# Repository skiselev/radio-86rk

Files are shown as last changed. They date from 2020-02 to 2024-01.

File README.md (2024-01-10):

# Radio 86RK
Re-make of the Soviet Ham Radio computer published in Radio Magazine in 1986

## Hardware Documentation

## Table of Content
* [Introduction](#introduction)
* [Specifications](#specifications)
* [Project Notes](#project-notes)
* [Hardware Documentation](#hardware-documentation)
  * [Schematic and PCB Layout](#schematic-and-pcb-layout)
  * [Connectors](#connectors)
  * [Bill of Materials](#bill-of-materials)
  * [Memory Map](#memory-map)
* [Firmware Documentation](#firmware-documentation)
  * [Monitor](#monitor)
* [Release Notes](#release-notes)
  * [Changes](#changes)
  * [Known Issues](#known-issues)

## Introduction
This project is a remake of [Radio-86RK](https://en.wikipedia.org/wiki/Radio-86RK) - a soviet ham radio computer. The original design was published in Radio Magazine, an amateur radio and DIY electronics oriented publication, starting from [April 1986](Radio-86RK_Publications.md). Hence the "Radio" and "86" in the name ("RK" stands for ham radio computer).

The goal of the original design was to create a computer that can be built relatively easily and cheaply using commonly available components. Therefore it included several short-cuts. For example it didn't use 8228 bus controller. Instead, it uses */WR* and *DBIN* CPU signals instead to distinguish between write and read CPU cycles. Since the system doesn't decode I/O control signals, all the I/O devices are memory mapped. Another optimization is the use of DMA controller for both supplying the data to the CRT controller and for refreshing DRAMs. The system didn't support interrupts. The sound was implemented using *INTE* output of the CPU. The software would use **EI**/**DI** instructions to generate sound. There are no graphics capabilities. The font size was limited to 128 characters (8275 CRT controller limitation), and given that it had to support both Latin and Cyrillic ABCs, it only had capital letters for both ABCs. The CRT controller shares 16 MHz clock oscillator with the CPU (not uncommon in other home computers at that time period).

Despite the limitations, the design was fairly successful, many people have built this computer, and there are some that still building one, this project included. In addtion, several factories manufactured computers based on (but not always compatible with) this design - e.g. [Mikrosha](https://oldcomputer.info/8bit/mikrosha/index.htm), [Apogee BK-01](https://ru.wikipedia.org/wiki/%D0%90%D0%BF%D0%BE%D0%B3%D0%B5%D0%B9_%D0%91%D0%9A-01), and a few more.

### Specifications of the Original Design
  * KR580VM80A (Intel 8080) CPU @ 1.78 MHz (16 MHz divided by 9)
  * 16 KiB to 32 KiB DRAM, 2 KiB ROM (monitor software)
  * KR580VG75 (Intel 8275) CRT controller which works together with KR580VT57 (Intel 8257) DMA controller. 1 KiB ROM is used for font
  * Two KR580VV55A (Intel 8255A) PPIs. One is used for keyboard and cassette I/O, another one for the extension port
  * Normally the computer consisted of 2 or 3 PCBs - the mainboard, the keyboard, and the keypad.

### Modifications to the Original Design
 * 16 DRAM ICs replaced with a single 32 KiB SRAM IC
 * Font ROM size increased to 2 KiB, so that it fits an alternative font. CRT controller GPA0 attribute is used to switch between fonts.
 * Reverse video attribute implemented in CRT controller
 * Added 8251 USART and 8253 timer. The timer is used for dividing the clock for USART and for sound generation.
 * Single board design, including an integrated mechanical keyboard
 * The work is largely based on [Radio-86RК-SRAM](http://radio86rk.pbworks.com/w/page/58467718/Radio-86R%D0%9A-SRAM) project created by Alexey Khudyakov (alexcp).

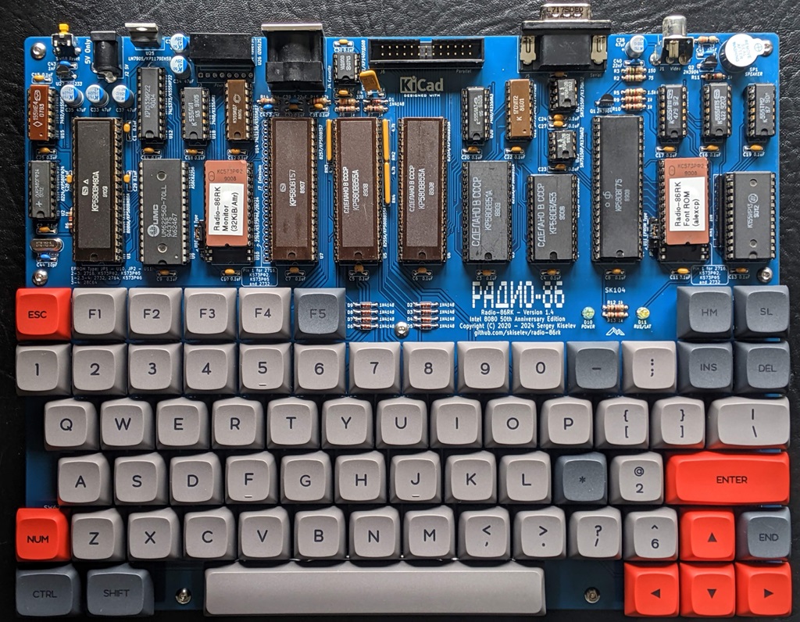
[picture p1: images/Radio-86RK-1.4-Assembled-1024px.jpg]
Radio-86RK


## Specifications
* Processor: Intel 8080A / КР580ВМ80А CPU running at 1.78 MHz
* Memory:
  * RAM: 32 KiB SRAM
  * ROM: 2 KiB UV EPROM with system monitor software
* Video: Intel 8275 / КР580ВГ75 CRT Controller
  * Alphanumeric display
  * 2 KiB UV EPROM with font
  * Composite video output (50 Hz)
* Audio:
  * Intel 8253 / КР580ВИ53 (single channel)
  * CPU INTE output
* Parallel Interface:
  * Intel 8255А / КР580ВВ55А PPI
  * 26-pin expansion header
* Serial Interface:
  * Intel 8251А / КР580ВВ51А USART
  * DE-9 connector
* Built-in 67-keys keyboard
* Cassette recorder interface

## Project Notes

Check [Project Notes](Project_Notes.md) for the information about building this project

## Hardware Documentation

### Documentation for the Previous Versions

* [Version 1.3](https://github.com/skiselev/radio-86rk/tree/v1.3)
* [Version 1.2](https://github.com/skiselev/radio-86rk/tree/v1.2)
* [Version 1.1](https://github.com/skiselev/radio-86rk/tree/v1.1)

### Schematic and PCB Layout

* [Schematic - Version 1.4](KiCad/Radio-86RK-Schematic-1.4.pdf)
* [PCB Layout - Version 1.4](KiCad/Radio-86RK-Board-1.4.pdf)

### Connectors

#### J1 - Composite Video

Pin | Description     
--- | ---------------
Tip (the inner contact) | Output: Composite Video
Ring / Sleeve         |	Power: GND

#### J2 - Power (5V)
Connect regulated +5V power supply to this connector.

Note: The 8080A CPU, clock generator, and serial port transmitters and receivers use +12V/-5V/-12V voltages. An on-board DC-DC converter (U26) is used to obtain these voltages. Instead of using the DC-DC converter it is possible to provide these voltages directly to the system using J3 connector.

Pin | Description     
--- | ---------------
Tip (the inner contact) | Power: 5V (positive terminal)
Barrel / Sleeve         |	Power: GND (negative terminal)

#### J3 - Power (5V, 12V, -12V)
Connect regulated 5V/12V/-12V power supply to this connector.

Pin | Description     
--- | ---------------
1, 2, 3 | Power: GND
4, 5, 6 |	Power: 5V
7   |	Power: 12V
8   |	Power: -12V

#### J4 - Cassette Connector
Pin | Description     
--- | ---------------
1, 2, 3, 8   | Power: GND
4   |	Output: Sound output to cassette recorder (line level)
5   |	Input: Sound input from cassette recorder (line level)
6, 7 |	Not connected

#### J5 - Serial Port Connector
Pin | Description     
--- | ---------------
1   | Not connected: DCD
2   | Input: RX
3   | Output: TX
4   | Output: DTR
5   | Power: GND
6   | Input: DSR
7   | Output: RTS
8   | Input: CTS
9   | Not connected: RI

#### J6 - Parallel Port Connector
Pin | Description | Pin | Description
--- | ----------- | --- | ----------------
1   | Output: PC0 | 2   | Input: PA0
3   | Output: PC1 | 4   | Input: PA1
5   | Output: PC2 | 6   | Input: PA2
7   | Output: PC3 | 8   | Input: PA3
9   | Output: PC4 | 10  | Input: PA4
11  | Output: PC5 | 12  | Input: PA5
13  | Output: PC6 | 14  | Input: PA6
15  | Output: PC7 | 16  | Input: PA7
17  | Output: PB7 | 18  | Output: PB0
19  | Output: PB6 | 20  | Output: PB1
21  | Output: PB5 | 22  | Output: PB2
23  | Output: PB4 | 24  | Output: PB3
25  | Power: +5V  | 26  | Power: GND

### Bill of Materials

* [Radio-86RK project on Mouser.com](https://www.mouser.com/ProjectManager/ProjectDetail.aspx?AccessID=d3d8f92a02) - View and order all components except of the PCB, and most Intel 8xxx ICs.

* [Unicorn Electronics](https://www.unicornelectronics.com/prod.htm) is a good source for Intel 8xxx or compatible ICs, 7400-series TTL ICs, and 74LS00-series TTL-LS ICs

Component type     | Reference | Description                                 | Quantity | Possible sources and notes
------------------ | --------- | ------------------------------------------- | -------- | --------------------------
PCB                |           | Radio-86RK PCB                              | 1        | Buy from my Tindie store: [Radio-86RK - PCB](https://www.tindie.com/products/weird/radio-86rk-pcb/) or order from a PCB manufacturer of your choice using provided Gerber or KiCad files
Capacitor          | C1 - C32  | 0.1 uF, MLCC, 5 mm Pitch                    | 32       | Mouser [594-K104K15X7RF53H5](https://www.mouser.com/ProductDetail/594-K104K15X7RF53H5)
Capacitor          | C33 - C38 | 47 uF, 25V, Electrolytic or Organic Polymer | 6 	      | Mouser [80-A750EK476M1EAAE40](https://www.mouser.com/ProductDetail/80-A750EK476M1EAAE40)
Capacitor          | C39       | 0.22 uF, MLCC, 5 mm Pitch                   | 1        | Mouser [810-FG24X7R1H224KNT0](https://www.mouser.com/ProductDetail/810-FG24X7R1H224KNT0)
Capacitor          | C40       | 22 nF, MLCC, 5 mm Pitch                     | 1        | Mouser [810-FG28X7R1H223KNT0](https://www.mouser.com/ProductDetail/810-FG28X7R1H223KNT0)
Capacitor          | C41       | 10 nF, MLCC, 5 mm Pitch                     | 1        | Mouser [810-FG28X7R1H103KNT0](https://www.mouser.com/ProductDetail/810-FG28X7R1H103KNT0)
Capacitor          | C42       | 2.2 nF, MLCC, 5 mm Pitch                    | 1        | Mouser [810-FG28X7R1H222KNT0](https://www.mouser.com/ProductDetail/810-FG28X7R1H222KNT0)
Capacitor          | C43       | 1 nF, MLCC, 5 mm Pitch                      | 1        | Mouser [810-FG28C0G1H102JNT6](https://www.mouser.com/ProductDetail/810-FG28C0G1H102JNT6)
Capacitor          | C44       | 10 pF, MLCC, 5 mm Pitch                     | 1        | Mouser [810-FG28C0G1H100DNT00](https://www.mouser.com/ProductDetail/810-FG28C0G1H100DNT0)
Diode              | D1 - D9  | 1N4148                                       | 9        | Mouser [512-1N4148](https://www.mouser.com/ProductDetail/512-1N4148)
LED                | D10       | LED Indicator, 3 mm, Green                  | 1        | Mouser [630-HLMP-1503-C0002](https://www.mouser.com/ProductDetail/630-HLMP-1503-C0002)
LED                | D11       | LED Indicator, 3 mm, Yellow                 | 1        | Mouser [630-HLMP-1401](https://www.mouser.com/ProductDetail/630-HLMP-1401)
Polyfuse           | F1        | 1.1A, 5 mm Pitch                            | 1        | Mouser [576-16R110BU](https://www.mouser.com/ProductDetail/576-16R110BU)
Connector          | JP1, JP2  | 4 pin header, 2.54 mm Pitch                 | 2        | Mouser [649-68000-204HLF](https://www.mouser.com/ProductDetail/649-68000-204HLF)
Connector          | JP1, JP2  | Jumper, 2.54 mm Pitch                       | 4        | Mouser [806-SX1100-B)](https://www.mouser.com/ProductDetail/806-SX1100-B)
Connector          | J1        | RCA Phono connector, Yellow                 | 1        | Mouser [490-RCJ-014](https://www.mouser.com/ProductDetail/490-RCJ-014)
Connector          | J2        | DC Power Jack, 2mm                          | 1        | Mouser [806-KLDX-0202-A](https://www.mouser.com/ProductDetail/806-KLDX-0202-A)
Connector          | J3        | 8 pin friction lock connector               | 1        | Mouser [571-6404568](https://www.mouser.com/ProductDetail/571-6404568)
Connector          | J4        | DIN 8-pos, Right Angle, PCB mount           | 1        | Mouser [490-SDF-80J](https://www.mouser.com/ProductDetail/490-SDF-80J)
Connector          | J5        | Sub-D DE9M, Right Angle, PCB mount          | 1        | Mouser [523-L717SDE09P1ACH3R](https://www.mouser.com/ProductDetail/523-L717SDE09P1ACH3R)
Connector          | J6        | 13x2 pin header, shrouded                   | 1        | Mouser [517-30326-6002](https://www.mouser.com/ProductDetail/517-30326-6002)
Connector          | J7        | 20x1 pin socket                             | 1        | Mouser [517-929850-01-20-RB](https://www.mouser.com/ProductDetail/517-929850-01-20-RB). Note: Optional, for extension board connection
Transistor         | Q1, Q2    | 2N3904                                      | 2        | Mouser [512-2N3904TA](https://www.mouser.com/ProductDetail/512-2N3904TA)
Resistor           | R1        | 33 ohm                                      | 1        | Mouser [660-CF1/4CT52R330J](https://www.mouser.com/ProductDetail/660-CF1-4CT52R330J)
Resistor           | R2        | 75 ohm                                      | 1        | Mouser [660-CF1/4CT52R750J](https://www.mouser.com/ProductDetail/660-CF1-4CT52R750J)
Resistor           | R3        | 150 ohm                                     | 1        | Mouser [660-CF1/4CT52R151J](https://www.mouser.com/ProductDetail/660-CF1-4CT52R151J)
Resistor           | R4        | 330 ohm                                     | 1        | Mouser [660-CF1/4CT52R331J](https://www.mouser.com/ProductDetail/660-CF1-4CT52R331J)
Resistor           | R5        | 1.5 k                                       | 1        | Mouser [660-CF1/4CT52R152J](https://www.mouser.com/ProductDetail/660-CF1-4CT52R152J)
Resistor           | R6 - R13  | 1 k                                         | 8        | Mouser [660-CF1/4CT52R102J](https://www.mouser.com/ProductDetail/660-CF1-4CT52R102J)
Resistor           | R14       | 2.4 k                                       | 1        | Mouser [660-CF1/4CT52R242J](https://www.mouser.com/ProductDetail/660-CF1-4CT52R242J)
Resistor           | R15       | 12 k                                        | 1        | Mouser [660-CF1/4CT52R123J](https://www.mouser.com/ProductDetail/660-CF1-4CT52R123J)
Resistor Array     | RN1       | 10 k, SIP10                                 | 1        | Mouser [652-4610X-1LF-10K](https://www.mouser.com/ProductDetail/652-4610X-1LF-10K)
Resistor Array     | RN2 - RN4 | 4.7 k, SIP6                                 | 3        | Mouser [652-4606X-1LF-4.7K](https://www.mouser.com/ProductDetail/652-4606X-1LF-4.7K)
Speaker            | SP1       | 12 mm speaker                               | 1        | Mouser [665-AT-1224TWTR](https://www.mouser.com/ProductDetail/665-AT-1224TWTR)
Keyboard Switch    | SW1 - SW67 | Cherry MX Blue (Clicky)                    | 67       | Mouser [540-MX1A-E1NW](https://www.mouser.com/ProductDetail/540-MX1A-E1NW)
Switch Leveling Kit | SW11, SW64 | Leveling kit for MX 1x2, 1x2.25, 1x2.75   | 2        | Mouser [540-G99-0742](https://www.mouser.com/ProductDetail/540-G99-0742)
Switch Leveling Kit | SW64     | Leveling kit for MX 1x8                     | 1        | Mouser [540-G99-0226](https://www.mouser.com/ProductDetail/540-G99-0226) Note: Use the wire from this part and one of 540-G99-0742 to build a through hole leveling kit for the spacebar
Tactile Switch     | SW68      | 6 mm Tactile Switch Right Angle             | 1        | Mouser [653-B3F-3152](https://www.mouser.com/ProductDetail/653-B3F-3152)
Switch Keycap      | SW68      | 4 x 4 mmm Tactile Switch Key Cap, Orange    | 1        | Mouser [653-B32-1020](https://www.mouser.com/ProductDetail/653-B32-1020)
Integrated Circuit | U1        | Intel 8080A / КР580ВМ80А, CPU               | 1        | Unicorn Electronics [8080A](https://www.unicornelectronics.com/IC/8000.html), Jameco [52046](https://www.jameco.com/z/8080A-Major-Brands-IC-8080A-8-Bit-MOS-MPU_52046.html)
Integrated Circuit | U2        | Intel 8224 / КР580ГФ24, Clock Generator     | 1        | Unicorn Electronics [8224](https://www.unicornelectronics.com/IC/8000.html)
Integrated Circuit | U3        | Intel 8251А / КР580ВВ51А, USART             | 1        | Unicorn Electronics [8251A](https://www.unicornelectronics.com/IC/8000.html)
Integrated Circuit | U4        | Intel 8253 / КР580ВИ53, PIT                 | 1        | Unicorn Electronics [8253](https://www.unicornelectronics.com/IC/8000.html), Mouser [968-CP82C54Z](https://www.mouser.com/ProductDetail/968-CP82C54Z)
Integrated Circuit | U5, U6    | Intel 8255А / КР580ВВ55А, PPI               | 2        | Unicorn Electronics [8055A](https://www.unicornelectronics.com/IC/8000.html), Mouser [968-CP82C55A-5Z](https://www.mouser.com/ProductDetail/968-CP82C55A-5Z), Jameco [52732](https://www.jameco.com/z/8255A-5-Major-Brands-IC-8255A-5-Programmable-Peripheral-Interface-40-pin-DIP_52732.html)
Integrated Circuit | U7        | Intel 8257 / КР580ВТ57, DMA Controller      | 1        | Unicorn Electronics [8257](https://www.unicornelectronics.com/IC/8000.html)
Integrated Circuit | U8        | Intel 8275 / КР580ВГ75, CRT Controller      | 1        | Unicorn Electronics [8275](https://www.unicornelectronics.com/IC/8000.html), Jameco [52821](https://www.jameco.com/z/8275-Major-Brands-Programmable-CRT-Controller-DIP-40_52821.html)
Integrated Circuit | U9        | AS6C62256, SRAM 32Kx8                       | 1        | Mouser [913-AS6C62256-55PCN](https://www.mouser.com/ProductDetail/913-AS6C62256-55PCN), Unicorn Electronics [62256LP](https://www.unicornelectronics.com/IC/STATIC.html)
Integrated Circuit | U10, U11  | 2716 / КР573РФ5, 2Kx8 EPROM                 | 2        | Mouser [556-AT28C64B15PU](https://www.mouser.com/ProductDetail/556-AT28C64B15PU), Unicorn Electronics [2716](https://www.unicornelectronics.com/IC/EPROM.html). Note: 2716, 2732, 2764, 27C64 EPROMs, or 28C64 EEPROMs can be used
Integrated Circuit | U12       | 74LS373/К555ИР22, 8-bit Latch, 3-state outputs | 1     | Mouser [595-SN74LS373N](https://www.mouser.com/ProductDetail/595-SN74LS373N)
Integrated Circuit | U13       | 74198/К155ИР13, 8-bit Shift Register        | 1        | Unicorn Electronics [74198](https://www.unicornelectronics.com/IC/7400.html)
Integrated Circuit | U14       | 74LS138/К555ИД7, Decoder 3 to 8 active low outputs | 1 | Mouser [595-SN74LS138N](https://www.mouser.com/ProductDetail/595-SN74LS138N), Unicorn Electronics [74LS138](https://www.unicornelectronics.com/IC/74LS.html)
Integrated Circuit | U15       | 7492/К155ИЕ4, Divide by 12 counter          | 1        | Mouser [595-SN74LS92N](https://www.mouser.com/ProductDetail/595-SN74LS92N), Unicorn Electronics [74LS92](https://www.unicornelectronics.com/IC/74LS.html)
Integrated Circuit | U16       | 7486/К155ЛП5, Quad 2-input XOR              | 1        | Mouser [595-SN74LS86AN](https://www.mouser.com/ProductDetail/595-SN74LS86AN), Unicorn Electronics [74LS86](https://www.unicornelectronics.com/IC/74LS.html)
Integrated Circuit | U17       | 7474/К155ТМ2, Dual D Flip-flop, Set & Reset | 1        | Mouser [595-SN74LS74AN](https://www.mouser.com/ProductDetail/595-SN74LS74AN), Unicorn Electronics [74LS74](https://www.unicornelectronics.com/IC/74LS.html)
Integrated Circuit | U18       | 7408/К155ЛИ1, Quad 2-input AND              | 1        | Mouser [595-SN74LS08N](https://www.mouser.com/ProductDetail/595-SN74LS08N), Unicorn Electronics [74LS08](https://www.unicornelectronics.com/IC/74LS.html)
Integrated Circuit | U19       | 7404/К155ЛН1, Hex Inverter                  | 1        | Mouser [595-SN74LS04N](https://www.mouser.com/ProductDetail/595-SN74LS04N), Unicorn Electronics [74LS04](https://www.unicornelectronics.com/IC/74LS.html)
Integrated Circuit | U20       | 7400/К155ЛА3, Quad 2-input NAND             | 1        | Mouser [595-SN74LS00N](https://www.mouser.com/ProductDetail/595-SN74LS00N), Unicorn Electronics [74LS00](https://www.unicornelectronics.com/IC/74LS.html)
Integrated Circuit | U21       | TL071/К140УД6, Operational Amplifier        | 1        | Mouser [595-TL071IP](https://www.mouser.com/ProductDetail/595-TL071IP)
Integrated Circuit | U22       | SN75154N/К170УП2В, Quad RS-232 Receiver     | 1        | Mouser [595-SN75154N](https://www.mouser.com/ProductDetail/595-SN75154N), Unicorn Electronics [75154](https://www.unicornelectronics.com/IC/INTERFACE.html)
Integrated Circuit | U23, U24  | SN75150P/К170АП2, Dual RS-232 Driver        | 2        | Mouser [595-SN75150P](https://www.mouser.com/ProductDetail/595-SN75150P), Unicorn Electronics [75150](https://www.unicornelectronics.com/IC/INTERFACE.html)
Integrated Circuit | U25       | LM7905/КР1179ЕНВ, Negative 5V 1A Linear Regulator | 1  | Mouser [926-LM7905CT-NOPB](https://www.mouser.com/ProductDetail/926-LM7905CT-NOPB), Unicorn Electronics [7905T](https://www.unicornelectronics.com/IC/VOLT.html)
DC-DC Converter    | U26       | IZ0512, +/-12V +/-125mA, 4.5V-9V input      | 1        | Mouser [209-IZ0512S](https://www.mouser.com/ProductDetail/209-IZ0512S)
Integrated Circuit | U27       | DS1233-5, CPU Supervisory Circuit           | 1        | Mouser [700-DS1233-5T&R](https://www.mouser.com/ProductDetail/700-DS1233-5TR)
Crystal            | Y1        | 16 MHz, Series, HC-49U                      | 1        | Mouser [774-ATS160-E](https://www.mouser.com/ProductDetail/774-ATS160-E)
IC Socket          | U1, U5, U6, U7, U8 | 40 pin DIP                         | 5        | Mouser [649-DILB40P223TLF](https://www.mouser.com/ProductDetail/649-DILB40P223TLF), [517-4840-6000-CP](https://www.mouser.com/ProductDetail/517-4840-6000-CP)
IC Socket          | U3, U9, U10, U11    | 28 pin DIP                                  | 4        | Mouser [649-DILB28P223TLF](https://www.mouser.com/ProductDetail/649-DILB28P223TLF), [517-4828-6000-CP](https://www.mouser.com/ProductDetail/517-4828-6000-CP)
IC Socket          | U4, U13   | 24 pin DIP                          | 2        | Mouser [649-DILB24P-223TLF](https://www.mouser.com/ProductDetail/649-DILB24P-223TLF), [517-4824-6000-CP](https://www.mouser.com/ProductDetail/517-4824-6000-CP)
IC Socket          | U12       | 20 pin DIP                                  | 1        | Mouser [649-DILB20P-223TLF](https://www.mouser.com/ProductDetail/649-DILB20P-223TLF), [517-4820-3000-CP](https://www.mouser.com/ProductDetail/517-4820-3000-CP)
IC Socket          | U2, U14, U22 | 16 pin DIP                               | 3        | Mouser [649-DILB16P-223TLF](https://www.mouser.com/ProductDetail/649-DILB16P-223TLF), [517-4816-3000-CP](https://www.mouser.com/ProductDetail/517-4816-3000-CP)
IC Socket          | U15 - U20 | 14 pin DIP                                  | 6        | Mouser [649-DILB14P-223TLF](https://www.mouser.com/ProductDetail/649-DILB14P-223TLF), [517-4814-3000-CP](https://www.mouser.com/ProductDetail/517-4814-3000-CP)
IC Socket          | U21, U23, U24 | 8 pin DIP                               | 3        | Mouser [649-DILB8P223TLF](https://www.mouser.com/ProductDetail/649-DILB8P223TLF), [517-4808-3000-CP](https://www.mouser.com/ProductDetail/517-4808-3000-CP)

### Memory Map
* 0000h - 7FFFh - SRAM
  * 7600h - 7FFFh - Display buffer and monitor variables
* 8000h - 8FFFh - 8255A PPI (Keyboard, Cassette recorder, Sound control)
  * 8000h - Channel A data
  * 8001h - Channel B data
  * 8002h - Channel C data
  * 8003h - Control word
* 9000h - 9FFFh - 8253 Timer (USART Clock, Sound)
  * 9000h - Channel 0 count
  * 9001h - Channel 1 count
  * 9002h - Channel 2 count
  * 9003h - Control word
* 0A000h - 0AFFFh - 8255A PPI (Parallel Interface)
  * 0A000h - Channel A data
  * 0A001h - Channel B data
  * 0A002h - Channel C data
  * 0A003h - Control word
* 0B000h - 0BFFFh - 8251A USART
  * 0B000h - Data register
  * 0B001h - Command register
* 0C000h - 0CFFFh - 8275 CRT Controller
* 0D000h - 0DFFFh - Unused
* 0E000h - 0EFFFh - 8257 DMA Controller (write only)
* 0E000h - 0FFFFh - Monitor EPROM (read only)

## Firmware Documentation

### Monitor

#### Monitor Commands
* Memory Operations
  * **D\<Start_Address\>,\<End_Address\>** - Display memory content in hexadecimal
  * **L\<Start_Address\>,\<End_Address\>** - Display memory content in ASCII
  * **F\<Start_Address\>,\<End_Address\>,\<Value\>** - Fill memory with the specified value
  * **M\<Address\>** - Modify memory content
  * **T\<Start_Address\>,\<End_Address\>,\<Destination_Start_Address\>** - Copy memory block to destination
  * **C\<Start_Address\>,\<End_Address\>,\<Destination_Start_Address\>** - Compare memory block with destination
  * **S\<Start_Address\>,\<End_Address\>,\<Value\>** - Search memory for a value
  * **R\<ROM_Start_Address\>,\<ROM_End_Address\>,\<Destination_Start_Address\>** - Read from the ROM connected to the Parallel interface to memory
* Run Control
  * **G\<Start_Address\>\[,End_Address\]** - Run code, optionally stop at the specified address
  * **X** - Display and modify registers
* Cassette Input/Output
  * **O\<Start_Address\>,\<End_Address\>\[,Speed\]** - Write memory to cassette. Default speed is 1Dh / 1200 bps
  * **I\[Offset\]\[,Speed\]** - Read data from to cassette memory at specified offset

#### Monitor Subroutines:
* 0F803h - Keyboard input
  * Input: None
  * Output: A - character code read from keyboard
* 0F806h - Cassette input
  * Input: A=0FFh - with sync; A=08h - no sync
  * Output: A - data read from cassette
* 0F809h - Print character to screen
  * Input: C - character to print
* 0F80Ch - Cassette output
  * Input: C - data to write
* 0F812h - Query keyboard
  * Output: A=00h - key not pressed; A=0FFh - key pressed
* 0F815h - Print to screen in hex
  * Input: A - data to print
* 0F818h - Print string
  * Input: HL - string address
* 0F81Bh - Get key
  * Output: A=0FFh - key not pressed; A=0FEh - Rus/Lat; otherwise A - key code
* 0F81Eh - Get cursor position
  * Output: H - row, L - column
* 0F821h - Read character from screen at current cursor position
  * Output: A - char read from screen
* 0F824h - Read from cassette
  * Input: HL - offset of memory buffer to store data to
  * Output: HL - start; DE - end; BC - checksum

## Release Notes

### Changes
* Version 1.4
  * Change keyboard layout to QWERTY
  * Add the J7 extension connector
  * Add support for 2732, 2764 and 27C64 EPROMs and 28C64 EEPROM.

* Version 1.3
  * Fix issues from version 1.1 and version 1.2:
    * Use key labels "Ь X" and "СС SHIFT" on top silkscreen
    * Video signal generation circuit: use R2 = 75 Ohm and R5 = 1.5 kOhm
    
* Version 1.2
  * Add F5 key
  * Add copyright year on the top silkscreen

* Version 1.1
  * Fix all known issues of version 1.0
  * Use DS1233-5 mircoprocessor supervisor to generate reset signal
  * Implement reverse video attribute

* Version 1.0
  * Initial version

### Known Issues
* Version 1.3
  * No known issues

* Version 1.2
  * Top silkscreen: "Ь" and "X" key labels are swapped
  * Top silkscreen: More correct translation for "СС" is "SHIFT"
  * Video signal generation: Produced video Vpp and the backporch levels are a bit too high. Use R2 = 75 to 100 Ohm, and R5 = 1.5 kOhm for proper video signal levels (Reported by Martin Lukasek)
* Version 1.1
  * Top silkscreen: "Ь" and "X" key labels are swapped
  * Top silkscreen: More correct translation for "СС" is "SHIFT"
  * Top silkscreen: No copyright year
  * Video signal generation: Produced video Vpp and the backporch levels are a bit too high. Use R2 = 75 to 100 Ohm, and R5 = 1.5 kOhm for proper video signal levels (Reported by Martin Lukasek)

* Version 1.0
  * 8224 (U2) should use DIP-16 footprint
  * Down and Right buttons swapped
  * Reset RC does not provide enough time for the system to properly reset at power-on

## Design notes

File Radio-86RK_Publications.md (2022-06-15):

# Radio Magazine - Radio 86RK Publications

## Table of Content

* [Radio 1985, Issue 1](#radio-1985-issue-1)
  * [BASIC For Micro-80, Part 1](#basic-for-micro-80-part-1)
* [Radio 1985, Issue 2](#radio-1985-issue-2)
  * [BASIC For Micro-80, Part 2](#basic-for-micro-80-part-2)
* [Radio 1985, Issue 3](#radio-1985-issue-3)
  * [BASIC For Micro-80, Part 3](#basic-for-micro-80-part-3)
* [Radio 1986, Issue 3](#radio-1986-issue-3)
  * [BASIC Programming](#basic-programming)
* [Radio 1986, Issue 4](#radio-1986-issue-4)
  * [Computer Architecture](#computer-architecture)
* [Radio 1986, Issue 5](#radio-1986-issue-5)
  * [CPU](#cpu)
  * [Memory and I/O Address Decode, RAM, Mainboard Schematic](#memory-and-io-address-decode-ram-mainboard-schematic)
  * [DMA Controller, CRT Controller, Sound Generation](#dma-controller-crt-controller-sound-generation)
* [Radio 1986, Issue 6](#radio-1986-issue-6)
  * [Keyboard PCB Layout](#keyboard-pcb-layout)
  * [Mainboard PCB Layout](#mainboard-pcb-layout)
  * [Keyboard](#keyboard)
  * [Font ROM Hex Dump, Keyboard Schematic](#font-rom-hex-dump-keyboard-schematic)
  * [Keyboard Layout, Cassette Tape Recorder Interface, Power Supply](#keyboard-layout-cassette-tape-recorder-interface-power-supply)
* [Radio 1986, Issue 8](#radio-1986-issue-8)
  * [Software, ROM Monitor Boot, ROM Monitor CLI, ROM Monitor Memory Commands](#software-rom-monitor-boot-rom-monitor-cli-rom-monitor-memory-commands)
  * [ROM Monitor Hex Dump](#rom-monitor-hex-dump)
  * [ROM Monitor Run and Debug Commands, ROM Monitor I/O Commands](#rom-monitor-run-and-debug-commands-rom-monitor-io-commands)
  * [ROM Monitor Subroutines](#rom-monitor-subroutines)
* [Radio 1986, Issue 9](#radio-1986-issue-9)
  * [Software - ROM Monitor Changes for 32 KiB RAM, Keyboard Notes, Display Control Codes ](#software---rom-monitor-changes-for-32-kib-ram-keyboard-notes-display-control-codes)
* [Radio 1986, Issue 11](#radio-1986-issue-11)
  * [Power Supply - Schematic and Design Description](#power-supply---schematic-and-design-description)
* [Radio 1986, Issue 12](#radio-1986-issue-12)
  * [Power Supply - PCB and Assembly Instructions](#power-supply---pcb-and-assembly-instructions)
  * [Assembly Notes and Errata](#assembly-notes-and-errata)
* [Radio 1987, Issue 1](#radio-1987-issue-1)
  * [BASIC Interpreter](#basic-interpreter)
* [Radio 1987, Issue 2](#radio-1987-issue-2)
  * [BASIC Games - Intersceptor, Joystick-like Control](#basic-games---intersceptor-joystick-like-control)
  * [BASIC Games - Python/Snake](#basic-games---pythonsnake)
* [Radio 1987, Issue 3](#radio-1987-issue-3)
  * [BASIC Games - Fox Hunt](#basic-games---fox-hunt)
  * [ROM cartridge for BASIC Interpreter](#rom-cartridge-for-basic-interpreter)
* [Radio 1987, Issue 4](#radio-1987-issue-4)
  * [Programming Radio-86RK, Python/Snake Game](#programming-radio-86rk-pythonsnake-game)
  * [Cassette Tape Recorder Input / Output](#cassette-tape-recorder-input--output)
* [Radio 1987, Issue 5](#radio-1987-issue-5)
  * [Reference Tables - Intel 8080A (KR580VM80A) Instruction Set, Character Set](#reference-tables---intel-8080a-kr580vm80a-instruction-set-character-set)
  * [Replacing Intel 8275 (KR580VG75) with Discrete Logic](#replacing-intel-8275-kr580vg75-with-discrete-logic)
* [Radio 1987, Issue 11](#radio-1987-issue-11)
  * [Using Intel 8253 (KR580VI53) as a Sound Generator](#using-intel-8253-kr580vi53-as-a-sound-generator)
* [Radio 1989, Issue 6](#radio-1989-issue-6)
  * [Serial Interface Controller Based on Intel 8251A (KR580VV51A) - Design Description, Schematic and PCB Layout](#serial-interface-controller-based-on-intel-8251a-kr580vv51a---design-description-schematic-and-pcb-layout)
* [Radio 1989, Issue 7](#radio-1989-issue-7)
  * [Serial Interface Controller Based on Intel 8251A (KR580VV51A) - Software Subroutines](#serial-interface-controller-based-on-intel-8251a-kr580vv51a---software-subroutines)

## Radio 1985, Issue 1

### BASIC For Micro-80, Part 1

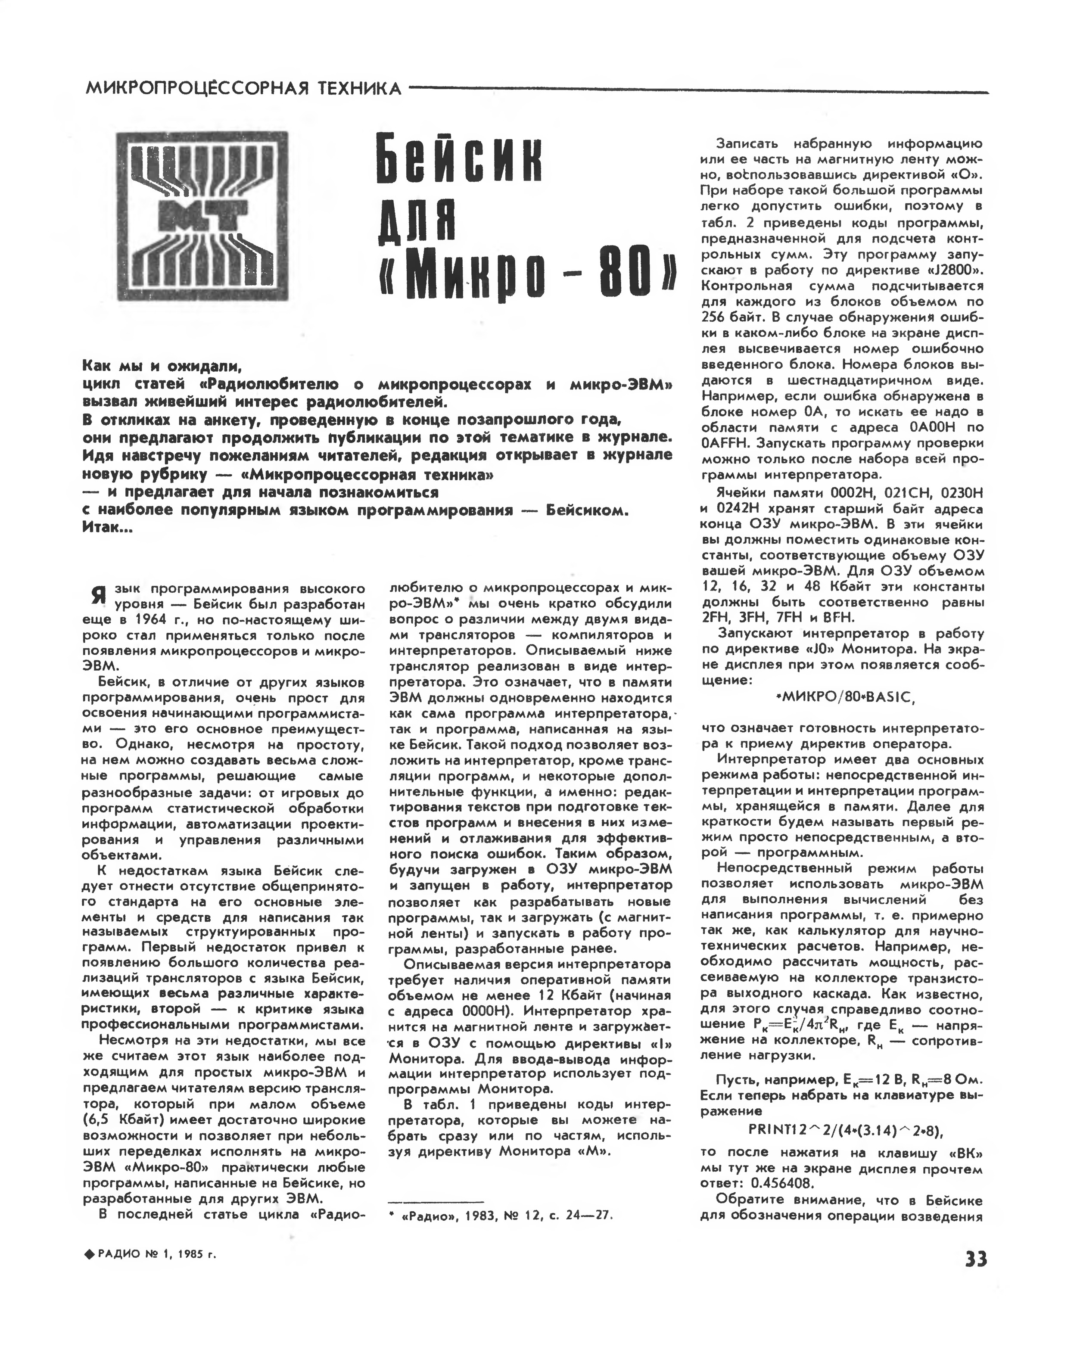
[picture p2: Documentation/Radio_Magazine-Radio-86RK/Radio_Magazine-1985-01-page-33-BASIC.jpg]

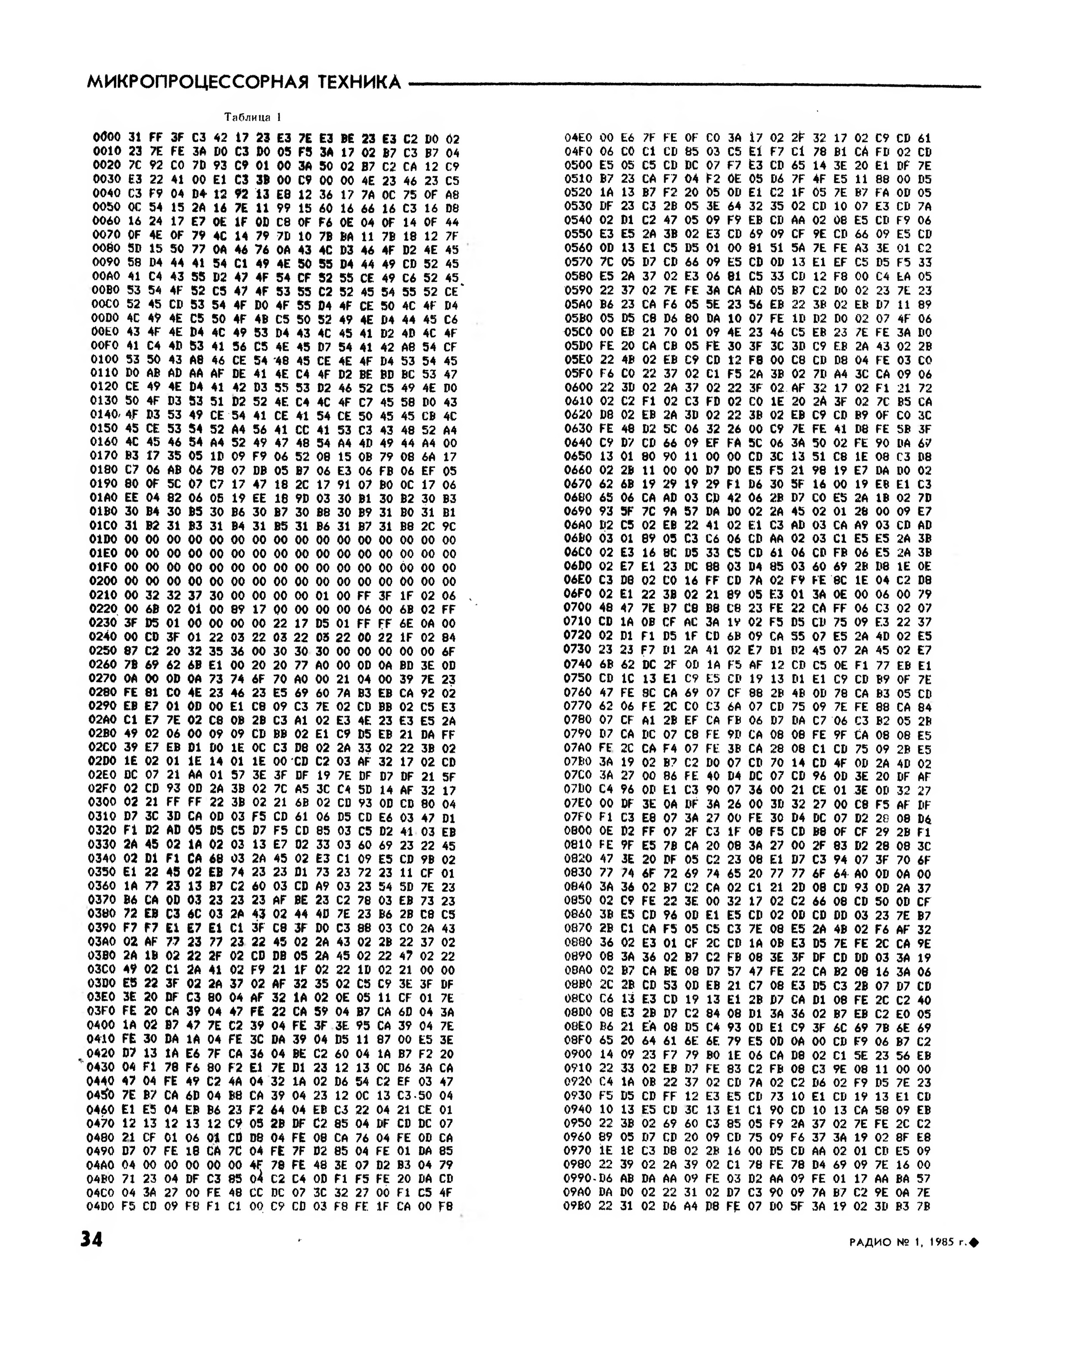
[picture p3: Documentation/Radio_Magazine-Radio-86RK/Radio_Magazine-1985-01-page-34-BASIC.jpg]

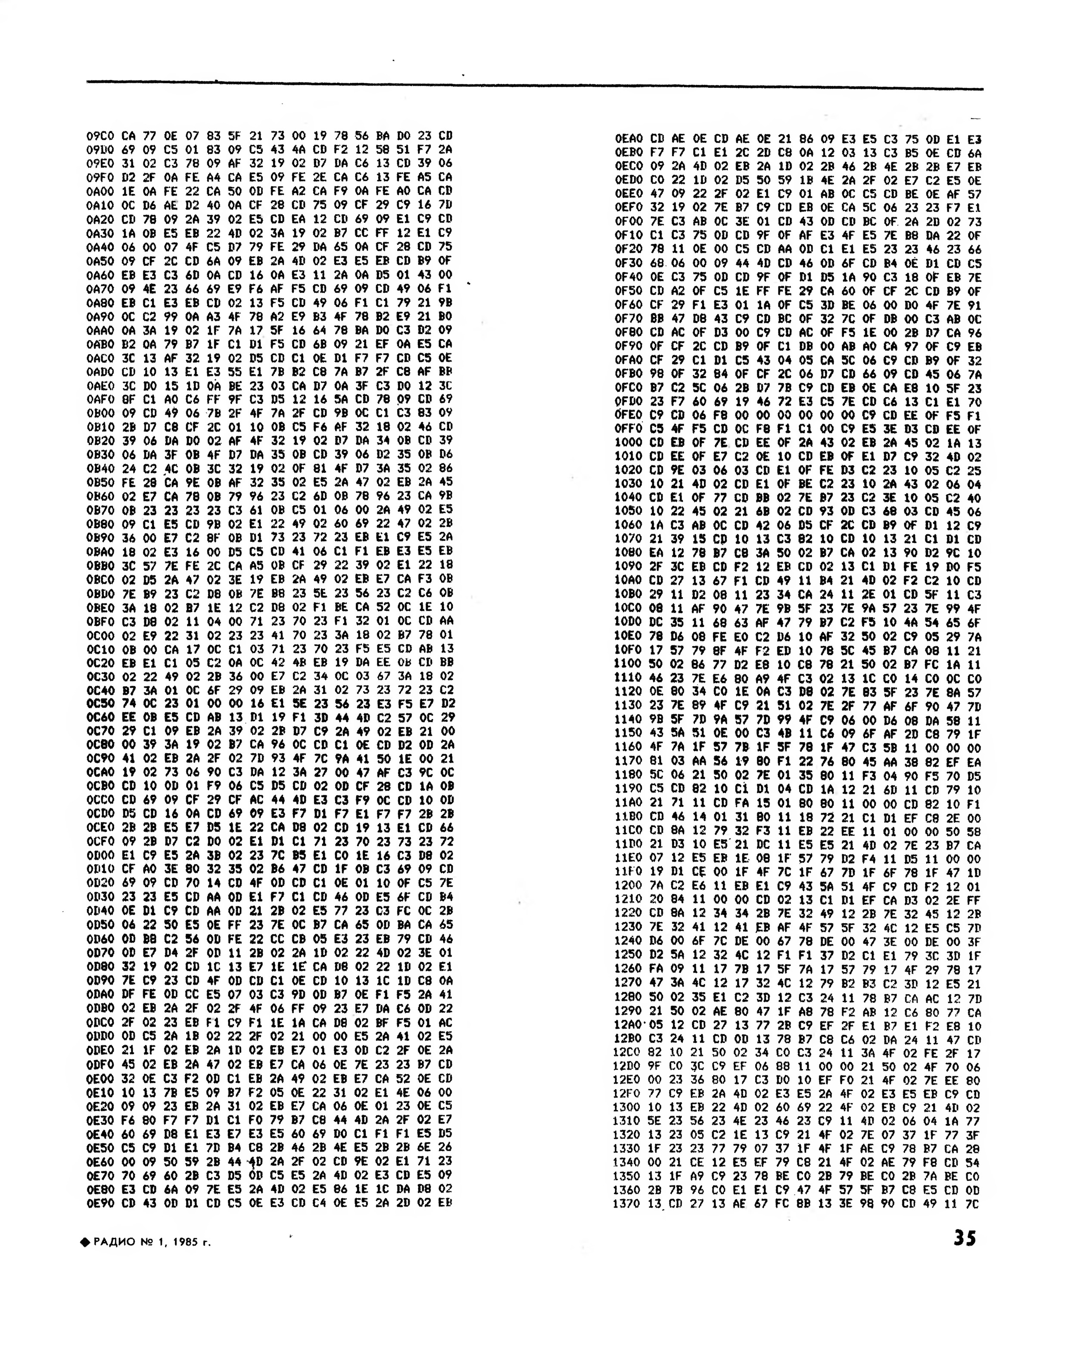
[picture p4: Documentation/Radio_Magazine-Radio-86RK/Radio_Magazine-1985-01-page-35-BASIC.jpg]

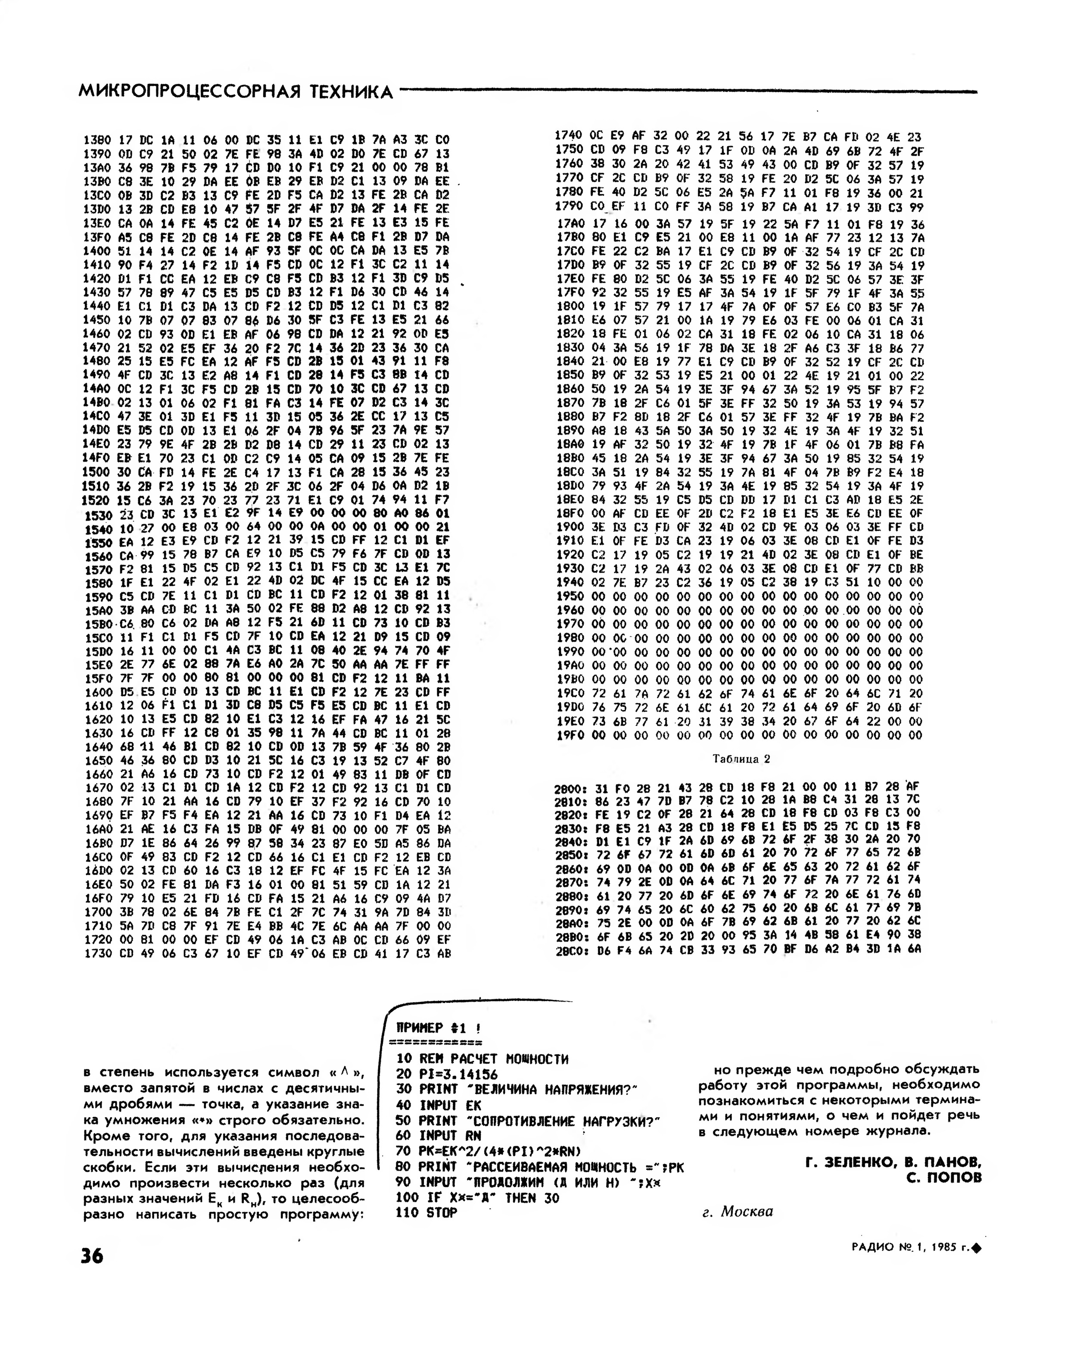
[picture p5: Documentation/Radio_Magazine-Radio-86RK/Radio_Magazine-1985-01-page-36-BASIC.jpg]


## Radio 1985, Issue 2

### BASIC For Micro-80, Part 2

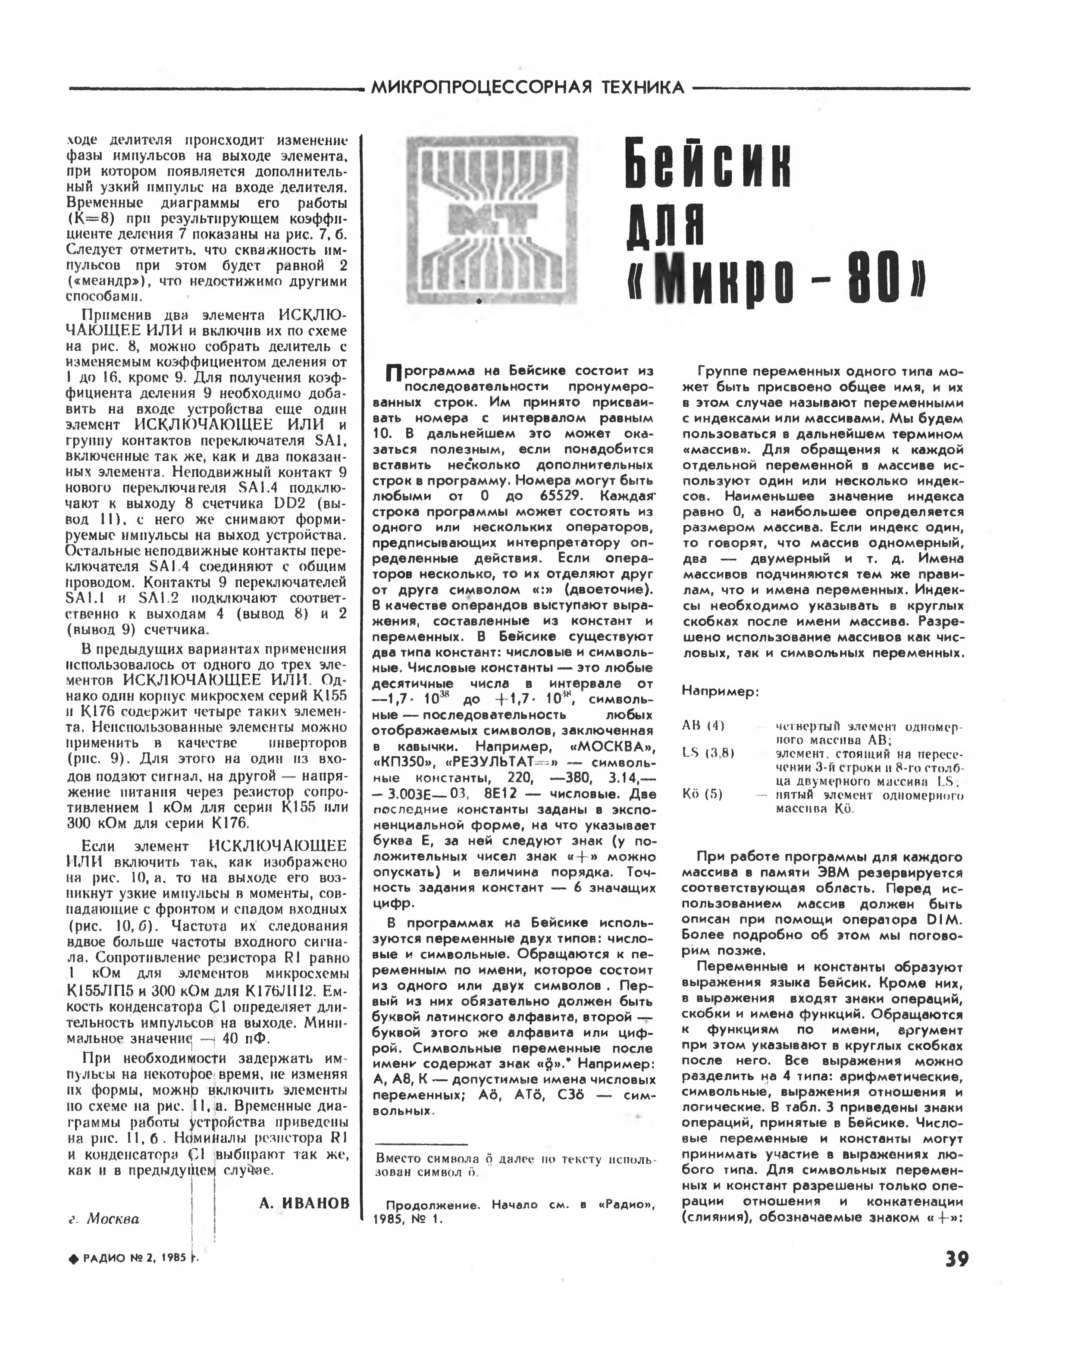
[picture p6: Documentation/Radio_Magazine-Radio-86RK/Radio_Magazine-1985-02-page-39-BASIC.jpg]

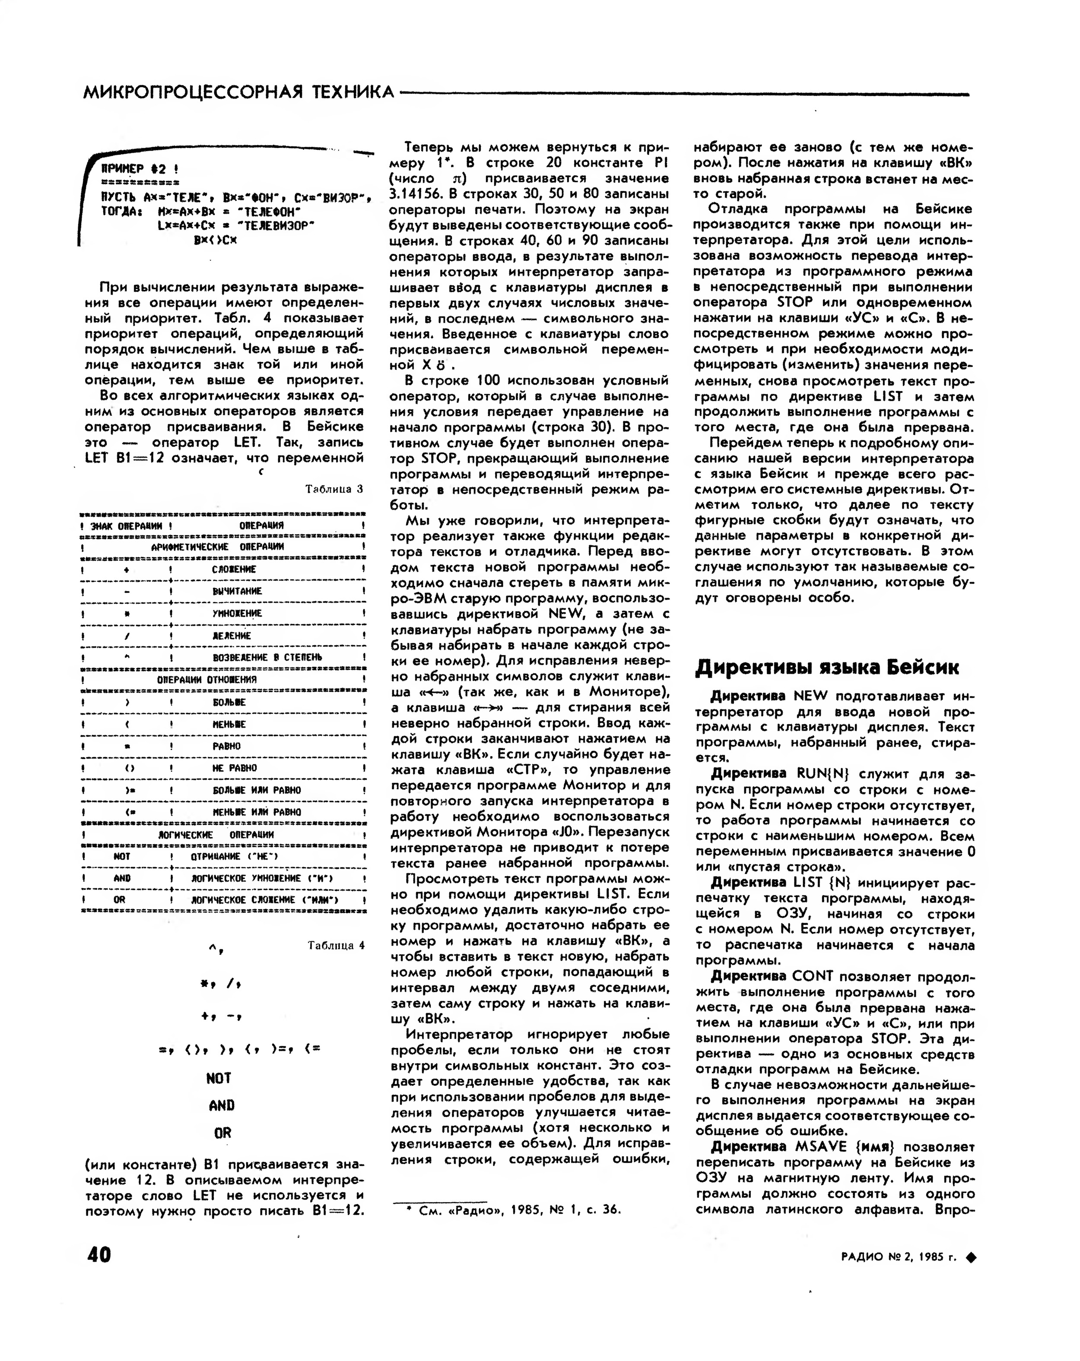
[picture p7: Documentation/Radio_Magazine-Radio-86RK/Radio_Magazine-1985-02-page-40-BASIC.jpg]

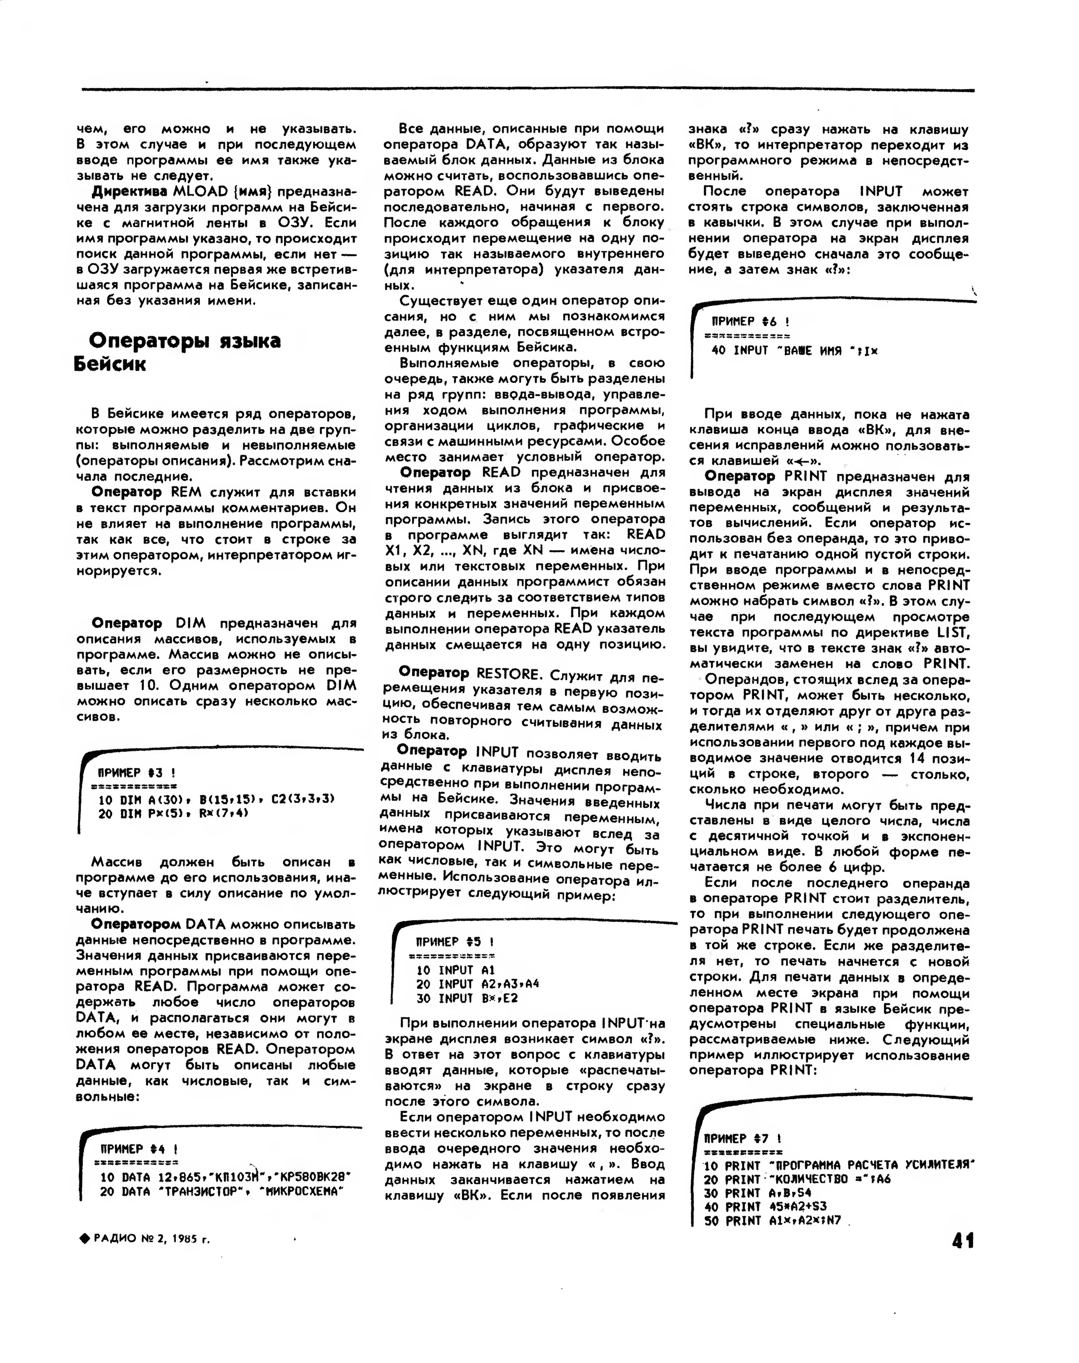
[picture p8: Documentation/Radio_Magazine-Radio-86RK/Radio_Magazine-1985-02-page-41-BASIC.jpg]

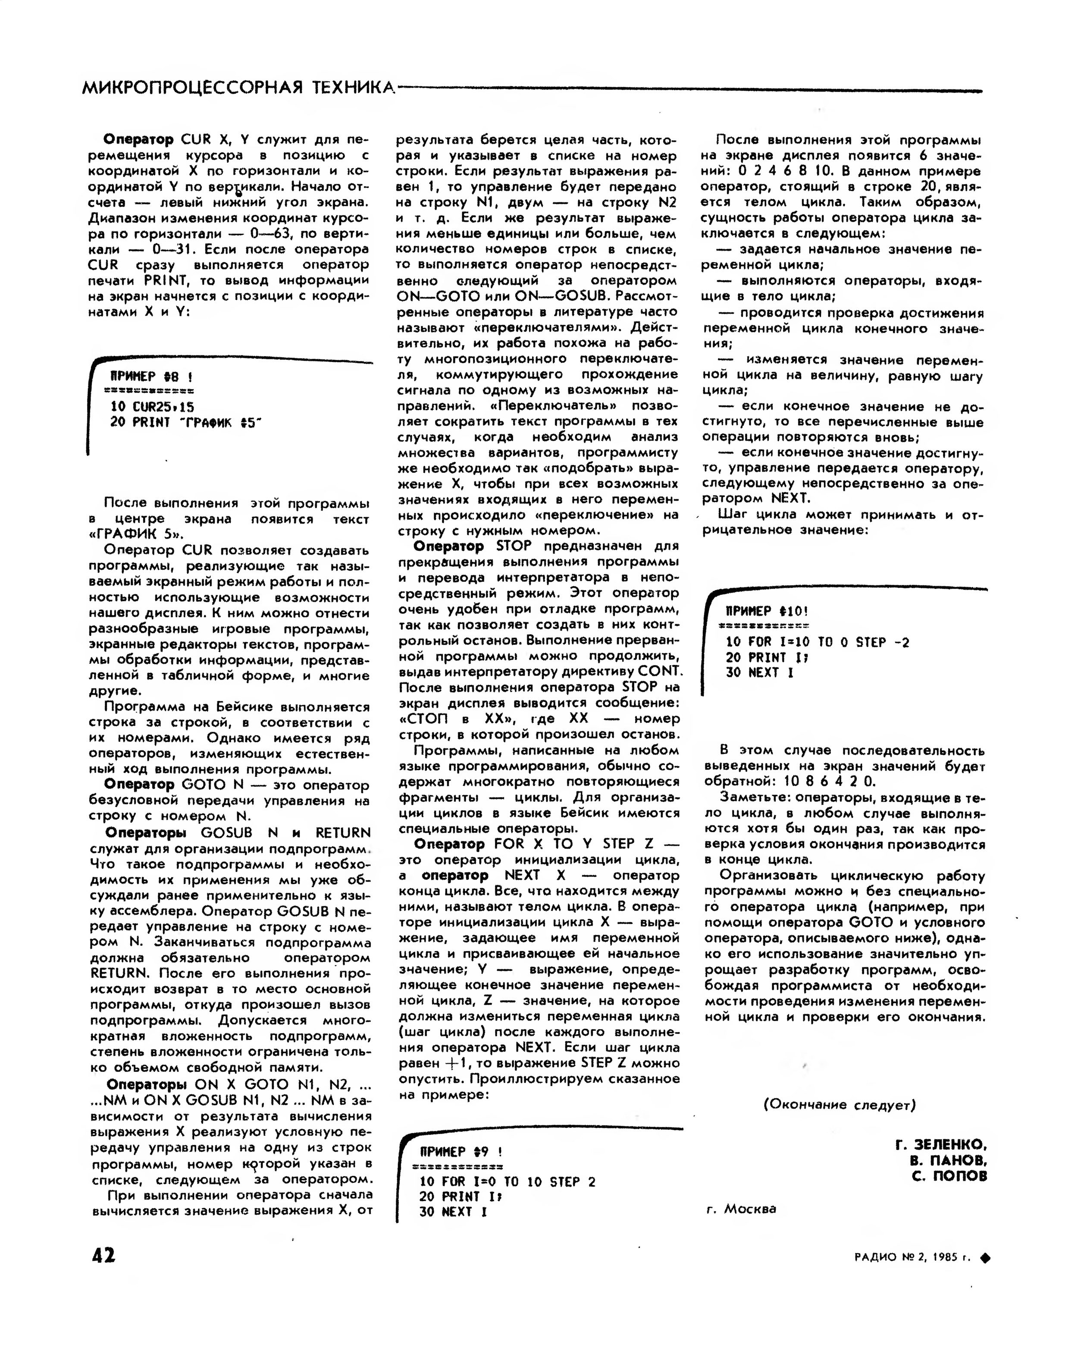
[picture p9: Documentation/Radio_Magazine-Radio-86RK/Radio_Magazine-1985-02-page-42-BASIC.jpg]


## Radio 1985, Issue 3

### BASIC For Micro-80, Part 3

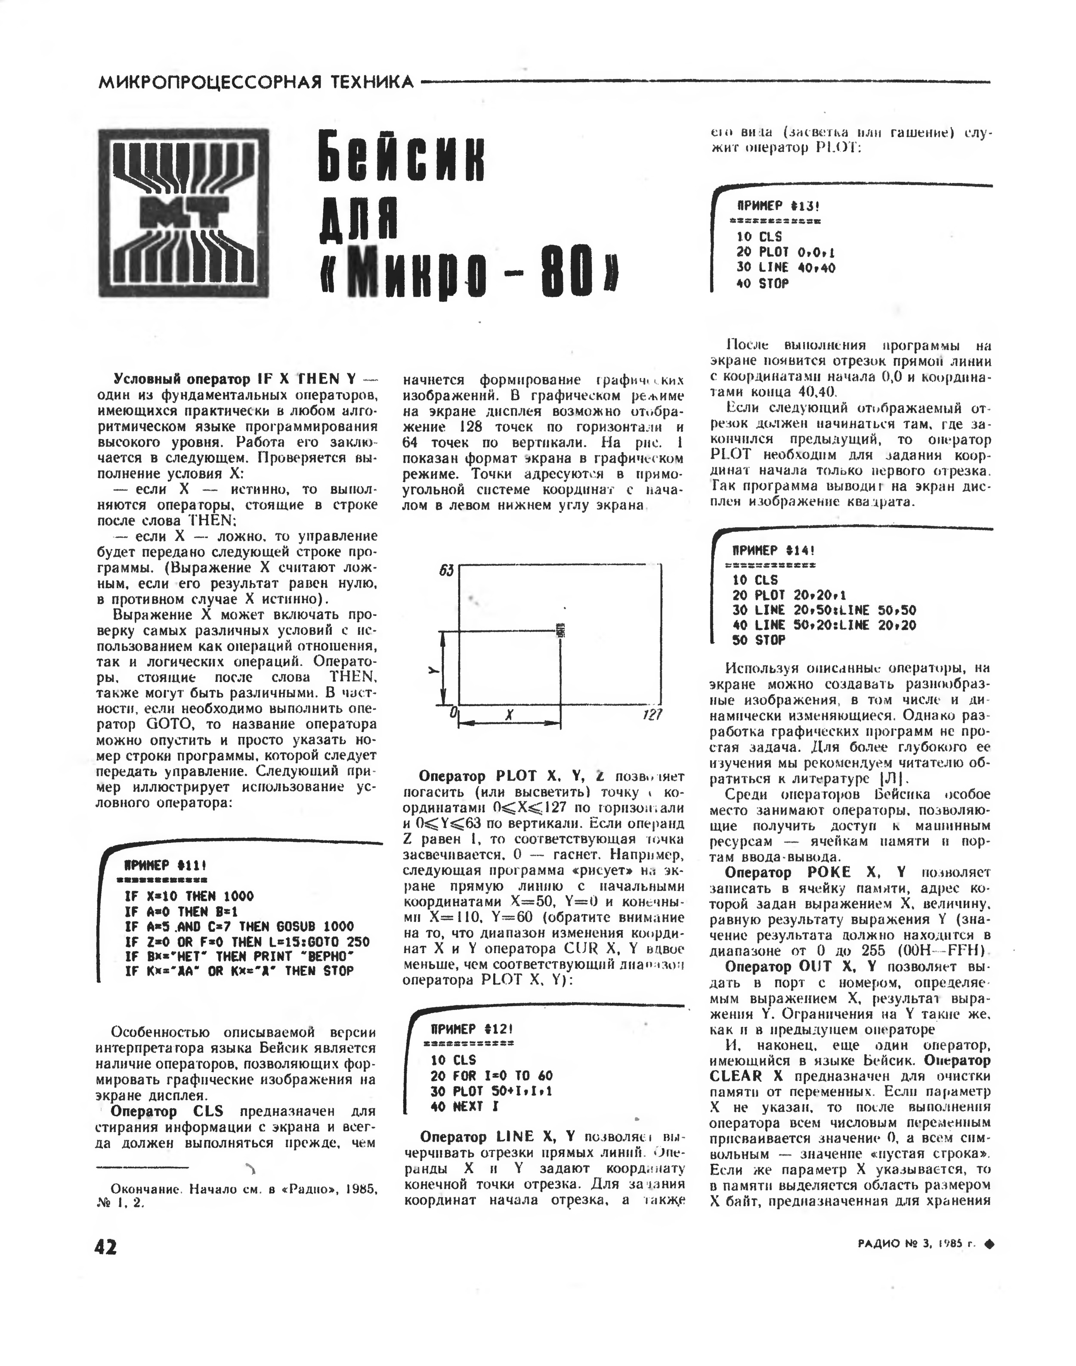
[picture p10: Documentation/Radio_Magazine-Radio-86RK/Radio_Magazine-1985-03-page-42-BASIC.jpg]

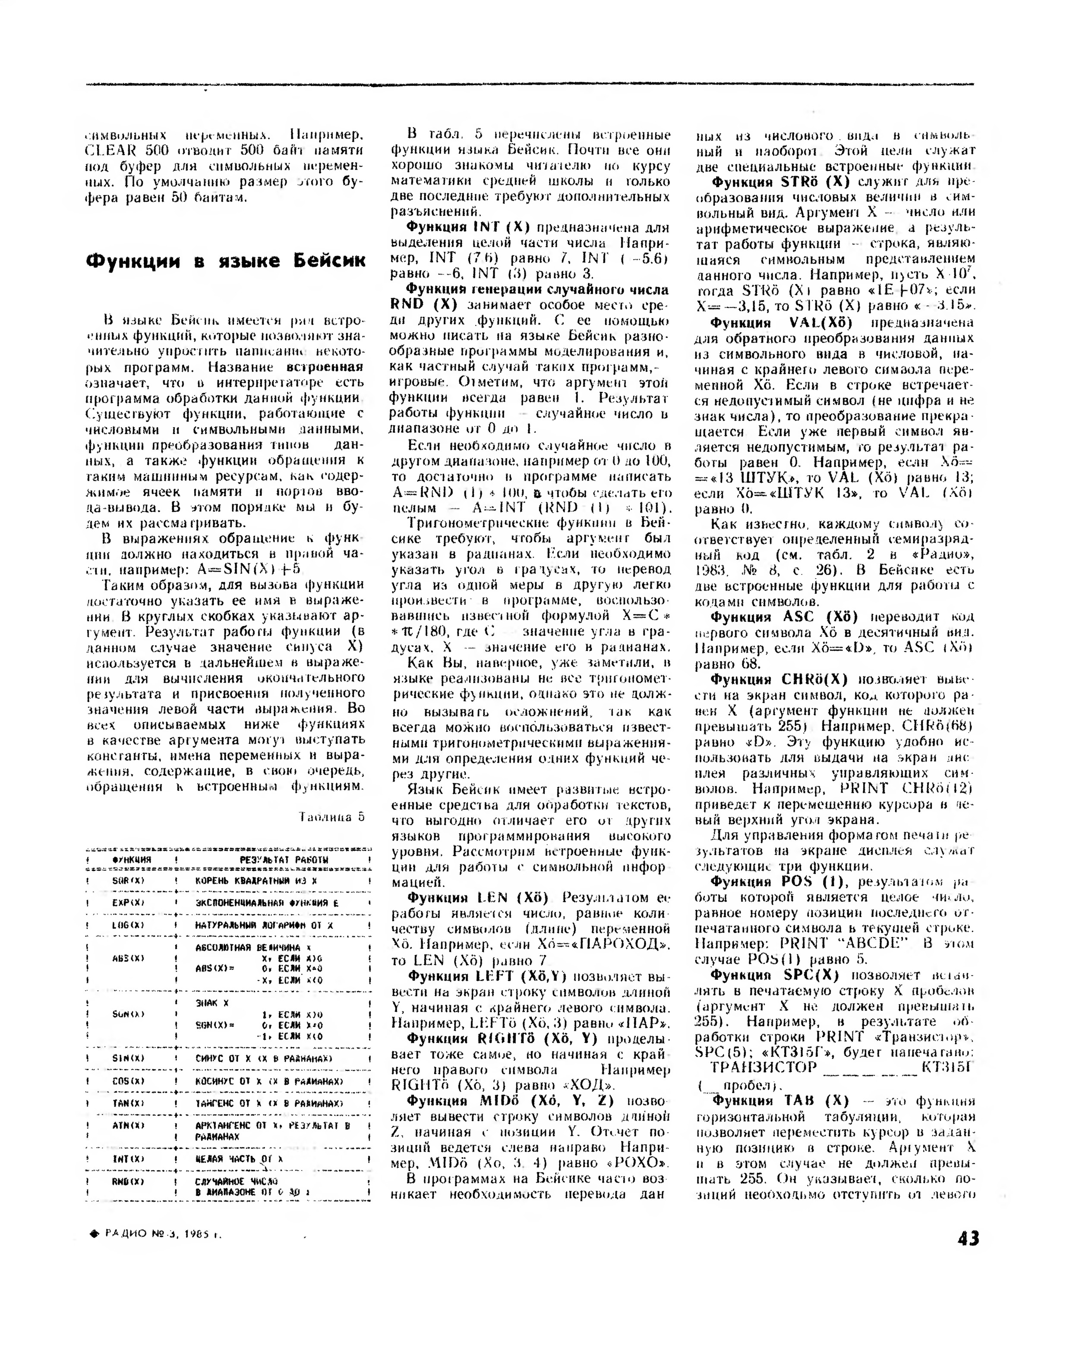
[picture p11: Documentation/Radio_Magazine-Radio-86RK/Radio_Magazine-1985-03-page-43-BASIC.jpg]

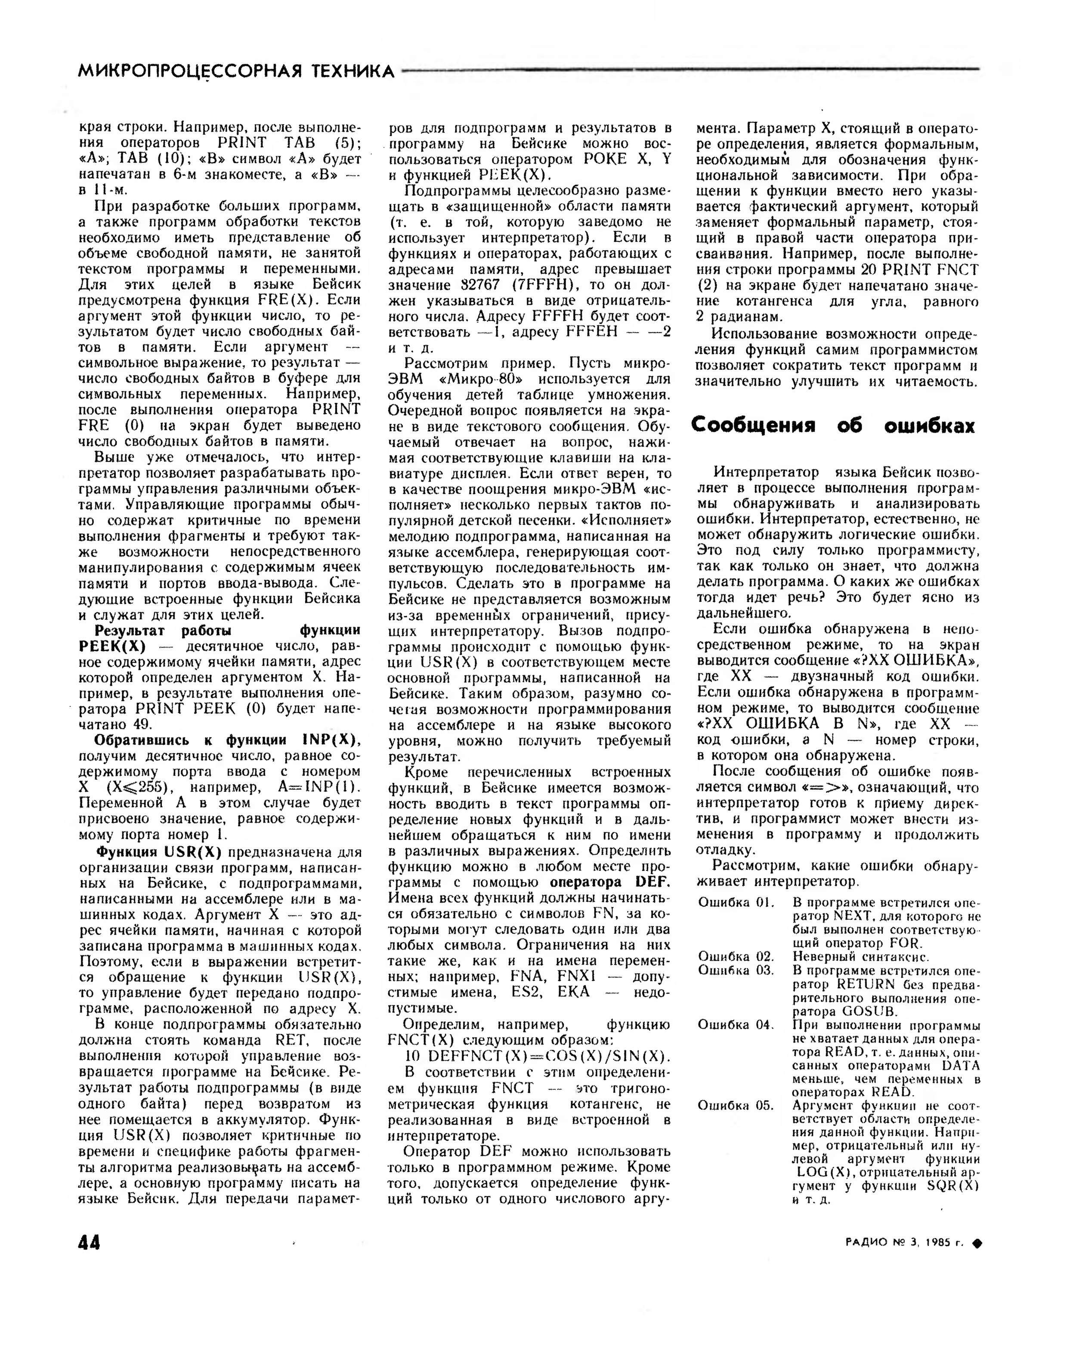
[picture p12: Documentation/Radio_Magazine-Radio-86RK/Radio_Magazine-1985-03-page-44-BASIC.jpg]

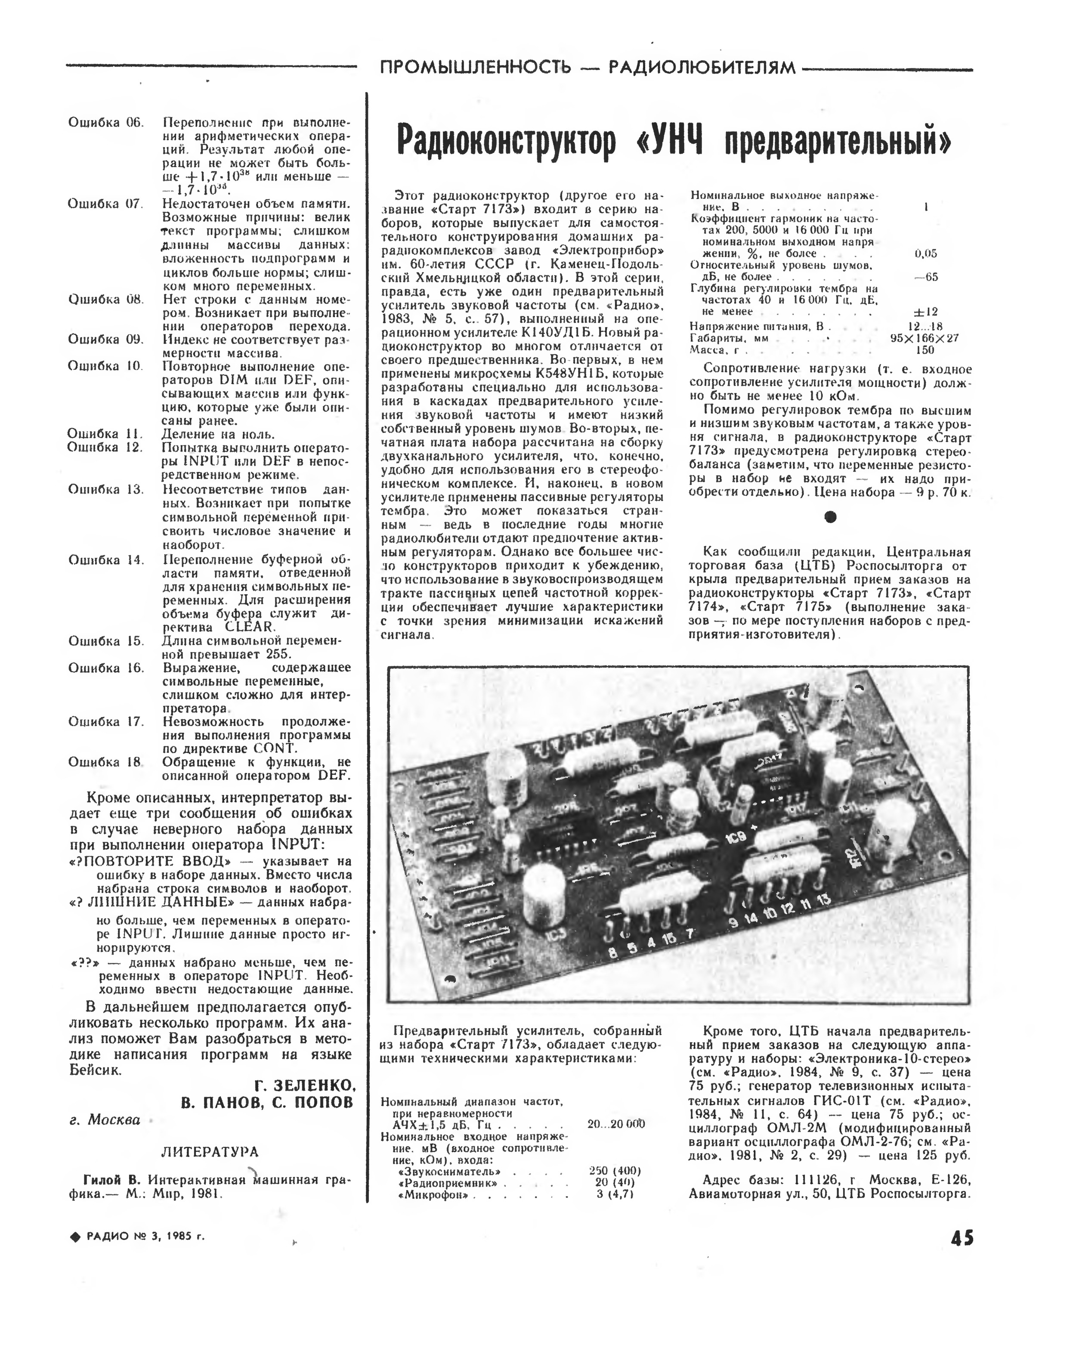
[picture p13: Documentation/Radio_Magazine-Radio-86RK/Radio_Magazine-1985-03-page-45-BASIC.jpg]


## Radio 1986, Issue 3

### BASIC Programming

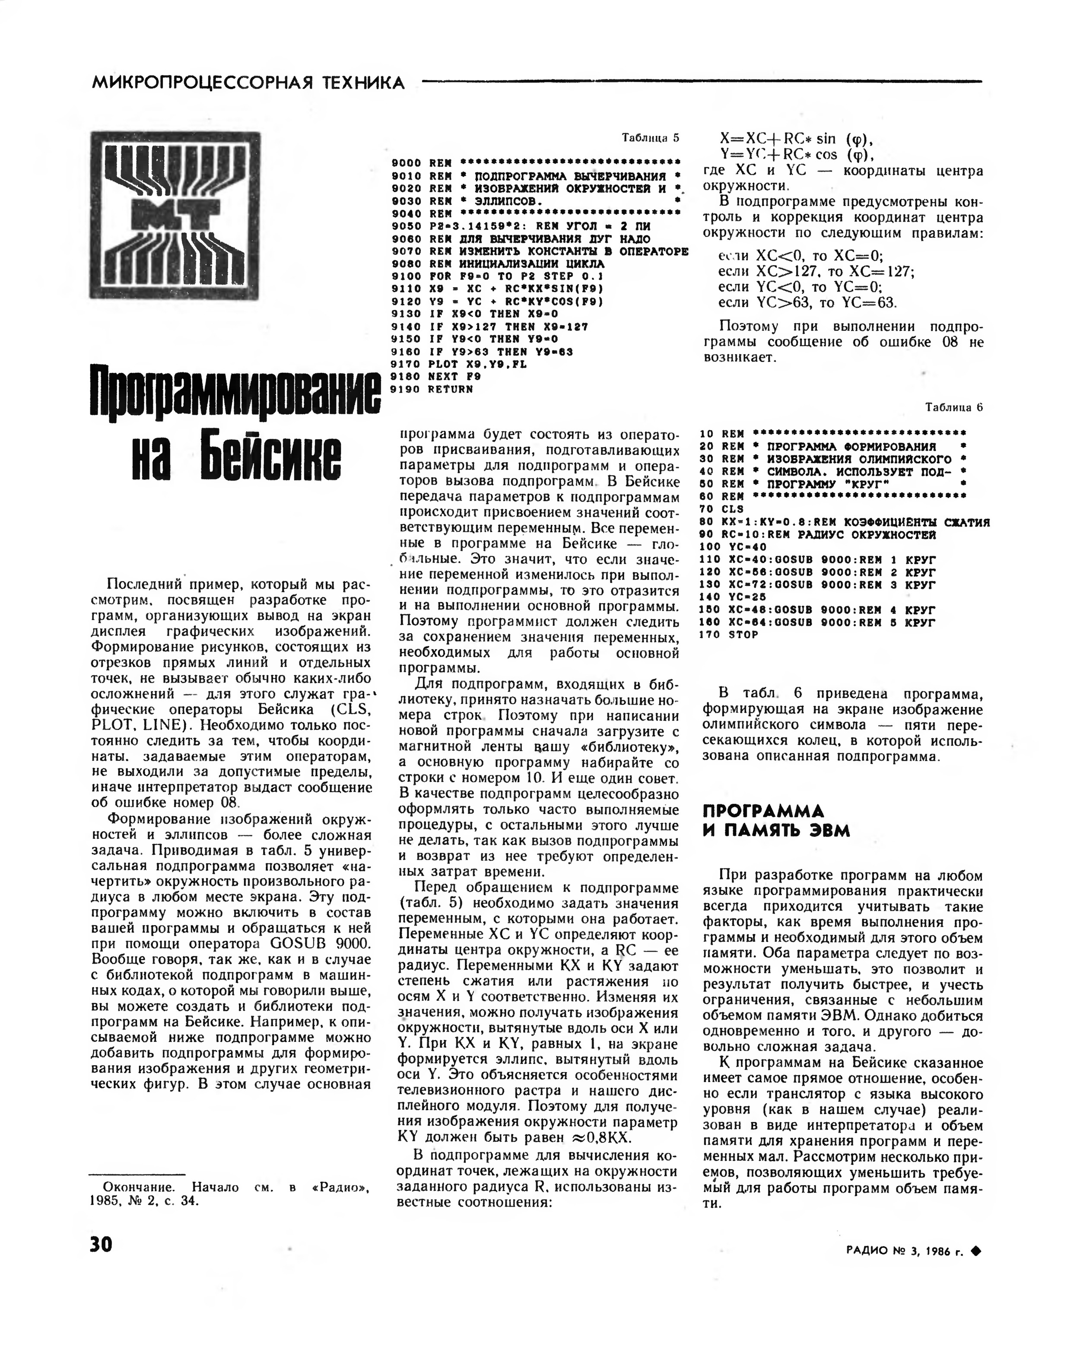
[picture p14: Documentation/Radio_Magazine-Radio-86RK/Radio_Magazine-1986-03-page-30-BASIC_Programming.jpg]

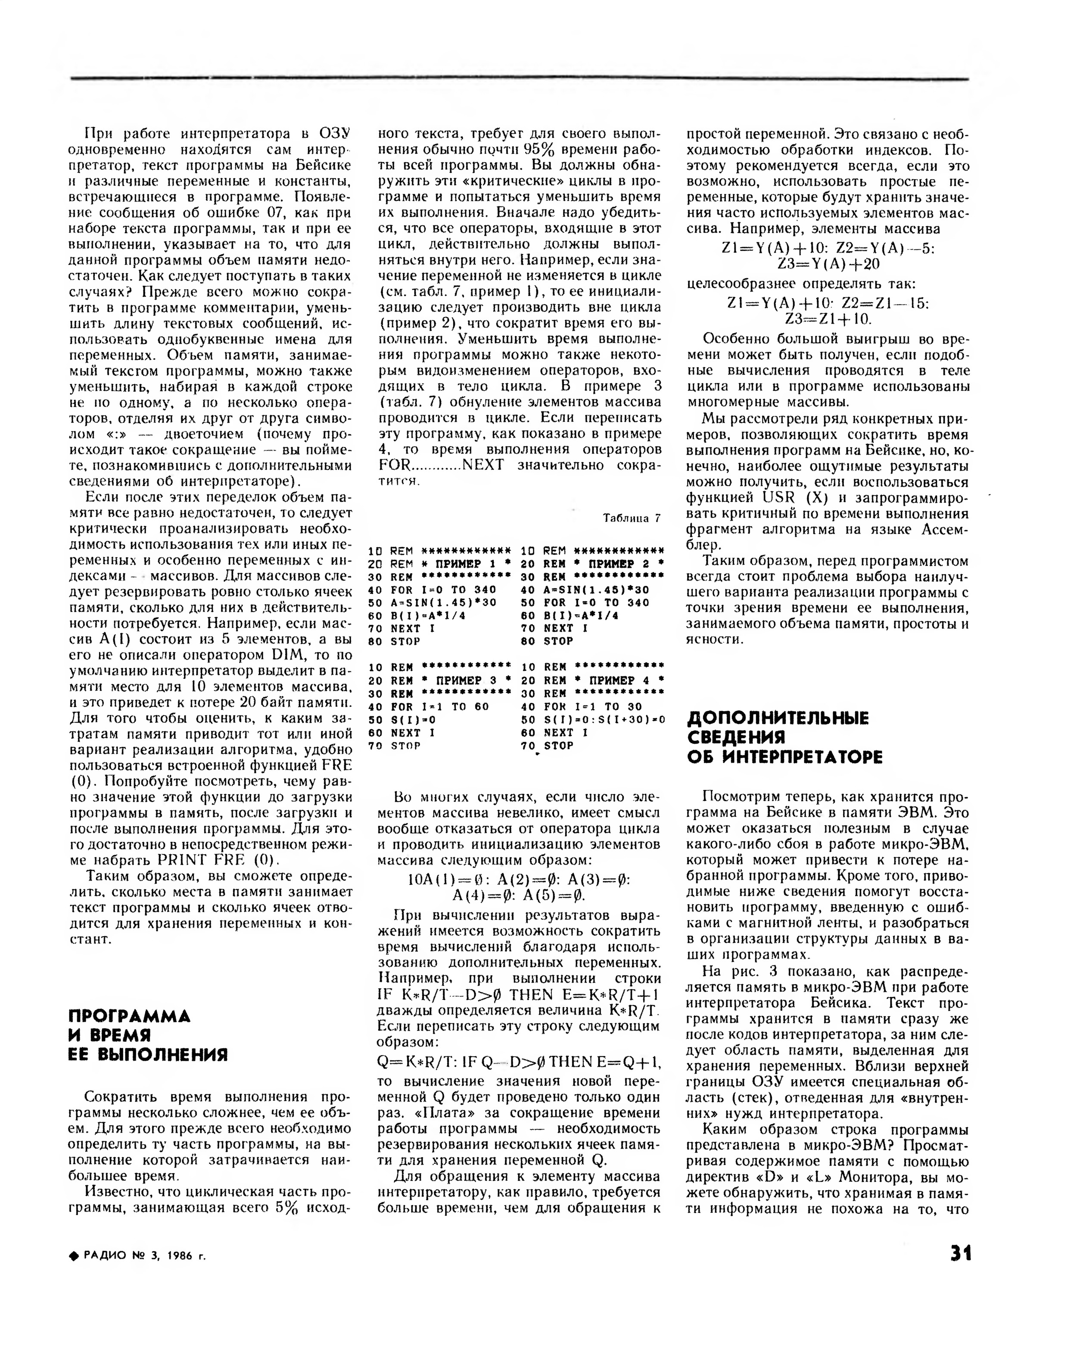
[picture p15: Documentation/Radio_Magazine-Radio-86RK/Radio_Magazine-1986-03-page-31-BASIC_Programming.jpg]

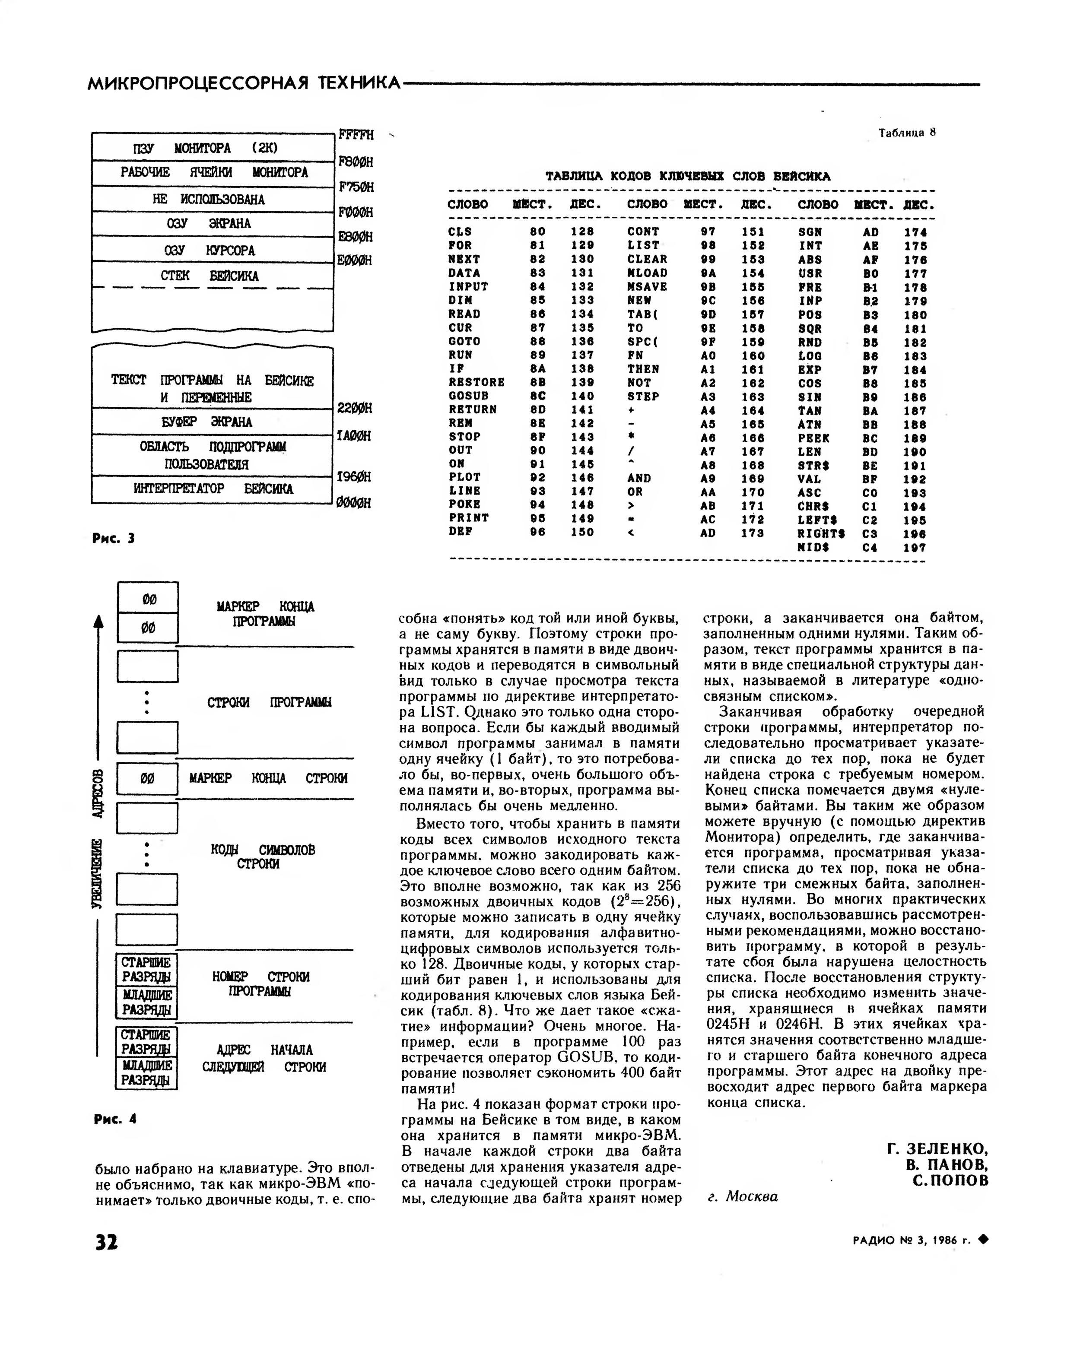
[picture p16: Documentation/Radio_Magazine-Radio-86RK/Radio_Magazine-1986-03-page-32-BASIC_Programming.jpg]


## Radio 1986, Issue 4

### Computer Architecture

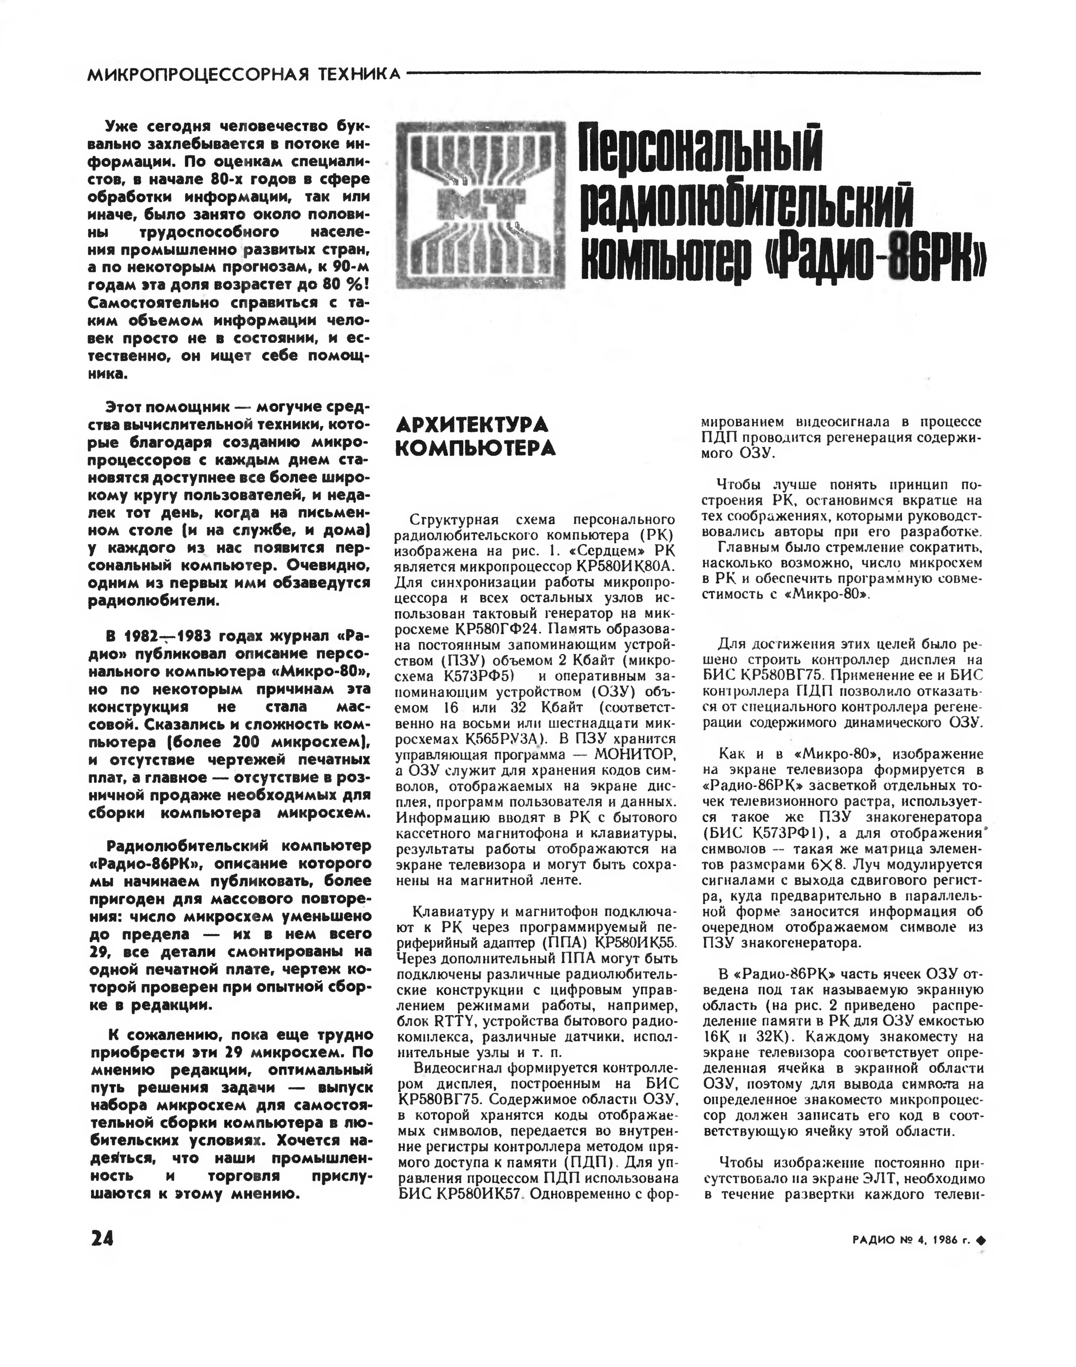
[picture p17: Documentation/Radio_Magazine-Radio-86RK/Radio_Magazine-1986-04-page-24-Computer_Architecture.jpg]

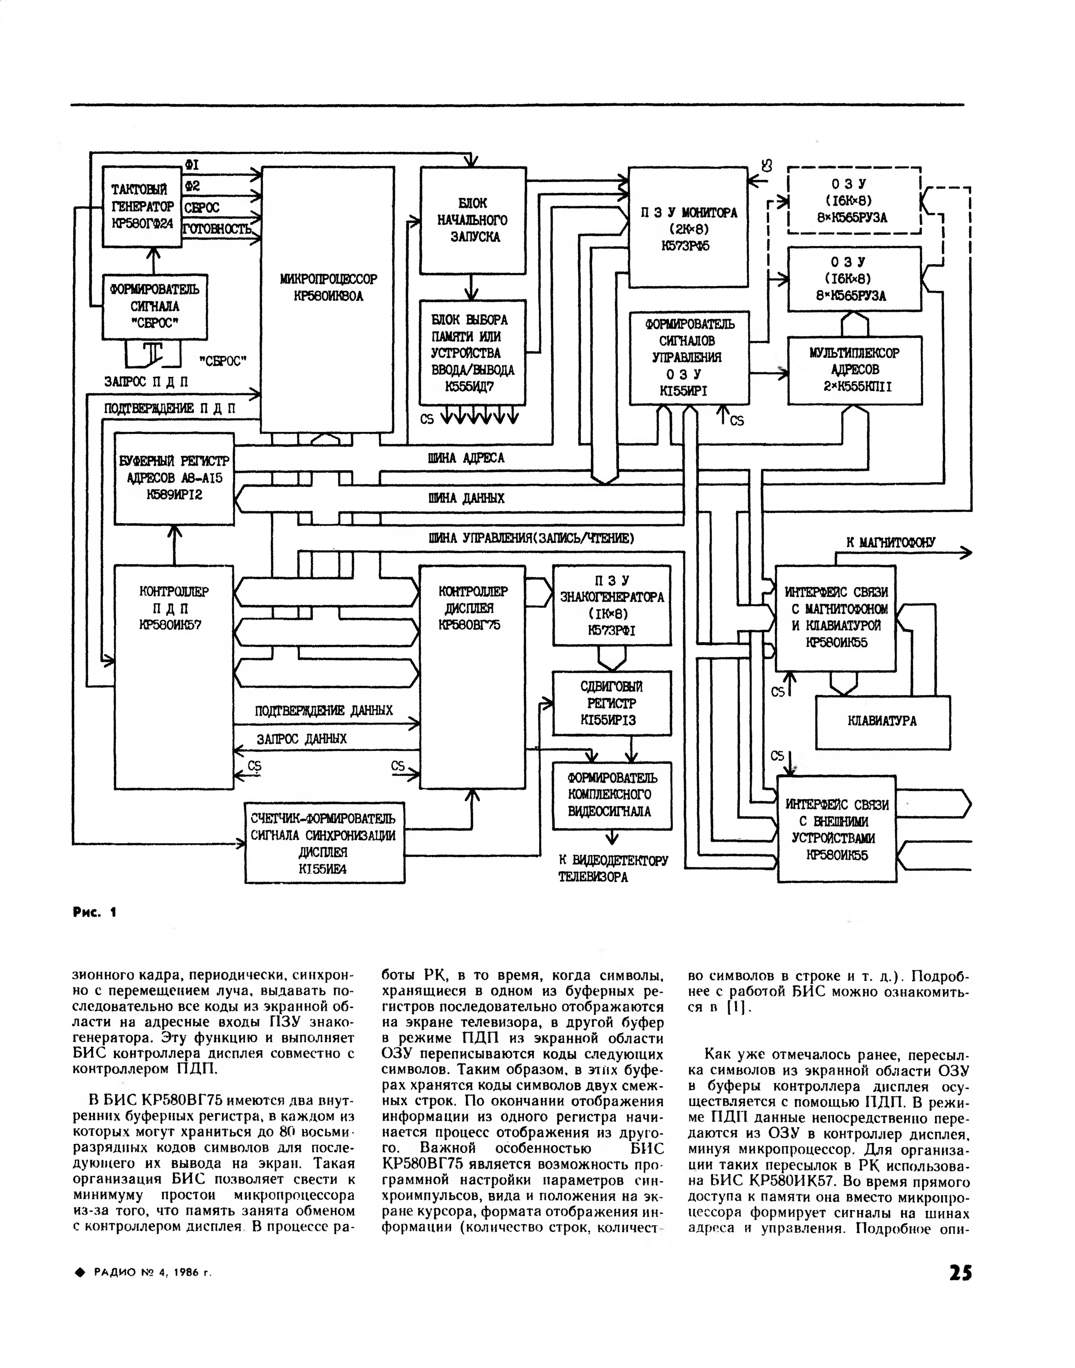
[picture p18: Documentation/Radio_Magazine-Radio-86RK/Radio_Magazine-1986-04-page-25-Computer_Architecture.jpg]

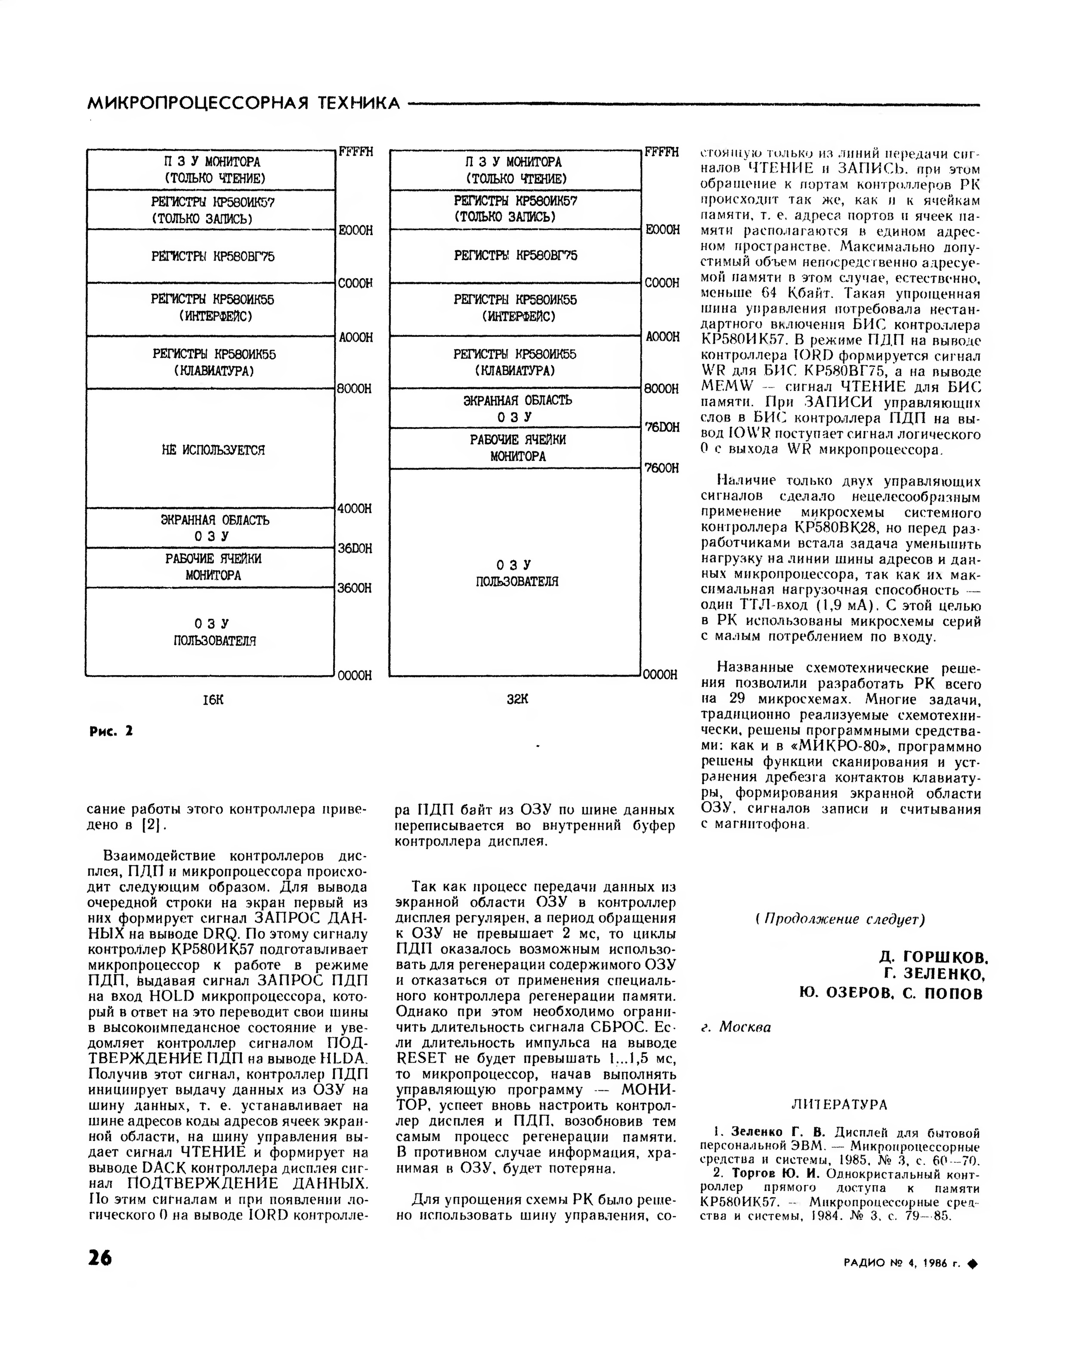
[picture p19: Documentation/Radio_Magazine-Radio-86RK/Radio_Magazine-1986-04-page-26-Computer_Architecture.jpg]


## Radio 1986, Issue 5

### CPU

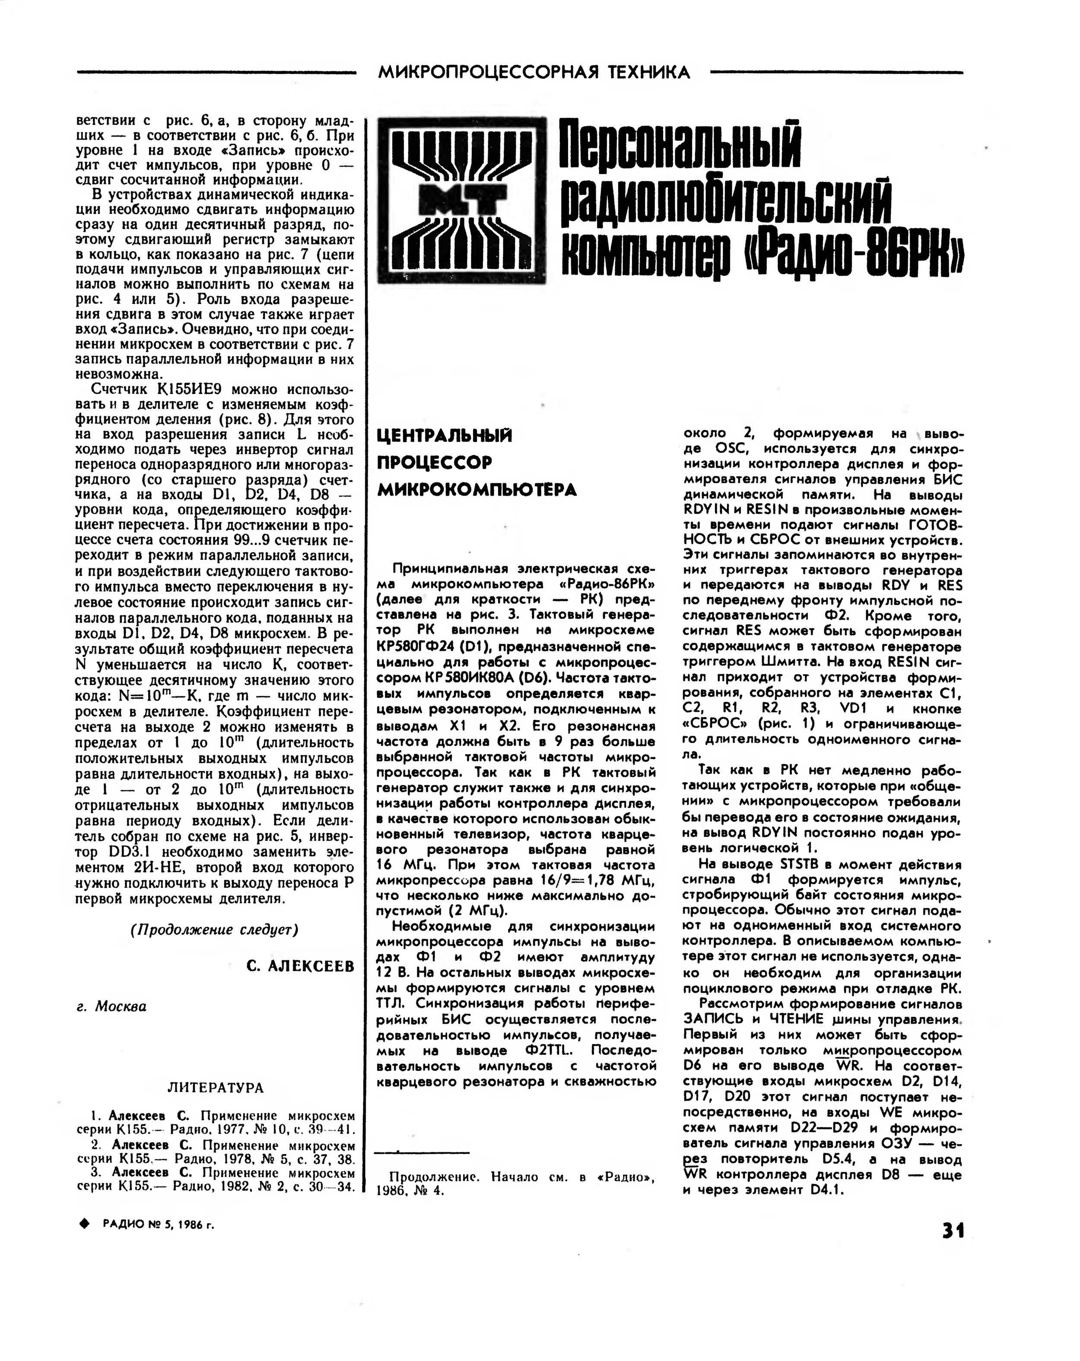
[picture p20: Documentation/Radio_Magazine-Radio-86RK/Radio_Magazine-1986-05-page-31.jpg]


### Memory and I/O Address Decode, RAM, Mainboard Schematic

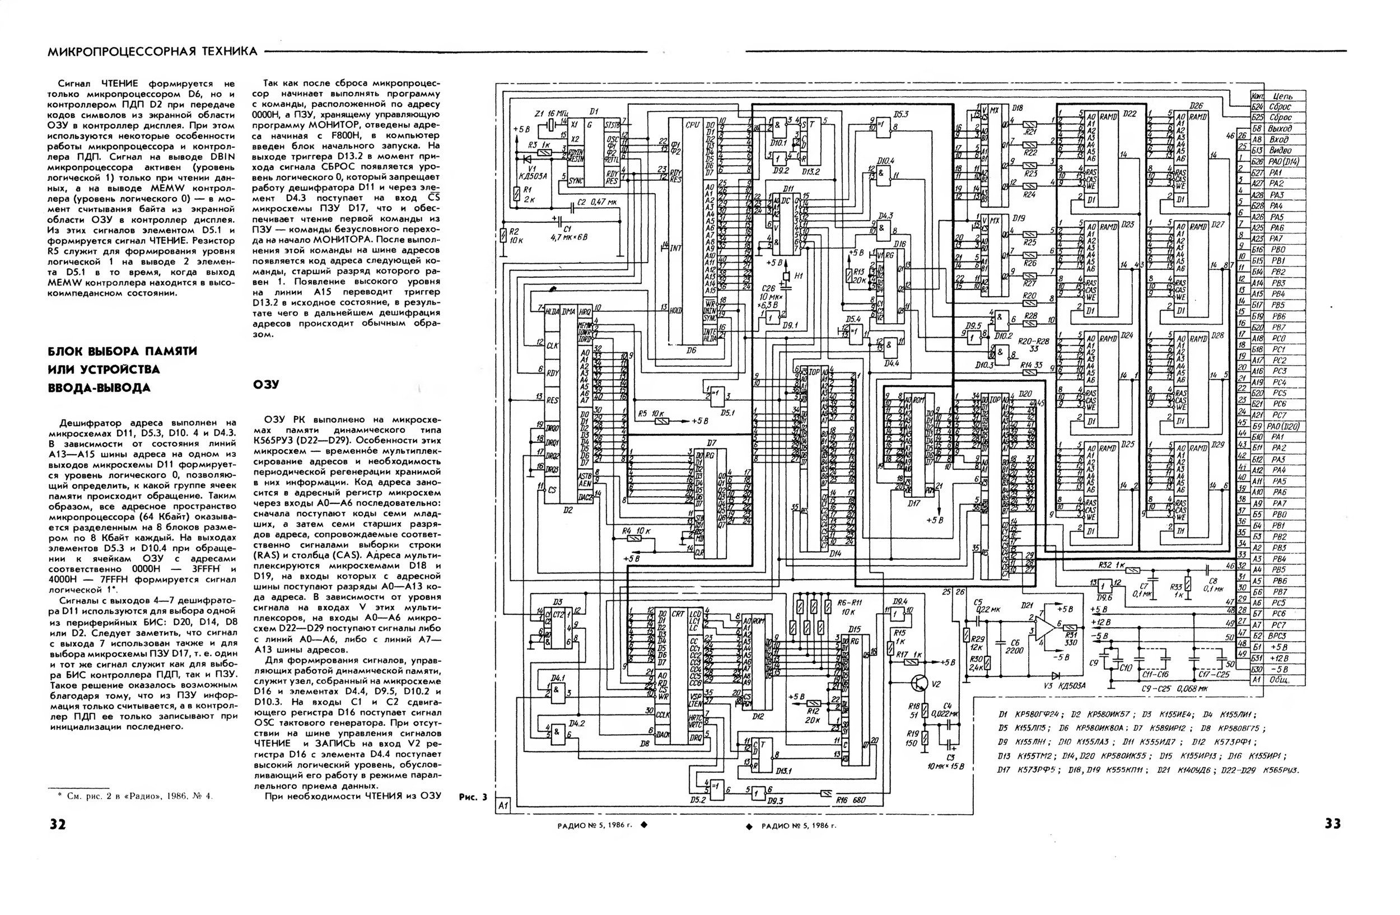
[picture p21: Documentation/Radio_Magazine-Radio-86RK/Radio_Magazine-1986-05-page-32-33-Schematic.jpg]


### DMA Controller, CRT Controller, Sound Generation

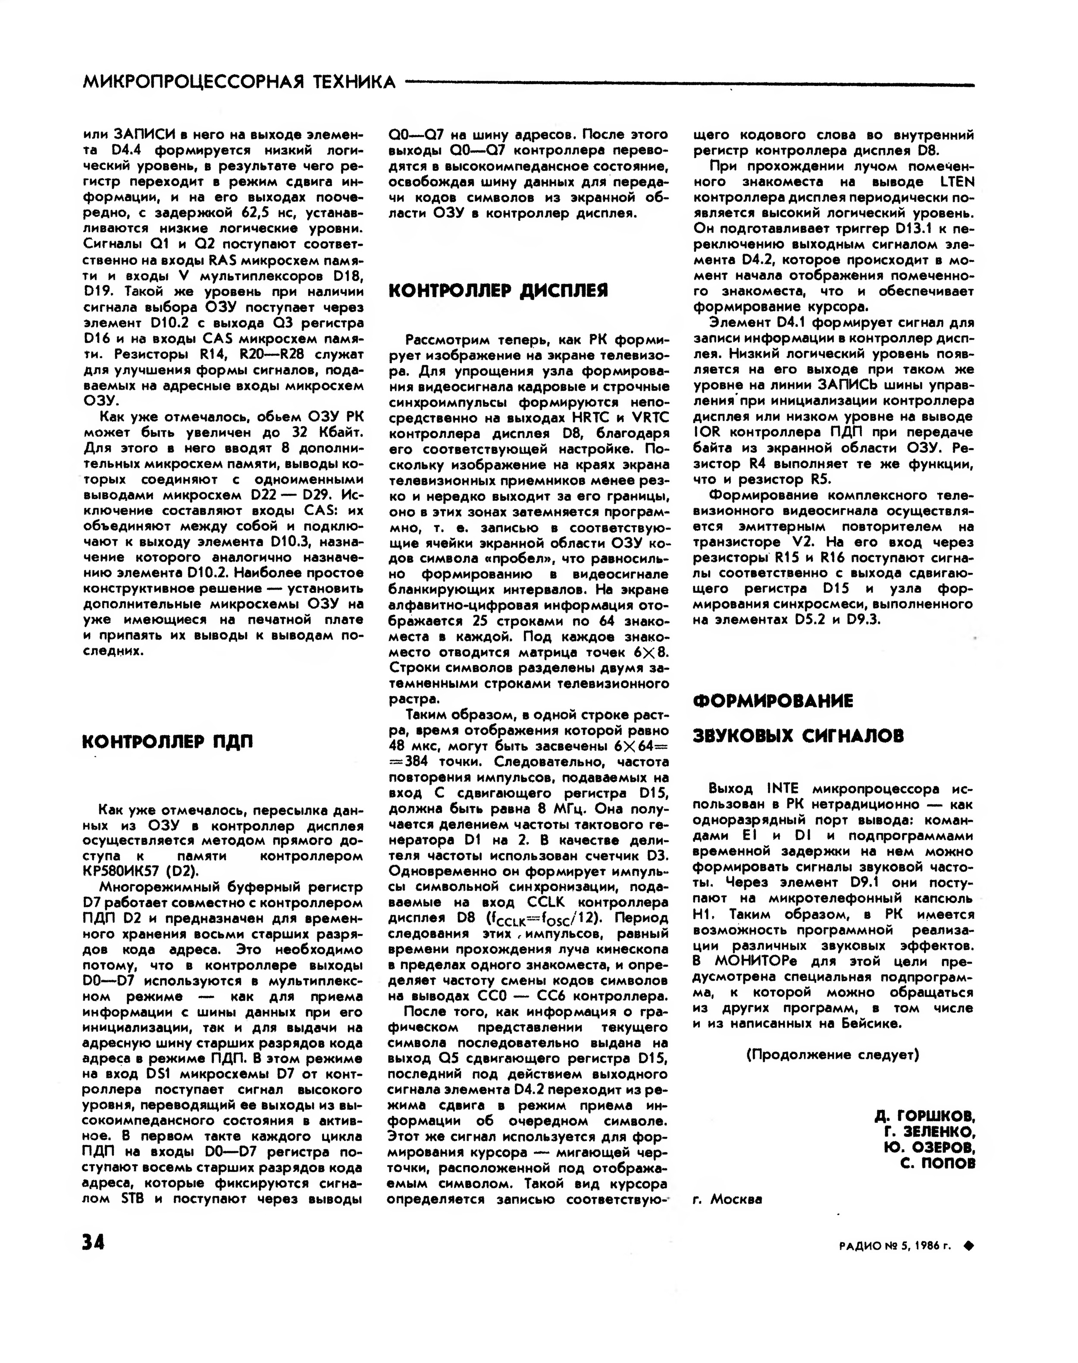
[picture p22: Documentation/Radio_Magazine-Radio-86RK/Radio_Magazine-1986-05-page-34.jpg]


## Radio 1986, Issue 6

### Keyboard PCB Layout

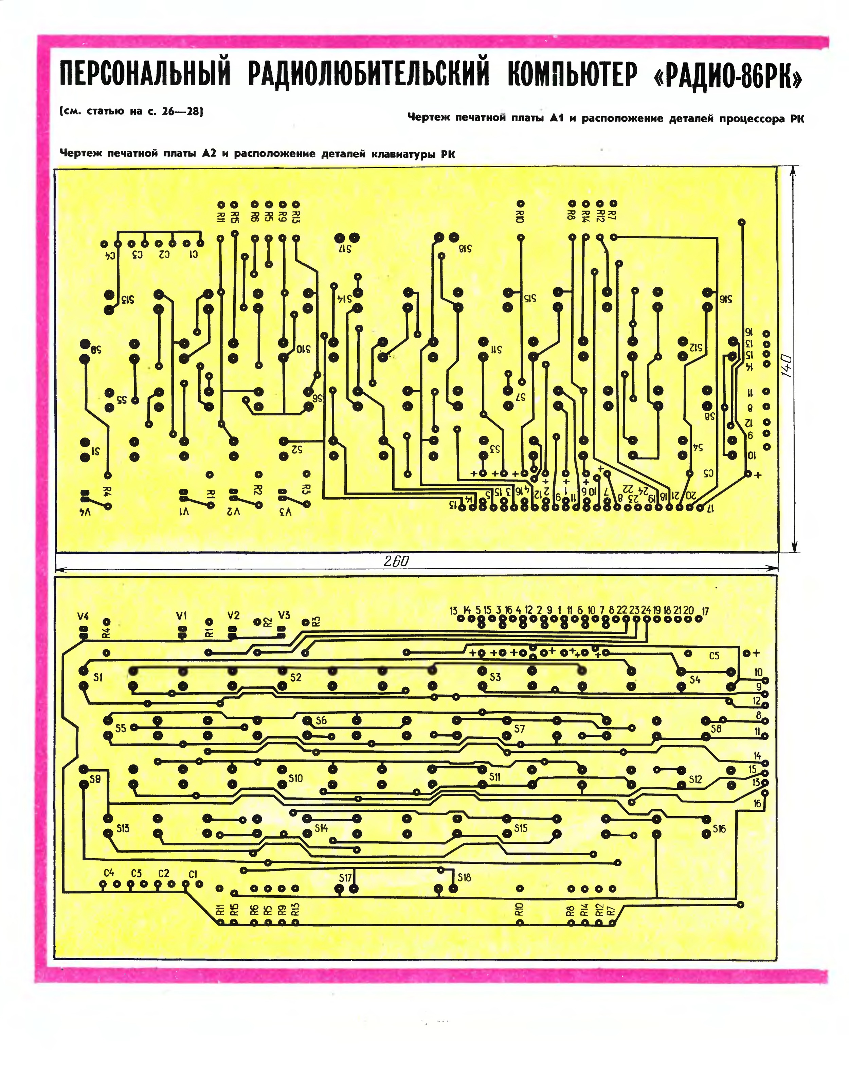
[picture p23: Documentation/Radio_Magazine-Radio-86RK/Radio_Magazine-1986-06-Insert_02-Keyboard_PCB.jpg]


### Mainboard PCB Layout

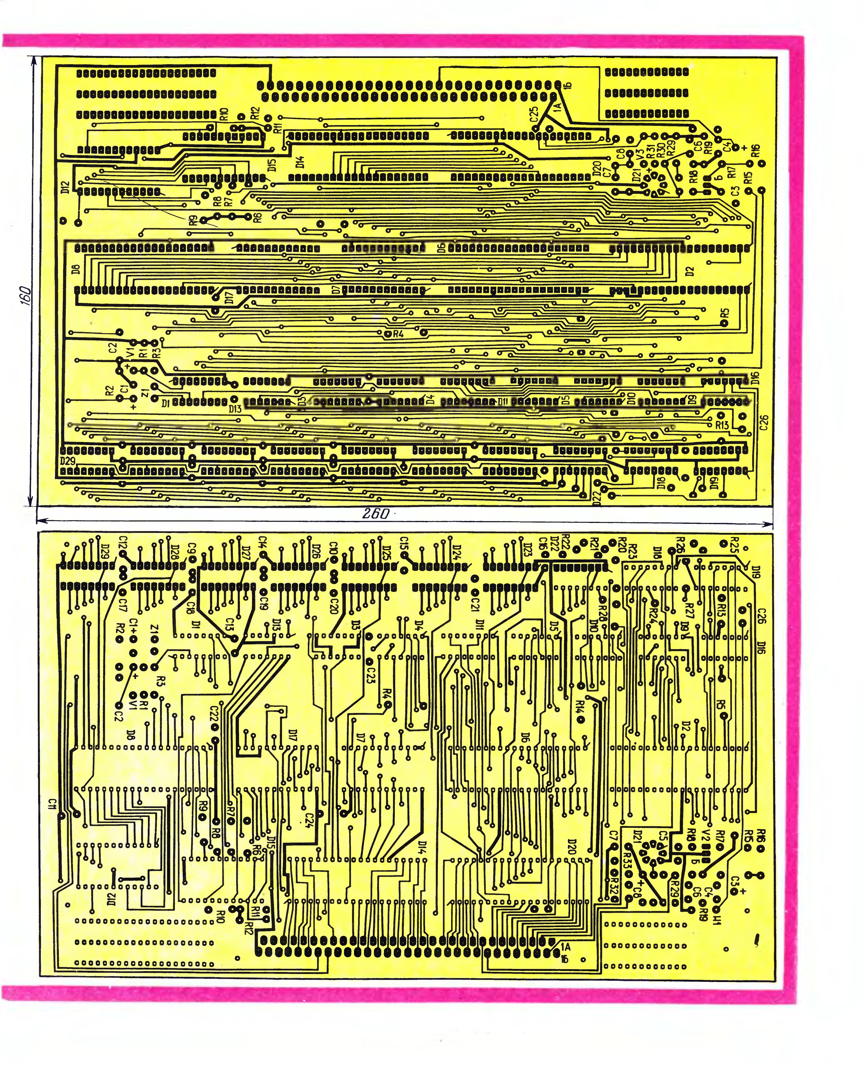
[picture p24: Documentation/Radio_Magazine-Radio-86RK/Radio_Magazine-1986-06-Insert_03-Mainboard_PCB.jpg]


### Keyboard

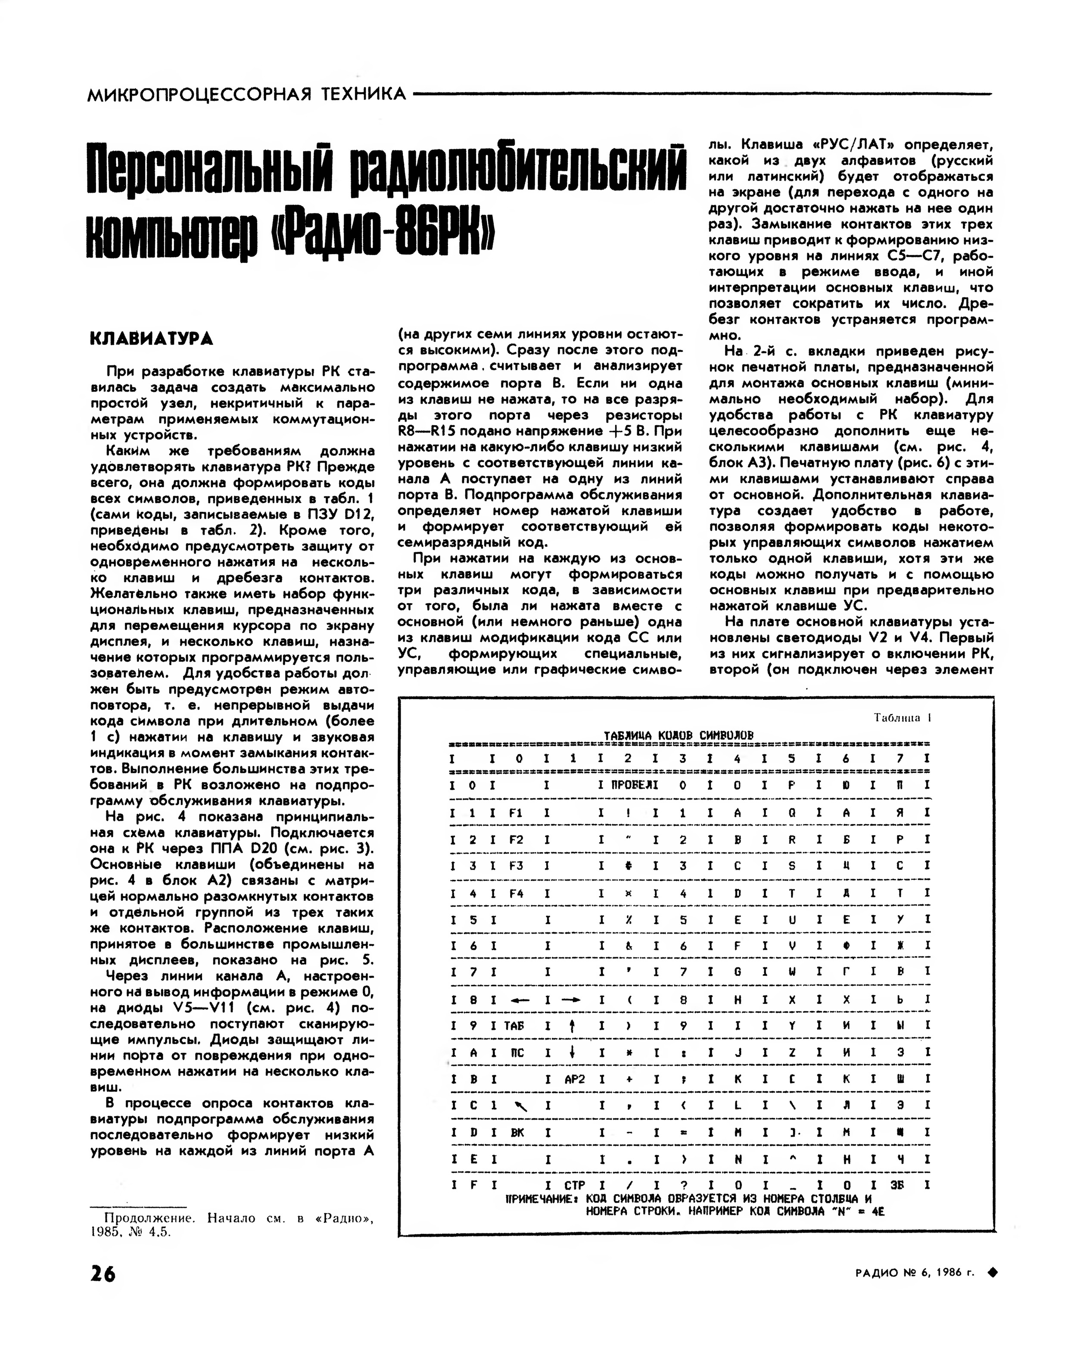
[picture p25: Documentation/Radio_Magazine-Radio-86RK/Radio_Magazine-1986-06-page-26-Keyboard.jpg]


### Font ROM Hex Dump, Keyboard Schematic



### Keyboard Layout, Cassette Tape Recorder Interface, Power Supply



## Radio 1986, Issue 8

### Software, ROM Monitor Boot, ROM Monitor CLI, ROM Monitor Memory Commands



### ROM Monitor Hex Dump 



### ROM Monitor Run and Debug Commands, ROM Monitor I/O Commands



### ROM Monitor Subroutines



## Radio 1986, Issue 9

### Software - ROM Monitor Changes for 32 KiB RAM, Keyboard Notes, Display Control Codes 




## Radio 1986, Issue 11

### Power Supply - Schematic and Design Description






## Radio 1986, Issue 12

### Power Supply - PCB and Assembly Instructions




### Assembly Notes and Errata



## Radio 1987, Issue 1

### BASIC Interpreter




## Radio 1987, Issue 2

### BASIC Games - Intersceptor, Joystick-like Control



### BASIC Games - Python/Snake






## Radio 1987, Issue 3

### BASIC Games - Fox Hunt




### ROM cartridge for BASIC Interpreter



## Radio 1987, Issue 4

### Programming Radio-86RK, Python/Snake Game







### Cassette Tape Recorder Input / Output





## Radio 1987, Issue 5

### Reference Tables - Intel 8080A (KR580VM80A) Instruction Set, Character Set




### Replacing Intel 8275 (KR580VG75) with Discrete Logic





## Radio 1987, Issue 11

### Using Intel 8253 (KR580VI53) as a Sound Generator







## Radio 1989, Issue 6

### Serial Interface Controller Based on Intel 8251A (KR580VV51A) - Design Description, Schematic and PCB Layout







## Radio 1989, Issue 7

### Serial Interface Controller Based on Intel 8251A (KR580VV51A) - Software Subroutines







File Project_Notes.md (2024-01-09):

# Radio-86RK Project Notes

## Radio Magazine Publications

The original design was published in Radio Magazine, an amateur radio and DIY electronics oriented publication, starting from [April 1986](http://archive.radio.ru/web/1986/04/027/).
Hence the "Radio" and "86" in the name ("RK" stands for ham radio computer).

Most (if not all) of the documentation is in Russian. Please submit a bug report if you'd like certain pieces to be translated or explained here.

_TODO: add links to or upload relevant parts of the original documentation_

## Radio-86RK Popularity

Being one of the first do-it-yourself computer designs published in Soviet Union, given its relatively simple construction and accessiblity of parts, Radio-86RK was quite popular.
Many amateurs build the system. In addition, the industry offered kits and also produced several Radio-86RK based computers.
Some of these are listed in the Wikipedia [Radio-86RK](https://en.wikipedia.org/wiki/Radio-86RK) article

Even until recently, Radio-86RK remained quite popular with the folks from former Soviet Union, likely for nostalgic reasons.
Several new implementations were designed, including [Radio-86RК-SRAM](http://radio86rk.pbworks.com/w/page/58467718/Radio-86R%D0%9A-SRAM) project created by Alexey Khudyakov (alexcp), and this design

## Components Substitution

* Most Intel 8000-series parts are no longer available from Mouser/Digi-Key/Jameco, and apparently even good old 74LS are being impacted by the components' shortage.
[Unicorn Electronics](https://www.unicornelectronics.com/prod.htm) seem to have most of the TTL and 8000-series parts required for the project. Otherwise parts can be bought on eBay.
* It should be possible to substitute 74LS-series logic ICs with 74ALS/74F/74HCT/74AHCT series
* Intel 8000-series can be substituted by CMOS 8xCxx ICs, where available, for example 82C51A instead of 8251A, 82C54 instead of 8253, 82C55A instead of 8255A...
* I haven't tried using 82C37 instead of 8257... it might or might not work... The pinout seems to be similar enough.

## Keyboard Layout and Construction

* The keyboard uses Cherry MX keys. Some people that have built my [Omega Home Computer](https://github.com/skiselev/omega) project had success replacing them with Chinese clones (Kailh brand?!)
* Keyboard Layout - Version 1.4
  * Version 1.4 uses QWERTY layout. Note that location of math, punctuation and other special symbols is a bit different from typical modern QWERTY keyboard
  * Common Cherry MX compatible keycaps can be used. XDA or DSA keycaps are recommended, as they have uniform shape regardless of the row. XDA have a bit more vintage, rounded feel to them too
* Keyboard Layout - Versions 1.0 - 1.3
  * The keyboard layout is [JCUKEN](https://en.wikipedia.org/wiki/JCUKEN). The keys are labeled on the PCB's silkscreen for your convenience. The JCUKEN layout is a standard Cyrillic/Russian keyboard layout with Latin letters placed with similar Cyrillic letters. It might be a bit of pain to get used to :smile:
  * Since JCUKEN keycaps are not readily available, in my build I've used blank [Cherry MX compatible keycaps](https://www.amazon.com/dp/B07GP29DQF/), and printed the letters on transparent labels using a label printer

## Video Output

The video output is monochrome composite video with 50 Hz (PAL/SECAM compatible) refresh rate.
Most NTSC TVs will work with that just fine, although the picture size might be incorrect or the picture might be shifted.
It is also possible to use a composite to HDMI adapter, such as [this one](https://www.amazon.com/gp/product/B01L8GG6PW/), and connect the output to a computer monitor or a modern LCD TV.

## Monitor and Font ROMs

The [Monitor ROM](https://github.com/skiselev/radio-86rk/blob/master/Software/radio-86rk-monitor-video-attr.bin) and the [Font ROM](https://github.com/skiselev/radio-86rk/blob/master/Software/radio-86rk-font.bin) are provided in this repository

Version 1.4 add support to 2732, 2764 and 27C64 EPROMs, and 28C64 EEPROM:
* Please set the JP1 and JP2 jumpers according to the EPROM/EEPROM type used
* For the monitor ROM, if using a 4 KiB or an 8 KiB ROM, program the ROM image to the top of the address space (top 2 KiB)
* For the font ROM, if using a 4 KiB or an 8 KiB ROM, program the ROM image to the bottom of the address space (bottom 2 KiB)

## ROM Cartridges

Radio-86RK's monitor supports ROM cartridges, that are connected to the 8255 PPI based parallel interface.
I've designed a PCB for [ROM cartridges](https://github.com/skiselev/radio-86rk-rom) that supports 27C128 and 27C256 EPROMs, 28C256 EEPROMs, and 29C256/29F256 Flash ROMs.
Use [**R** monitor command](https://github.com/skiselev/radio-86rk#monitor) to copy the content of the ROM cartridge to computer's RAM.

A [ROM cartridge image](https://github.com/skiselev/radio-86rk/blob/master/Software/rom_disk.bin) including BASIC interpreter, EDITOR/ASSEMBLER, EDITOR/DISASSEMBLER, DP/DDT debugger, XONIX, OTHELLO, and TETRIS games is provided in this repository.

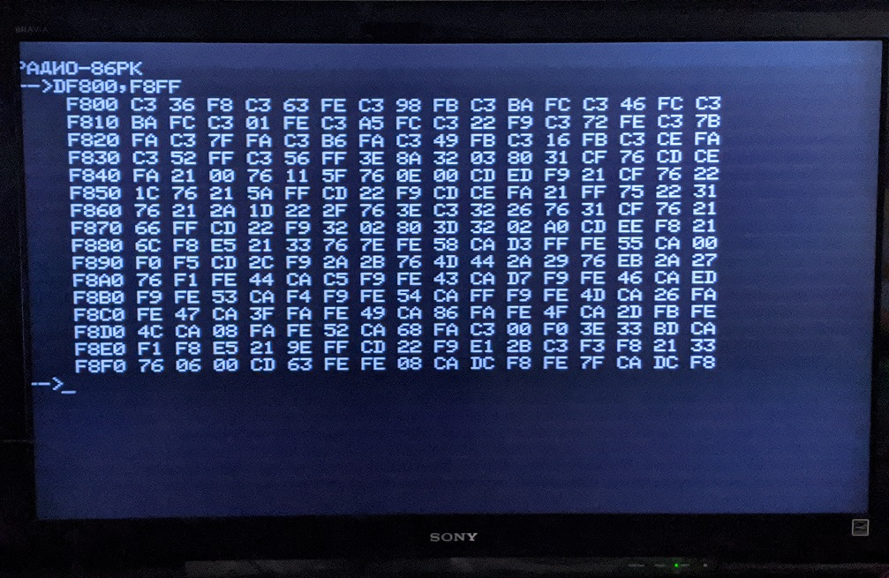
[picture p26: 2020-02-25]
images/Radio-86RK-TV_Output.jpg

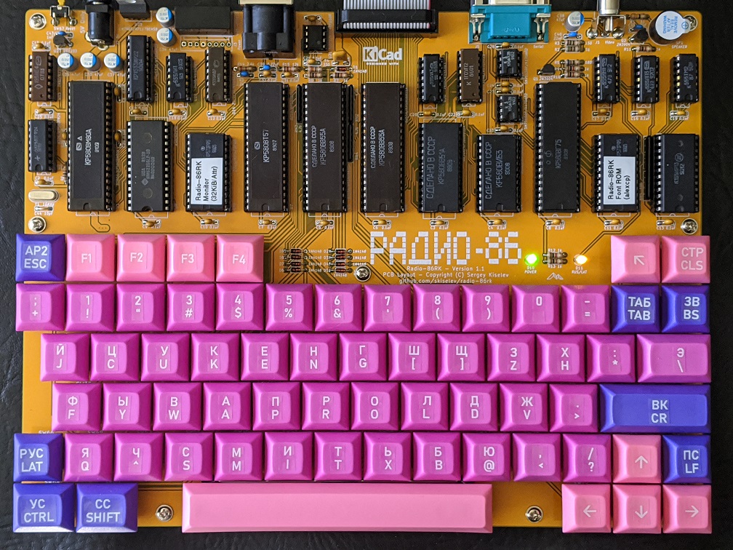
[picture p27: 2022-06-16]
images/Radio-86PK-1.1-With_Keyboard.jpg

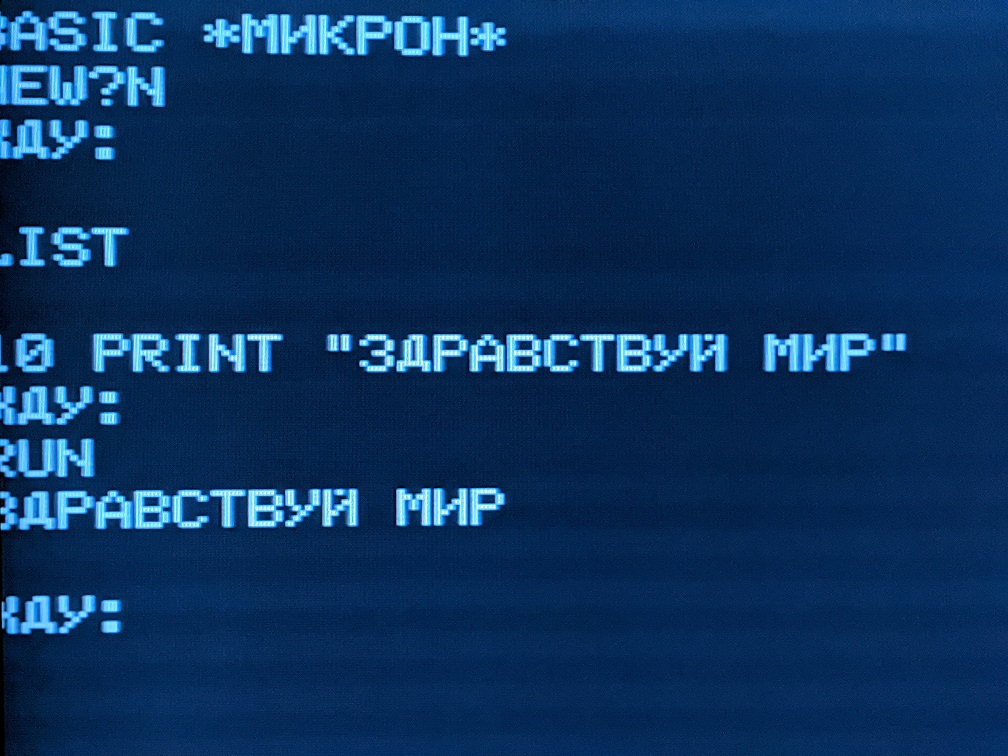
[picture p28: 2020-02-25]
images/Radio-86RK-Hello_world.jpg

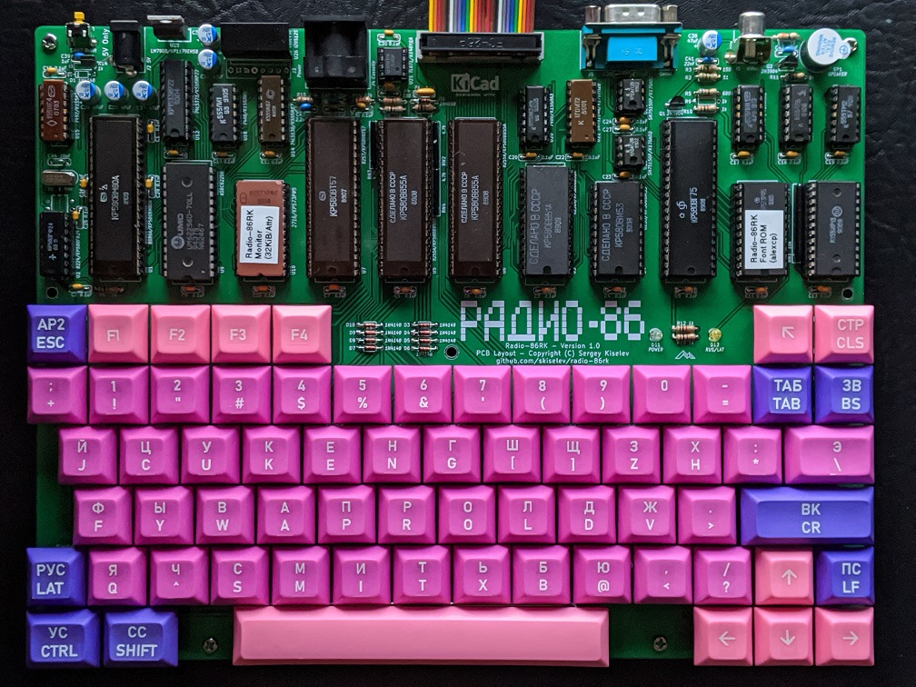
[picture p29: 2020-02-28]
images/Radio-86PK-1.0-With_Keyboard.jpg

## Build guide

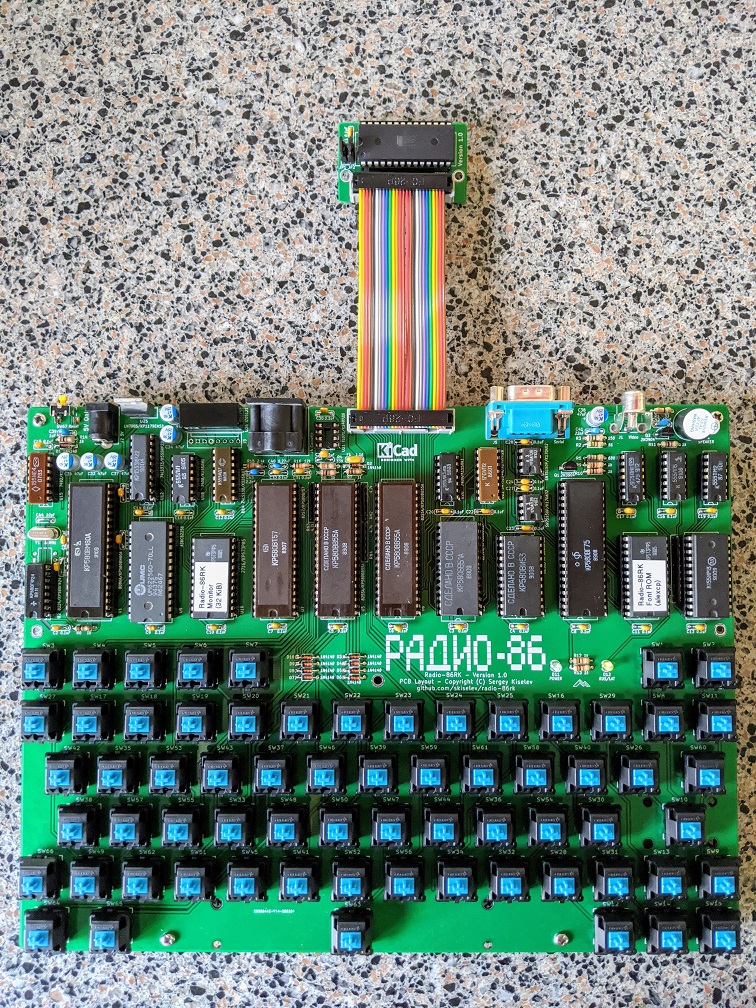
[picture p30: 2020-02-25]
images/Radio-86RK-Assembled.jpg

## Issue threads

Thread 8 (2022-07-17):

Mouser project BOM tweaks

wrljet, 2022-07-17:
The Mouser project BOM for the version 1.3 PCB:

- lists a 1uF capacitor, that I can't find on the schematic

- lists 66 Cherry key switches, while the project requires 67

Bill

skiselev, 2022-07-26:
Thanks for your report! I've fixed the Mouser's BOM for this project

Closed 2022-07-26.

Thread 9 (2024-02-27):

Add support for the "highlight" attribute

skiselev, 2024-02-27:
An enhancement suggested by Дмитрий Иванов:

[Апогей БК-01](https://ru.wikipedia.org/wiki/%D0%90%D0%BF%D0%BE%D0%B3%D0%B5%D0%B9_%D0%91%D0%9A-01) computer (an industrially manufactured Radio 86RK derivative) supported in highlight attribute.
It is a fairly easy modification: A 3 kohm resistor should be added between the HLGT signal of U8 К580ВГ75/8275 CRTC pin 32 and the base of Q1 transistor - pin 2.
The attribute can be activated by writing 0x81 or similar field attribute codes to the video memory.

Field attribute format:
Bit 7 | Bit 6 | Bit 5 | Bit 4 | Bit 3 | Bit 2 | Bit 1 | Bit 0
----- | ----- | ----- | ----- | ----- | ----- | ----- | -----
1 | 0 | Underline | Reverse video | GPA1 | GPA0 | Blink | Highlight

It is fairly easy to add support for highlight attribute in the existing versions of this project by soldering the abovementioned resistor on the bottom side of the PCB as shown:
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

Demo of using field attributes:
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

explit7, 2024-12-05:
Hi @skiselev I have a question. 3Kohm Resistor are hard to get here, can 3K3 Resistor be used instead, or is it critical?

Thanks

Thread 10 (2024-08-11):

Lode Runner: unstable video output

0ddjob, 2024-08-11:
I'm quite enjoying using this machine - thanks.

I currently have the v1.3 PCB and have all Western parts apart from CPU and character ROM (both Soviet).

I've found excellent compatibility so far except for "Lode Runner".  It won't run properly - the video output is not stable.

For video output I have connected the RK to a Sony DVD recorder.  This is usually fine but Lode Runner isn't happy.

Is there any troubleshooting I can do to determine where the issue might be?  I sourced the file from [here](https://github.com/alemorf/retro_computers/tree/master/Radio-86RK/software) and used MAME castool to convert from RKR to WAV file, then loaded with [I] command.

Thanks.

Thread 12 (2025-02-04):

580BM80 instead KP580BM80A ?

explit7, 2025-02-04:
Hello @skiselev
I build the radio-86rk and installed the military version of the KP580BM80A - 580BM80.
While it generally works, i see that the civil version KP580BM80A works a little bit more stable.
According to https://ru.wikipedia.org/wiki/%D0%9A%D0%A0580%D0%92%D0%9C80%D0%90 there are some differences between the both CPUs. Do you have some Information according to that, or should it play no role if its 8080 or 8080A?

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

https://forum.classic-computing.de/gallery/index.php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

skiselev, 2025-02-04:
I don't have any experience using the 580BM80, but here is my opinion:

- The 580BM80 that you have is likely to be the same as consumer/commercial grade КР580ВМ80А or КР580ИК80А - its earlier designation. It is likely that the manufacturer did more thorough burn-in testing for the military grade components. And it is possible that it will be higher quality and more stable because of this additional testing. By the way, my Radio-86RK runs nicely with a consumer grade КР580ВМ80А. I didn't notice any instability or other issues.
- Intel 8080 was produced for a very short period of time. It had very limited fan-out, and therefore Intel recommended using it with TTL-LS loads only. The issue was fixed in Intel 8080A a few months after 8080 came out. I don't think the 'А' suffix in Soviet made 8080 clones have anything to do with this fix. It was cloned later, and there is no good reason to clone an inferior part...

explit7, 2025-02-05:
Thanks for the clarification, @skiselev!

Closed 2025-03-01.

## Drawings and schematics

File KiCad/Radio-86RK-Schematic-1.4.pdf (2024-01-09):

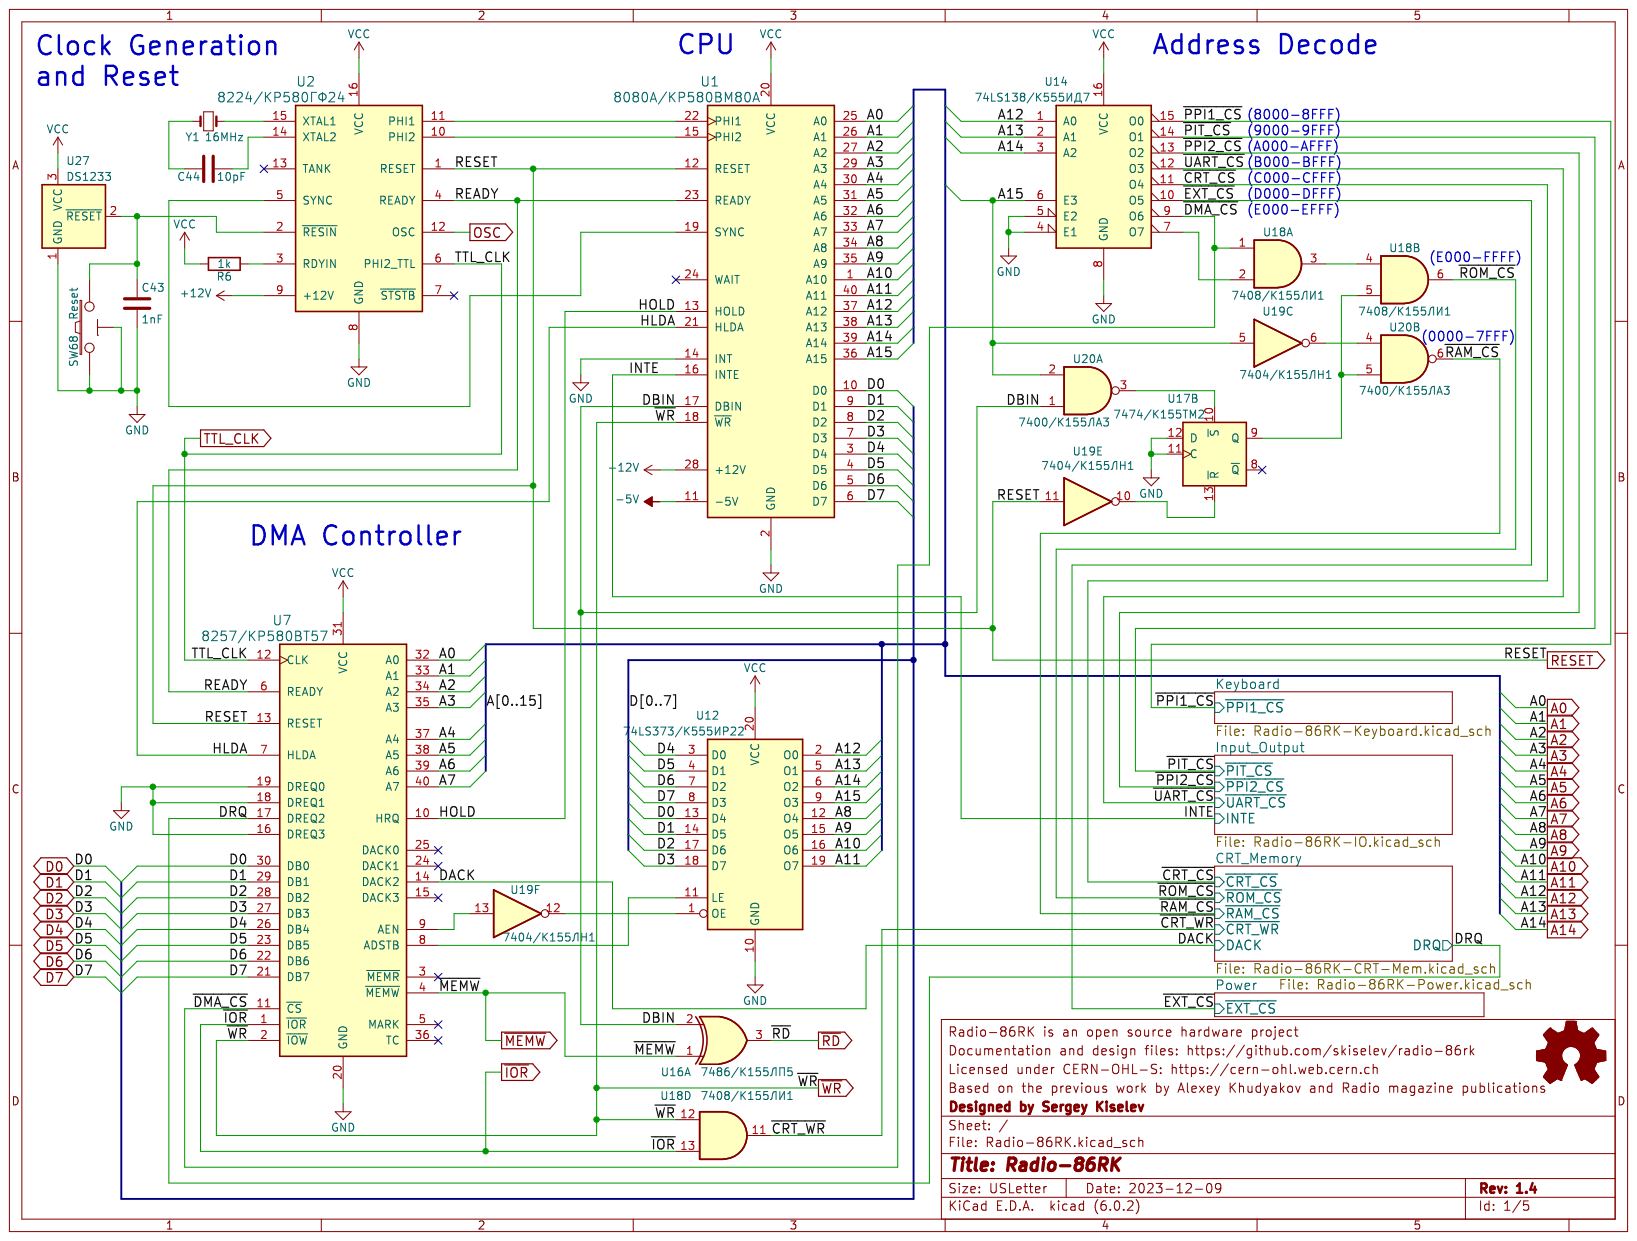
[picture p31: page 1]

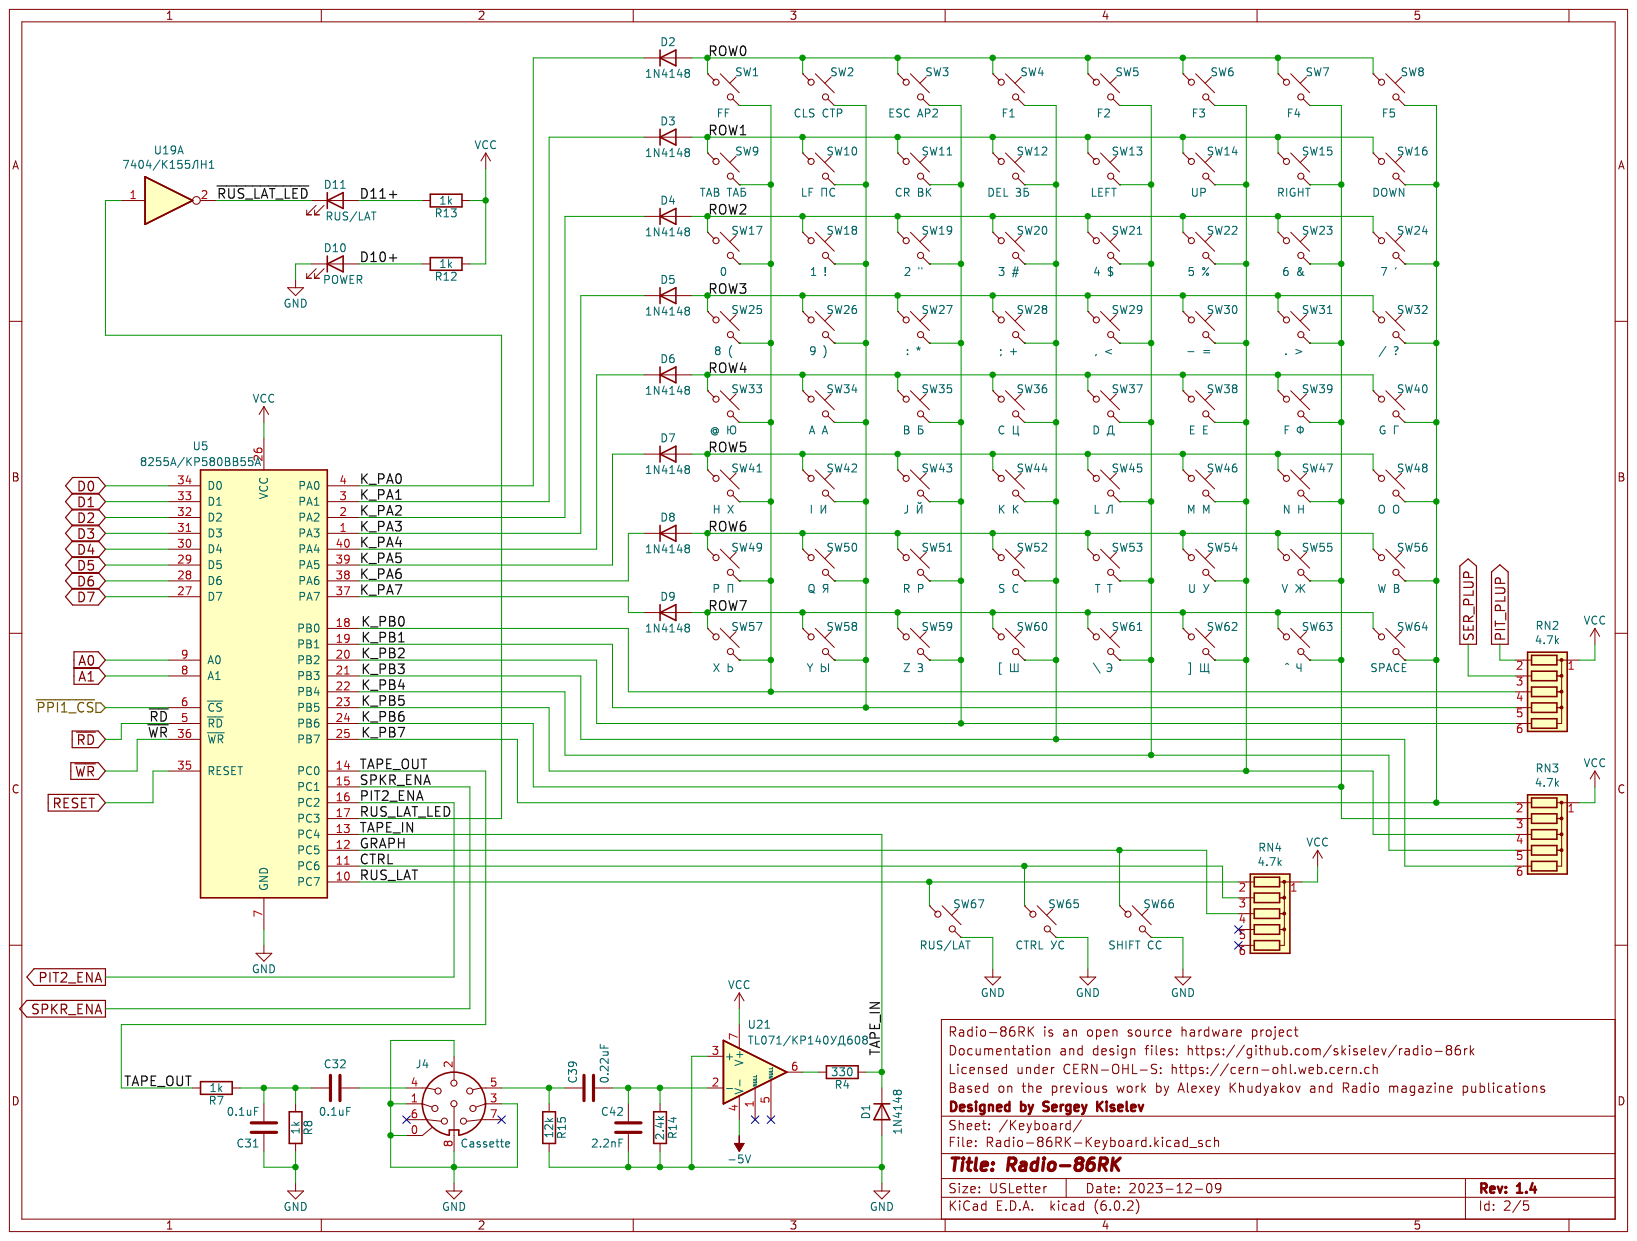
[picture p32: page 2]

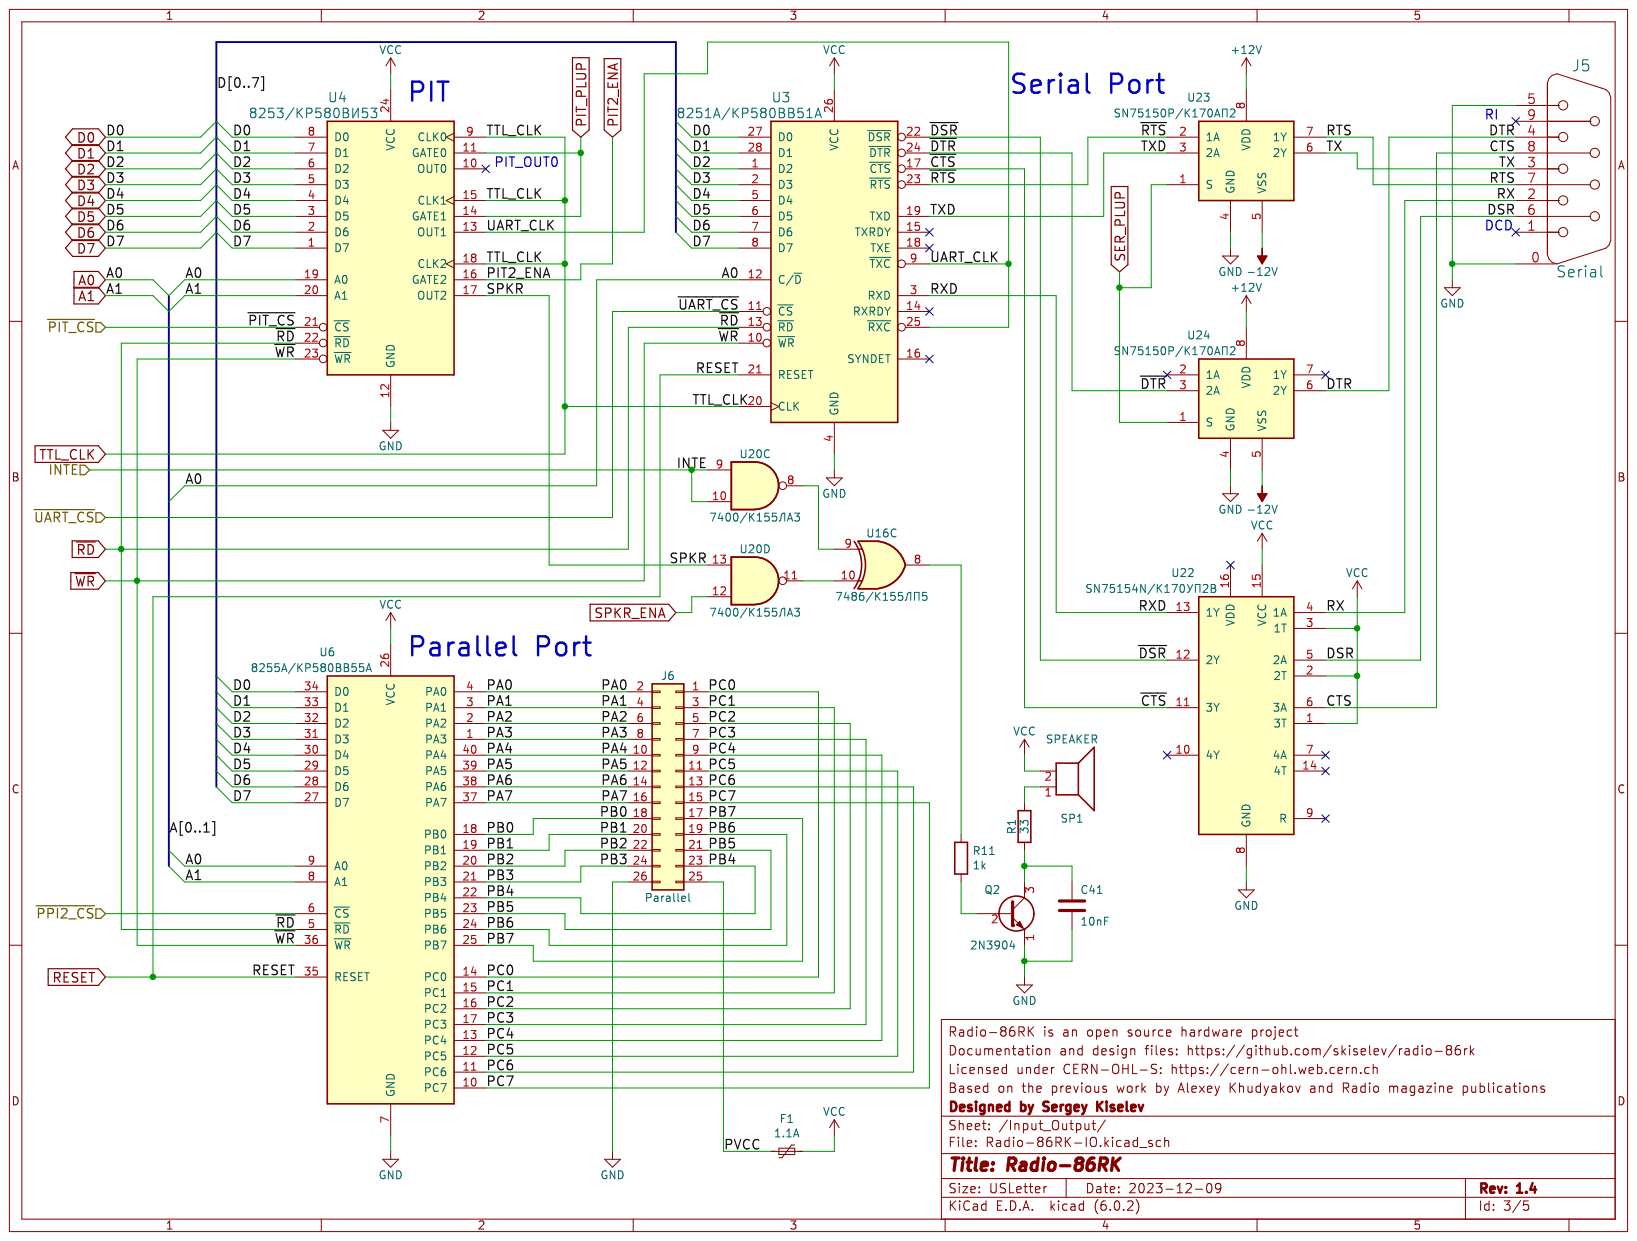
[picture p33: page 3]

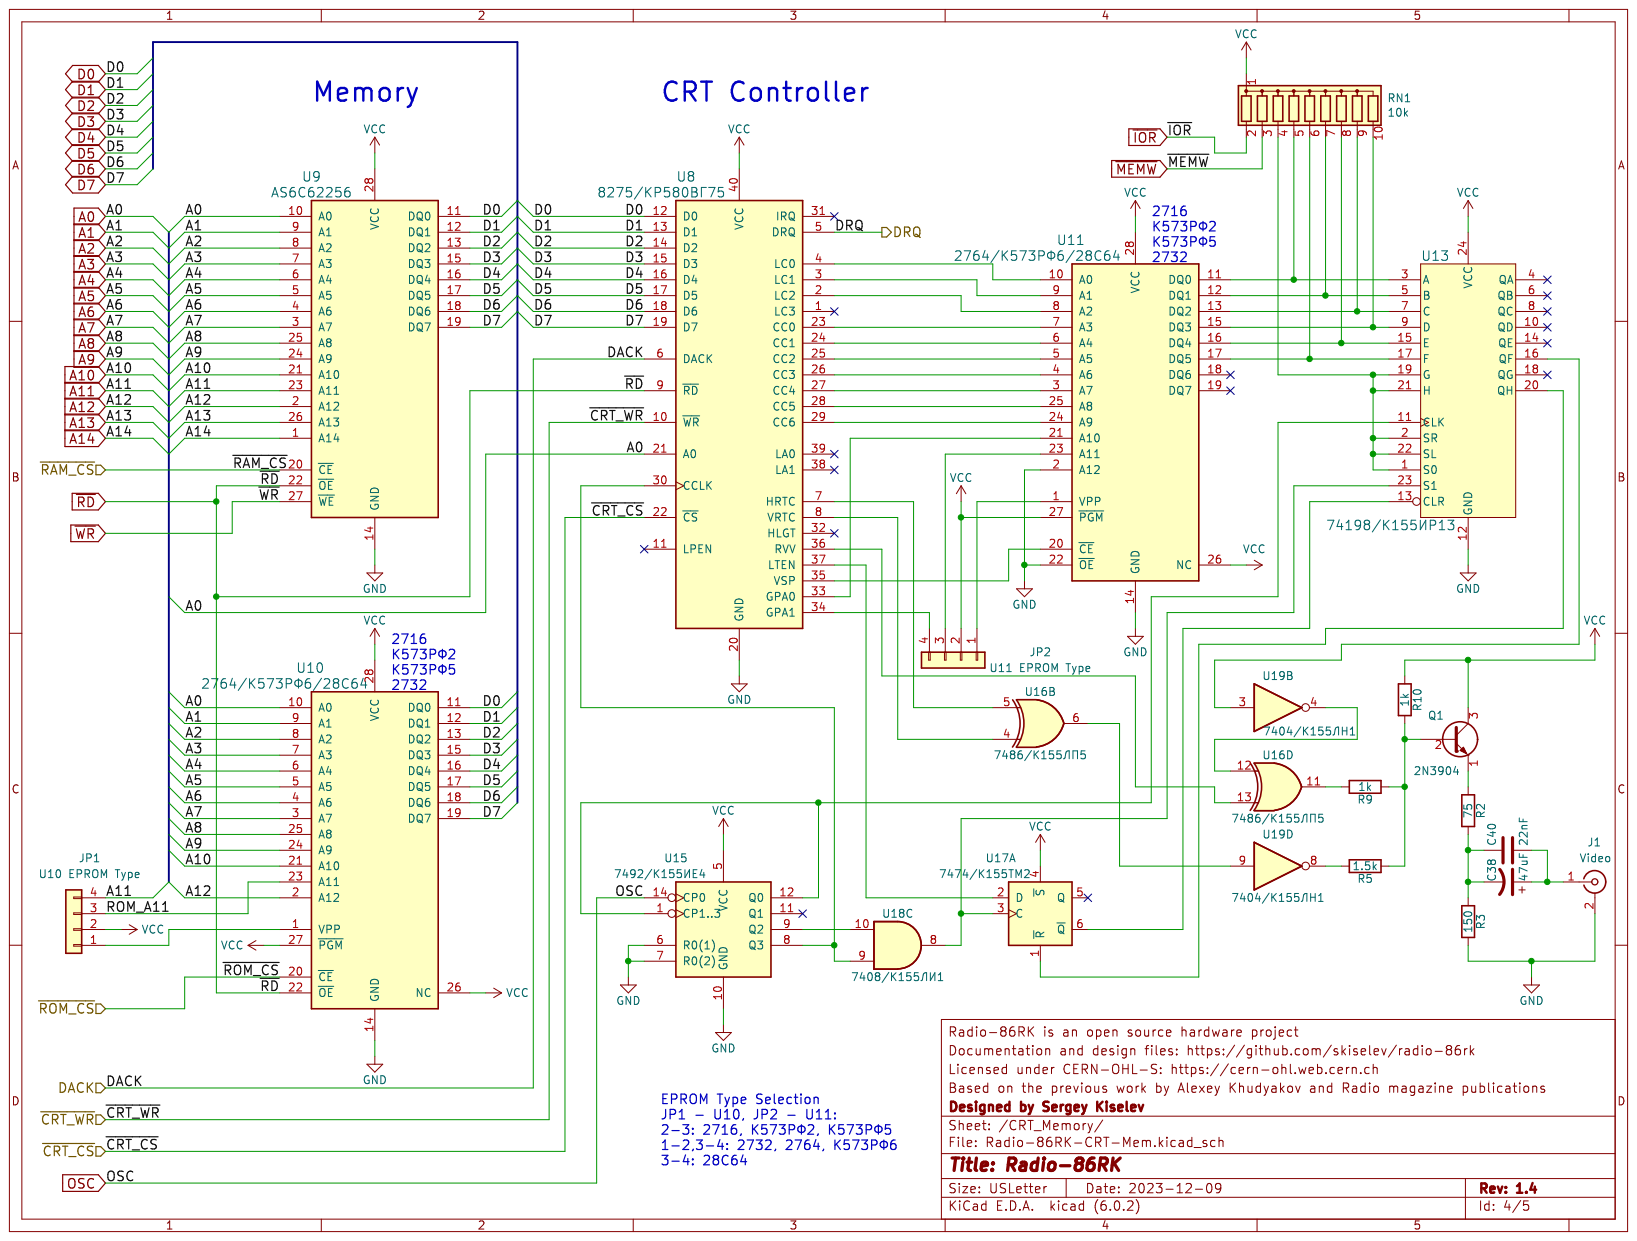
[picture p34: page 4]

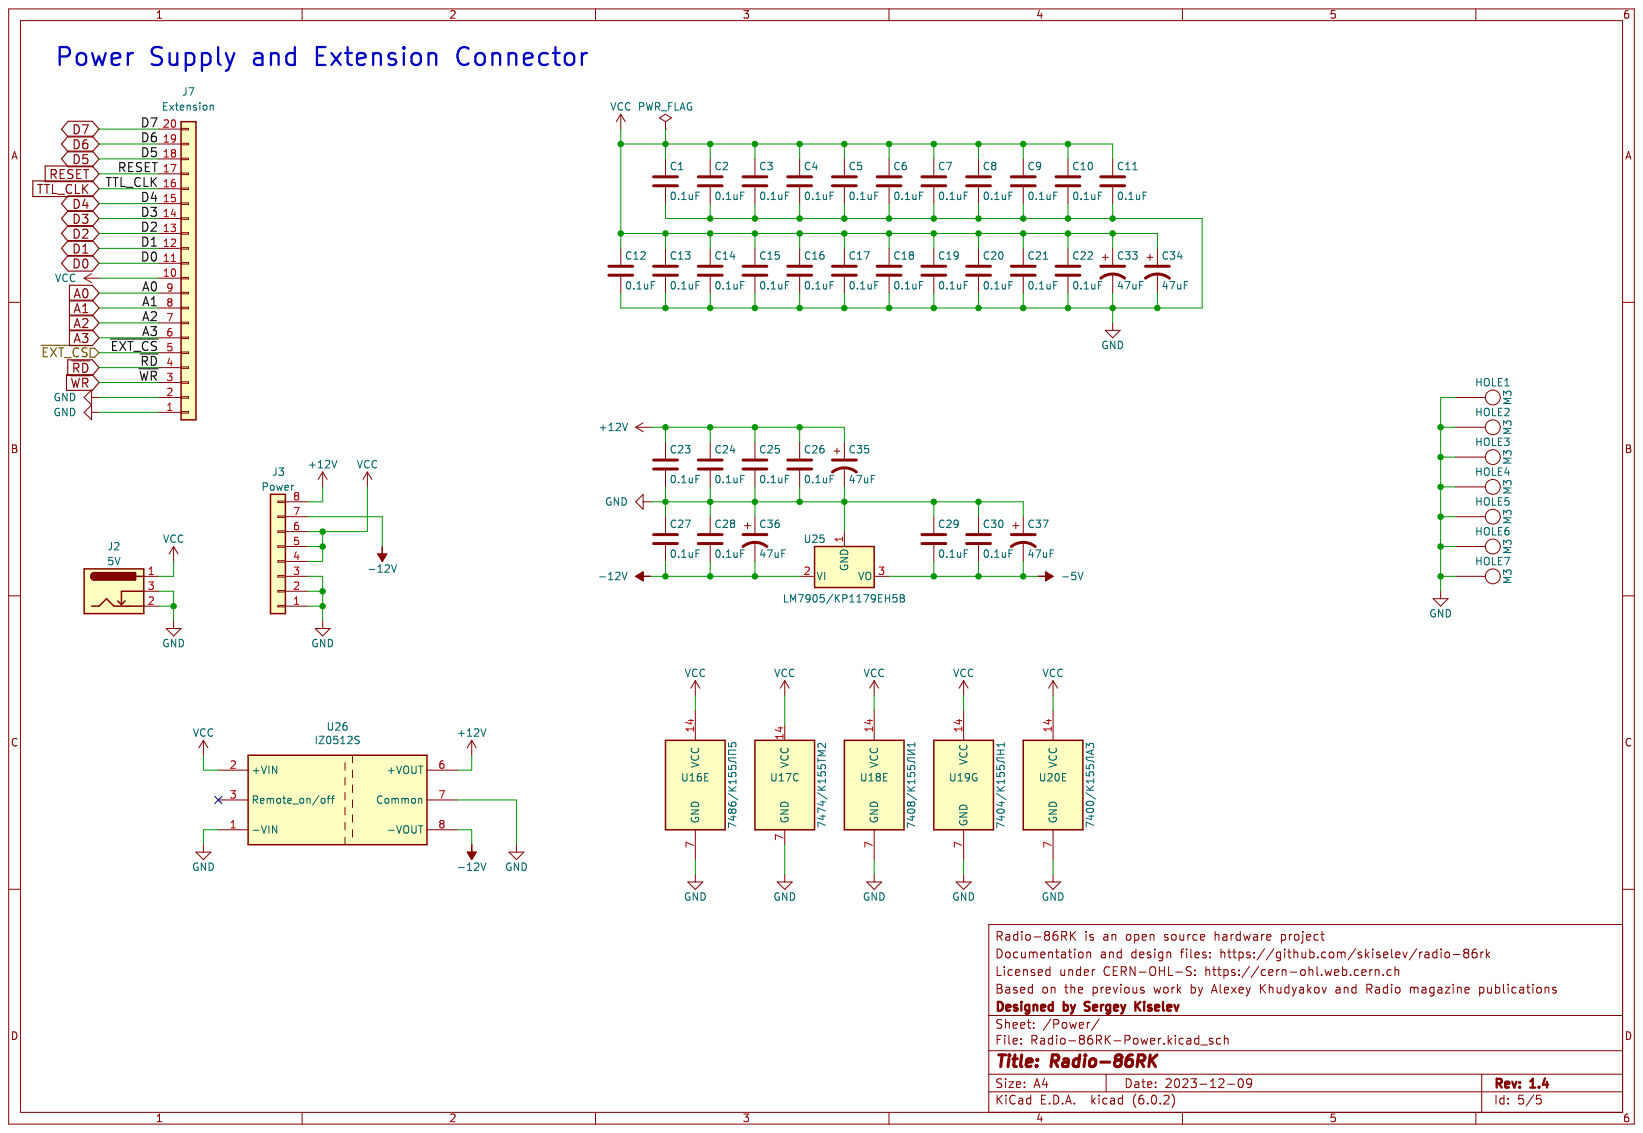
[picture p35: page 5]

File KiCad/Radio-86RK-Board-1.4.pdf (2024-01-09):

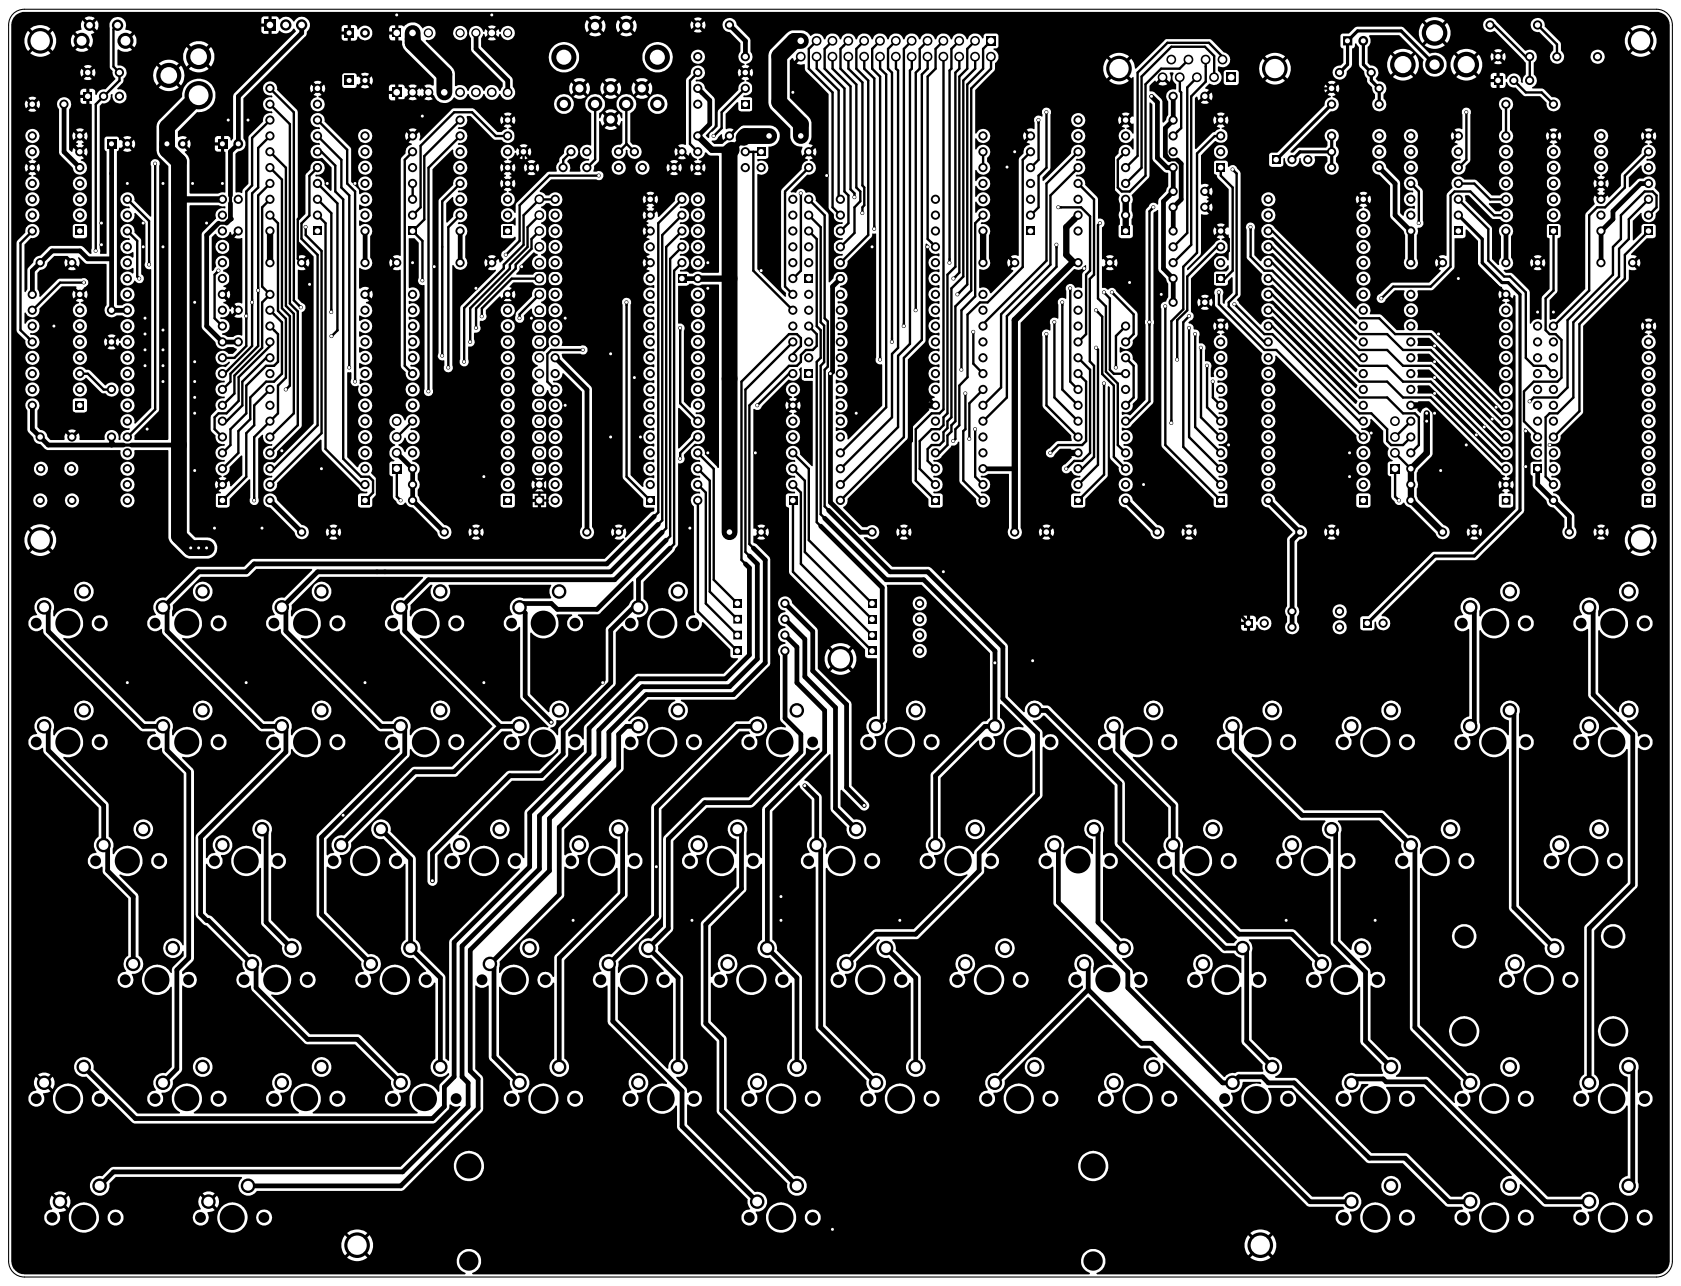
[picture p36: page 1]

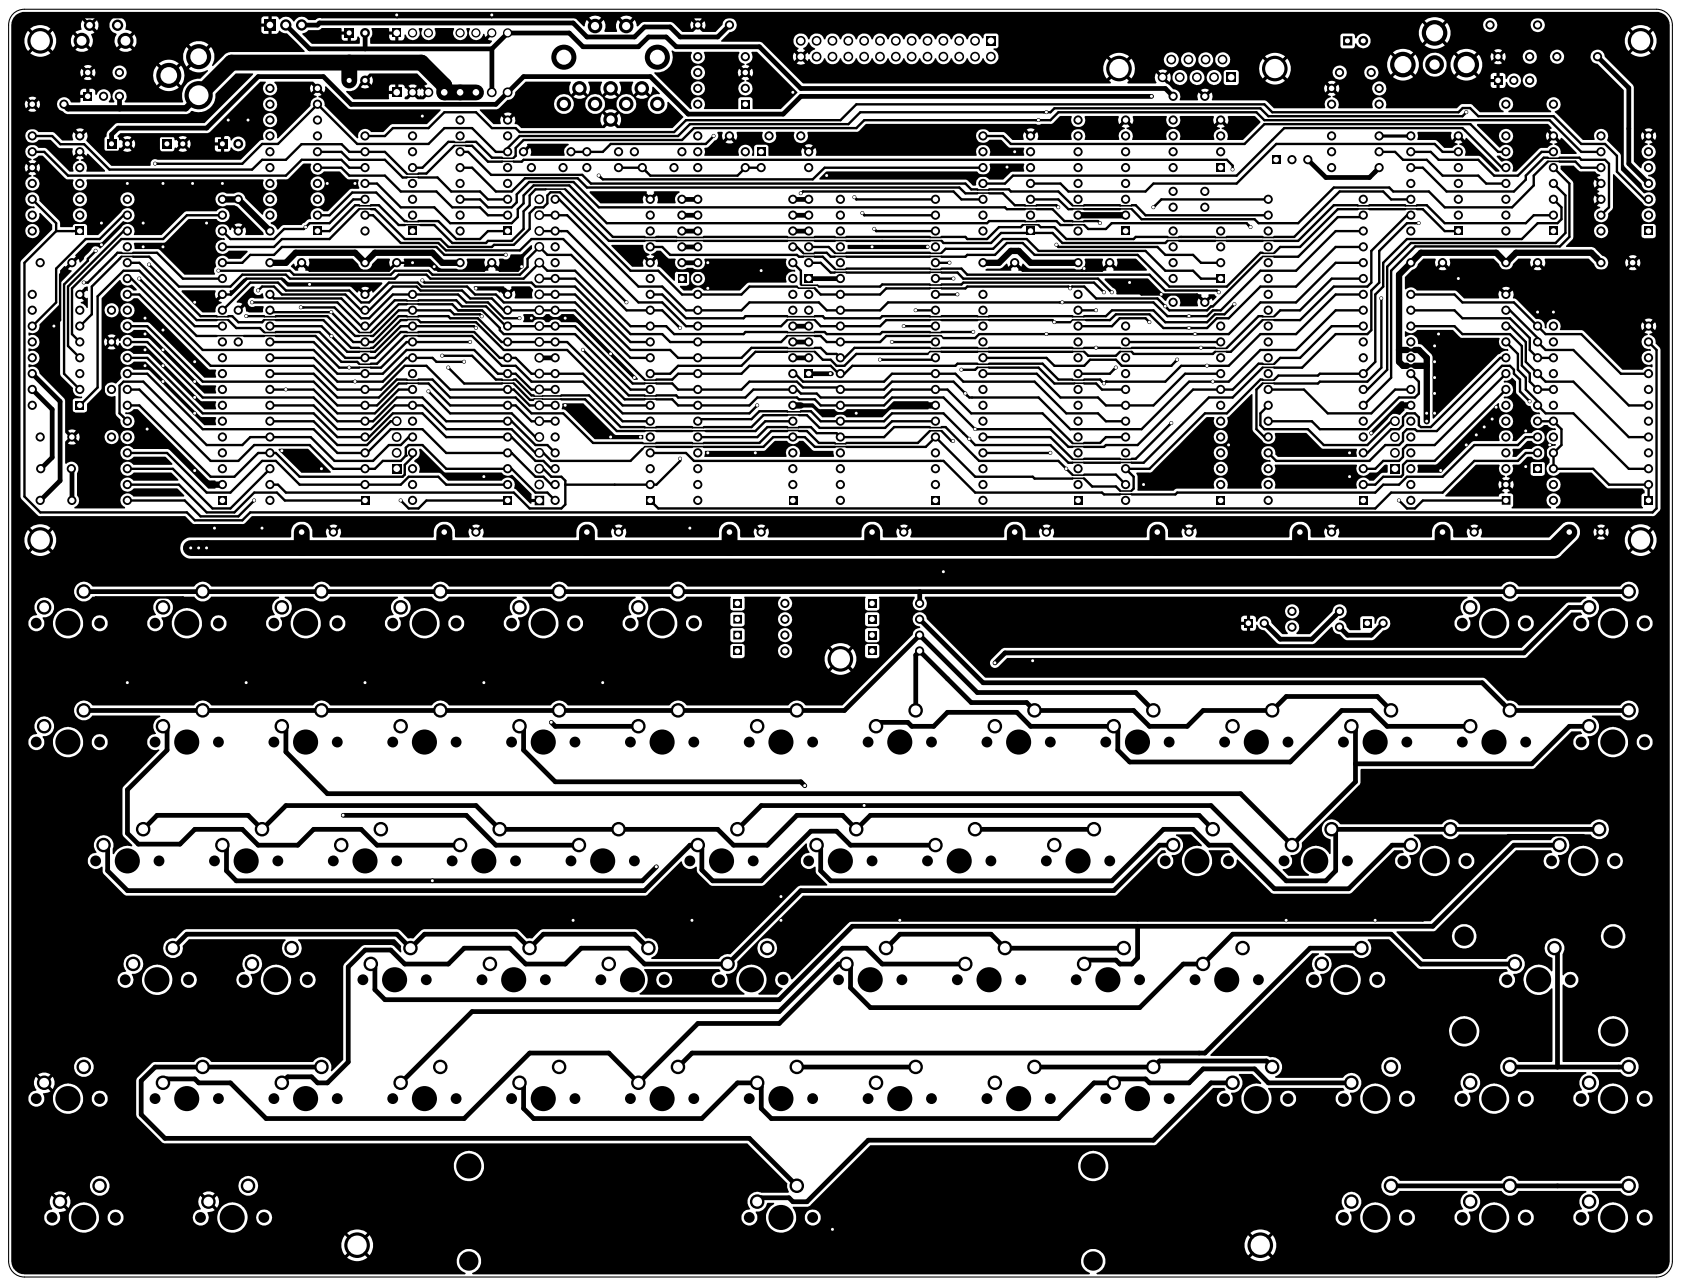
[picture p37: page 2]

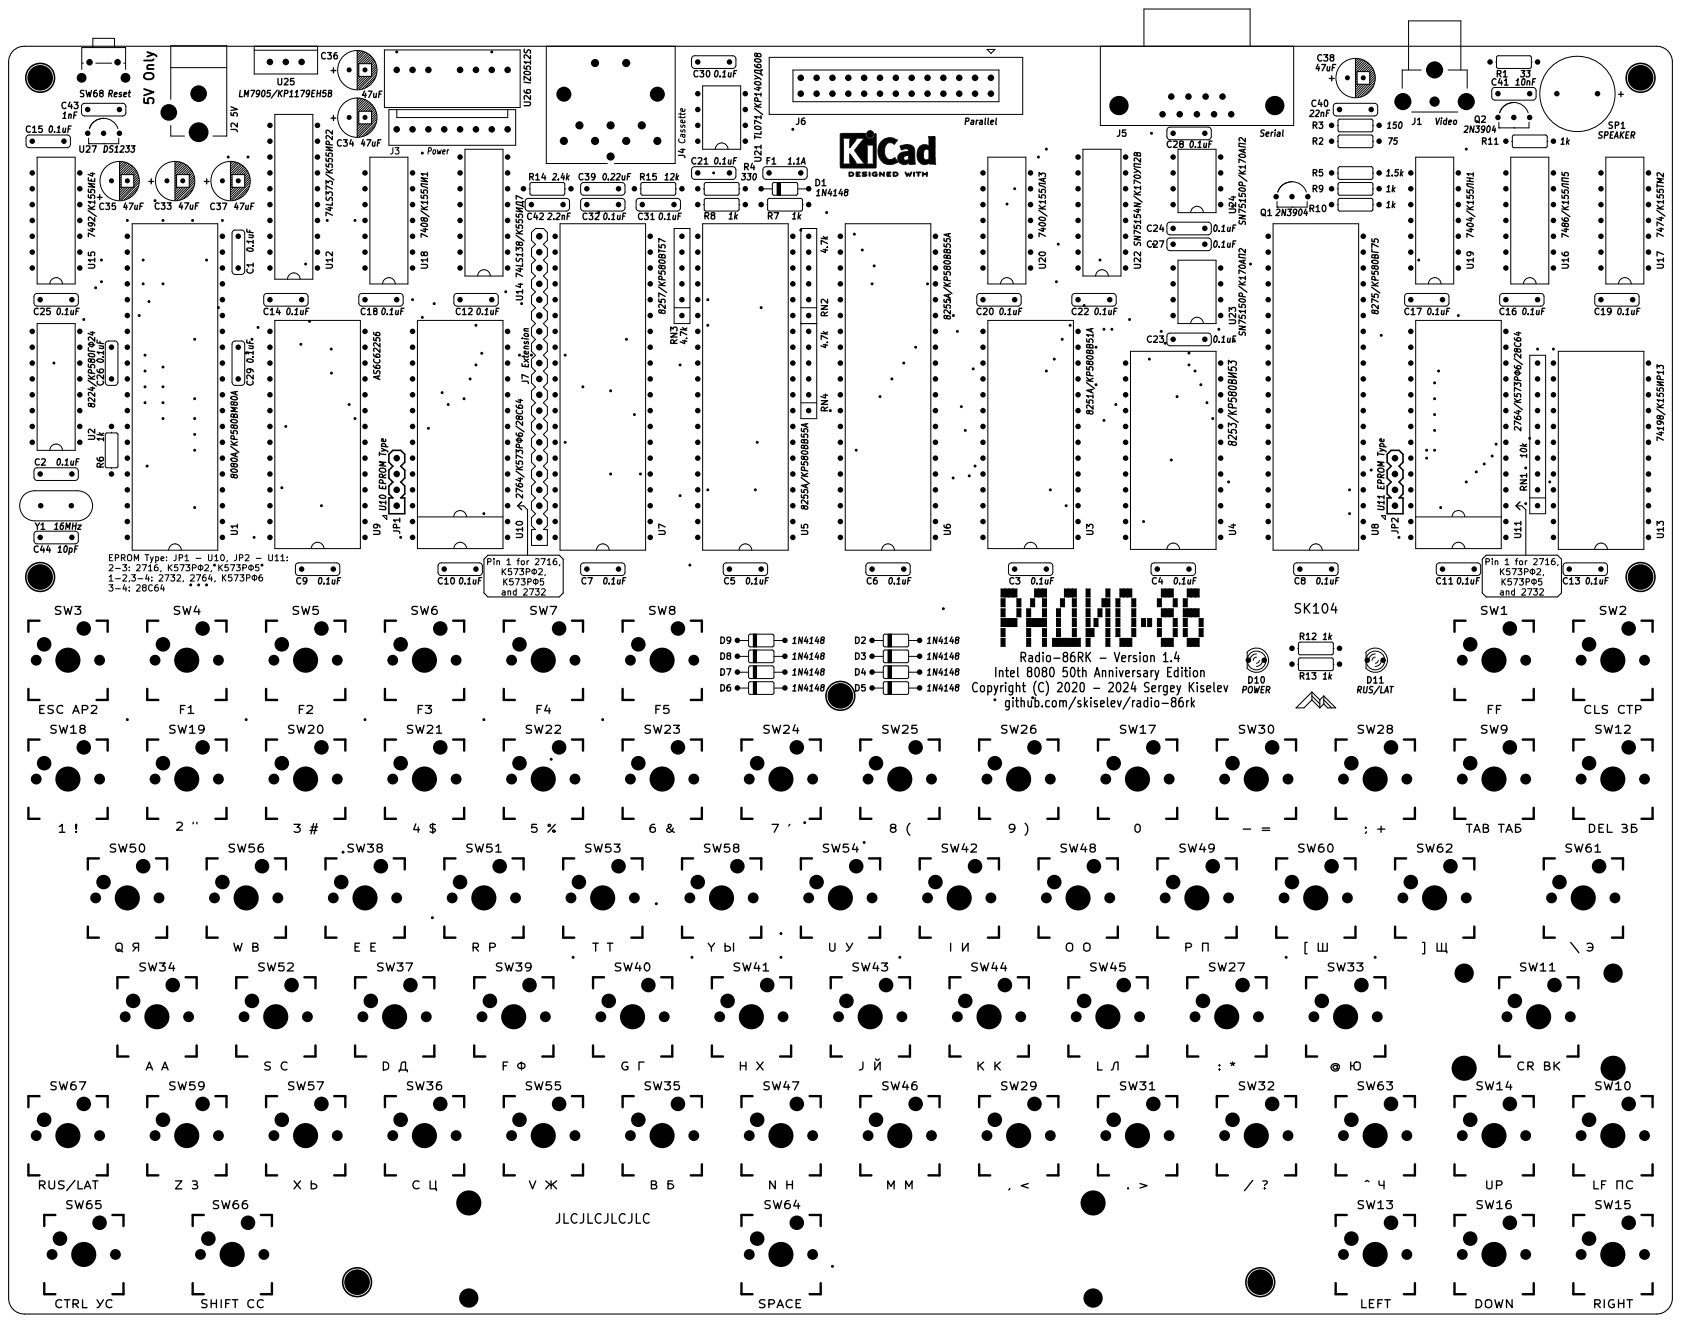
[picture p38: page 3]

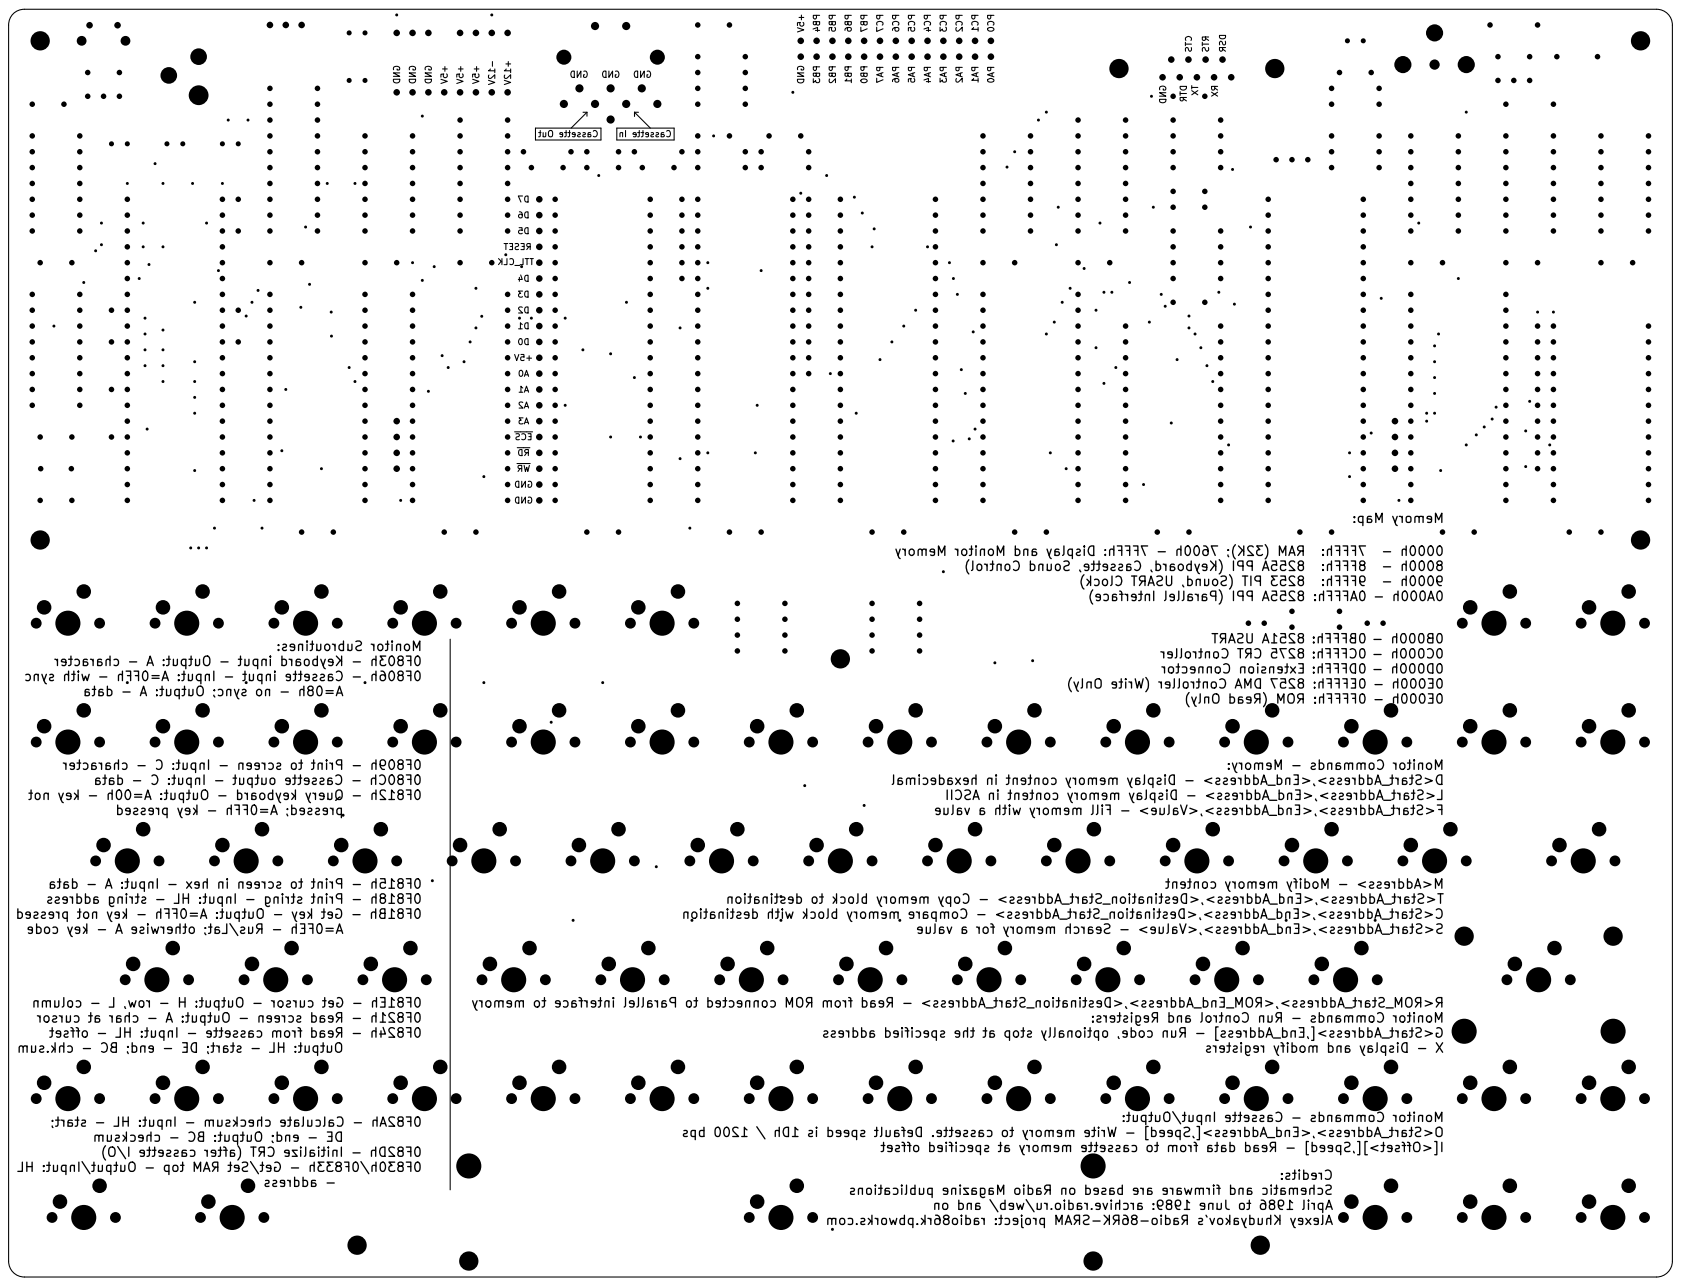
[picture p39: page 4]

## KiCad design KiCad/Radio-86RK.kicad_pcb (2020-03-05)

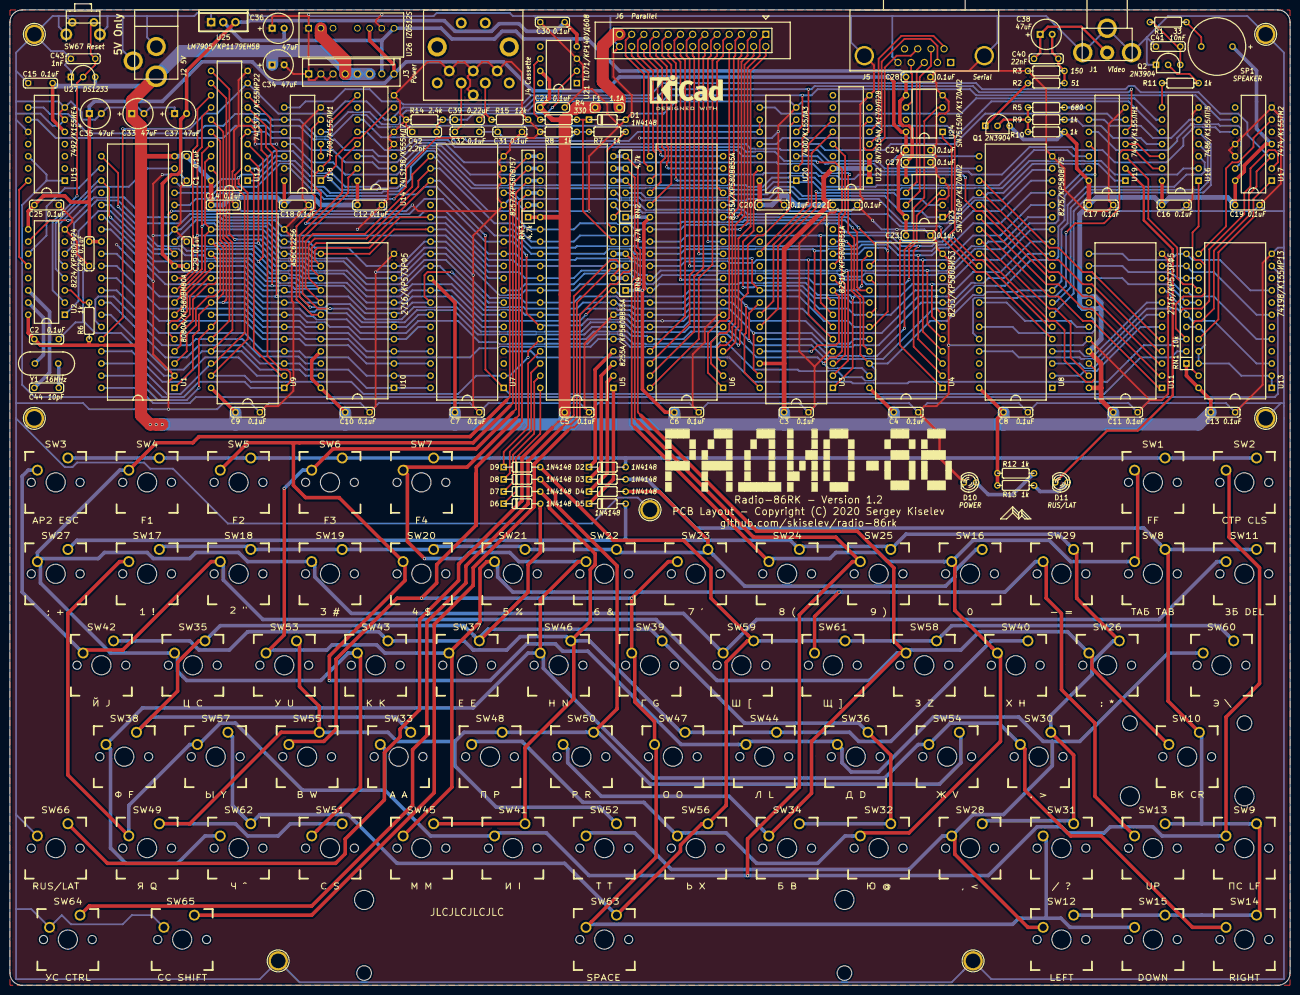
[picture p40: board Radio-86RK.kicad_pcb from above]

Board: 2 copper layers, 266.7 x 203.2 mm, 186 parts (0 on the bottom side), 194 nets.

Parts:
C1, C2, C3, C4, C5, C6, C7, C8, C9, C10, C11, C12, C13, C14, C15, C16, C17, C18, C19, C20, C21, C22, C23, C24, C25, C26, C27, C28, C29, C30, C31, C32: 0.1uF; Cap_Cer_508
C33, C34, C35, C36, C37, C38: 47uF; Cap_Elec_Radial_6.3mm
C39: 0.22uF; Cap_Cer_508
C40: 22nF; Cap_Cer_508
C41: 10nF; Cap_Cer_508
C42: 2.2nF; Cap_Cer_508
C43: 1nF; Cap_Cer_508
C44: 10pF; Cap_Cer_508
D1, D2, D3, D4, D5, D6, D7, D8, D9: 1N4148; Diode_762
D10: POWER; LED_3mm
D11: RUS/LAT; LED_3mm
F1: 1.1A; Cap_Cer_508
HOLE1, HOLE2, HOLE3, HOLE4, HOLE5, HOLE6, HOLE7: M3; Hole_3mm
J1: Video; Conn_RCA_Right
J2: 5V; Conn_Power_Jack_Circular_Pads
J3: Power; Conn_Friction_Lock_8P_2.54mm
J4: Cassette; Conn_DIN_8pin
J5: Serial; Conn_Dsub_DE9M
J6: Parallel; Conn_Pin_Header_13x2_2.54mm_Shrouded
Q1, Q2: 2N3904; Transistor_TO92_EBC_254
R1: 33; Res_762
R2: 51; Res_762
R3: 150; Res_762
R4: 330; Res_762
R5: 680; Res_762
R6, R7, R8, R9, R10, R11, R12, R13: 1k; Res_762
R14: 2.4k; Res_762
R15: 12k; Res_762
RN1: 10k; Conn_SIL10
RN2, RN3, RN4: 4.7k; Conn_SIL6
SP1: SPEAKER; Speaker_12mm
SW1: FF; CHERRY_PCB_100H
SW2: СТР CLS; CHERRY_PCB_100H
SW3: АР2 ESC; CHERRY_PCB_100H
SW4: F1; CHERRY_PCB_100H
SW5: F2; CHERRY_PCB_100H
SW6: F3; CHERRY_PCB_100H
SW7: F4; CHERRY_PCB_100H
SW8: ТАБ TAB; CHERRY_PCB_100H
SW9: ПС LF; CHERRY_PCB_100H
SW10: ВК CR; CHERRY_PCB_225H
SW11: ЗБ DEL; CHERRY_PCB_100H
SW12: LEFT; CHERRY_PCB_100H
SW13: UP; CHERRY_PCB_100H
SW14: RIGHT; CHERRY_PCB_100H
SW15: DOWN; CHERRY_PCB_100H
SW16: 0; CHERRY_PCB_100H
SW17: 1 !; CHERRY_PCB_100H
SW18: 2 "; CHERRY_PCB_100H
SW19: 3 #; CHERRY_PCB_100H
SW20: 4 $; CHERRY_PCB_100H
SW21: 5 %; CHERRY_PCB_100H
SW22: 6 &; CHERRY_PCB_100H
SW23: 7 '; CHERRY_PCB_100H
SW24: 8 (; CHERRY_PCB_100H
SW25: 9 ); CHERRY_PCB_100H
SW26: : *; CHERRY_PCB_100H
SW27: ; +; CHERRY_PCB_100H
SW28: , <; CHERRY_PCB_100H
SW29: - =; CHERRY_PCB_100H
SW30: . >; CHERRY_PCB_100H
SW31: / ?; CHERRY_PCB_100H
SW32: Ю @; CHERRY_PCB_100H
SW33: А A; CHERRY_PCB_100H
SW34: Б B; CHERRY_PCB_100H
SW35: Ц C; CHERRY_PCB_100H
SW36: Д D; CHERRY_PCB_100H
SW37: Е E; CHERRY_PCB_100H
SW38: Ф F; CHERRY_PCB_100H
SW39: Г G; CHERRY_PCB_100H
SW40: Х H; CHERRY_PCB_100H
SW41: И I; CHERRY_PCB_100H
SW42: Й J; CHERRY_PCB_100H
SW43: К K; CHERRY_PCB_100H
SW44: Л L; CHERRY_PCB_100H
SW45: М M; CHERRY_PCB_100H
SW46: Н N; CHERRY_PCB_100H
SW47: О O; CHERRY_PCB_100H
SW48: П P; CHERRY_PCB_100H
SW49: Я Q; CHERRY_PCB_100H
SW50: Р R; CHERRY_PCB_100H
SW51: С S; CHERRY_PCB_100H
SW52: Т T; CHERRY_PCB_100H
SW53: У U; CHERRY_PCB_100H
SW54: Ж V; CHERRY_PCB_100H
SW55: В W; CHERRY_PCB_100H
SW56: Ь X; CHERRY_PCB_100H
SW57: Ы Y; CHERRY_PCB_100H
SW58: З Z; CHERRY_PCB_100H
SW59: Ш [; CHERRY_PCB_100H
SW60: Э \; CHERRY_PCB_150H
SW61: Щ ]; CHERRY_PCB_100H
SW62: Ч ^; CHERRY_PCB_100H
SW63: SPACE; CHERRY_PCB_625H
SW64: УС CTRL; CHERRY_PCB_125H
SW65: CC SHIFT; CHERRY_PCB_125H
SW66: RUS/LAT; CHERRY_PCB_100H
SW67: Reset; Switch_Tactile_6mm_Right
U1: 8080A/КР580ВМ80А; IC_DIP40_600
U2: 8224/КР580ГФ24; IC_DIP16_300
U3: 8251A/КР580ВВ51А; IC_DIP28_600
U4: 8253/КР580ВИ53; IC_DIP24_600
U5, U6: 8255A/КР580ВВ55А; IC_DIP40_600
U7: 8257/КР580ВТ57; IC_DIP40_600
U8: 8275/КР580ВГ75; IC_DIP40_600
U9: AS6C62256; IC_DIP28_600
U10, U11: 2716/КР573РФ5; IC_DIP24_600
U12: 74LS373/К555ИР22; IC_DIP20_300
U13: 74198/К155ИР13; IC_DIP24_600
U14: 74LS138/К555ИД7; IC_DIP16_300
U15: 7492/К155ИЕ4; IC_DIP14_300
U16: 7486/К155ЛП5; IC_DIP14_300
U17: 7474/К155ТМ2; IC_DIP14_300
U18: 7408/К155ЛИ1; IC_DIP14_300
U19: 7404/К155ЛН1; IC_DIP14_300
U20: 7400/К155ЛА3; IC_DIP14_300
U21: TL071/КР140УД608; IC_DIP8_300
U22: SN75154N/К170УП2В; IC_DIP16_300
U23, U24: SN75150P/К170АП2; IC_DIP8_300
U25: LM7905/КР1179ЕН5В; IC_TO220-3_Vert
U26: IZ0512S; DC-DC_SIP8
U27: DS1233; Transistor_TO92_EBC_254
Y1: 16MHz; Crystal_HC-49U_Vert

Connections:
+12V: C23.1, C24.1, C25.1, C26.1, C35.1, J3.8, U1.28, U2.9, U23.8, U24.8, U26.6
-5V: C29.2, C30.2, C37.2, U1.11, U21.4, U25.3
-12V: C27.2, C28.2, C36.2, J3.7, U23.5, U24.5, U25.2, U26.8
/A15: U1.36, U12.9, U14.6, U19.5, U20.2
/DACK: U7.14, U8.6
/DBIN: U1.17, U16.2, U20.1
/DRQ: U7.17, U8.5
/HLDA: U1.21, U7.7
/HOLD: U1.13, U7.10
/INTE: U1.16, U20.9, U20.10
/Input_Output/CTS: J5.8, U22.6
/Input_Output/DSR: J5.6, U22.5
/Input_Output/DTR: J5.4, U24.6
/Input_Output/PA0: J6.2, U6.4
/Input_Output/PA1: J6.4, U6.3
/Input_Output/PA2: J6.6, U6.2
/Input_Output/PA3: J6.8, U6.1
/Input_Output/PA4: J6.10, U6.40
/Input_Output/PA5: J6.12, U6.39
/Input_Output/PA6: J6.14, U6.38
/Input_Output/PA7: J6.16, U6.37
/Input_Output/PB0: J6.18, U6.18
/Input_Output/PB1: J6.20, U6.19
/Input_Output/PB2: J6.22, U6.20
/Input_Output/PB3: J6.24, U6.21
/Input_Output/PB4: J6.23, U6.22
/Input_Output/PB5: J6.21, U6.23
/Input_Output/PB6: J6.19, U6.24
/Input_Output/PB7: J6.17, U6.25
/Input_Output/PC0: J6.1, U6.14
/Input_Output/PC1: J6.3, U6.15
/Input_Output/PC2: J6.5, U6.16
/Input_Output/PC3: J6.7, U6.17
/Input_Output/PC4: J6.9, U6.13
/Input_Output/PC5: J6.11, U6.12
/Input_Output/PC6: J6.13, U6.11
/Input_Output/PC7: J6.15, U6.10
/Input_Output/PVCC: F1.2, J6.25
/Input_Output/RTS: J5.7, U23.7
/Input_Output/RX: J5.2, U22.4
/Input_Output/RXD: U3.3, U22.13
/Input_Output/SPKR: U4.17, U20.13
/Input_Output/TX: J5.3, U23.6
/Input_Output/TXD: U3.19, U23.3
/Input_Output/UART_CLK: U3.9, U3.25, U4.13
/Input_Output/~CTS: U3.17, U22.11
/Input_Output/~DSR: U3.22, U22.12
/Input_Output/~DTR: U3.24, U24.3
/Input_Output/~RTS: U3.23, U23.2
/Keyboard/CTRL: RN4.3, SW64.1, U5.11
/Keyboard/D10+: D10.2, R12.2
/Keyboard/D11+: D11.2, R13.2
/Keyboard/GRAPH: RN4.4, SW65.1, U5.12
/Keyboard/K_PA0: D2.1, U5.4
/Keyboard/K_PA1: D3.1, U5.3
/Keyboard/K_PA2: D4.1, U5.2
/Keyboard/K_PA3: D5.1, U5.1
/Keyboard/K_PA4: D6.1, U5.40
/Keyboard/K_PA5: D7.1, U5.39
/Keyboard/K_PA6: D8.1, U5.38
/Keyboard/K_PA7: D9.1, U5.37
/Keyboard/K_PB0: RN2.4, SW1.2, SW8.2, SW16.2, SW24.2, SW32.2, SW40.2, SW48.2, SW56.2, U5.18
/Keyboard/K_PB1: RN2.5, SW2.2, SW9.2, SW17.2, SW25.2, SW33.2, SW41.2, SW49.2, SW57.2, U5.19
/Keyboard/K_PB2: RN2.6, SW3.2, SW10.2, SW18.2, SW26.2, SW34.2, SW42.2, SW50.2, SW58.2, U5.20
/Keyboard/K_PB3: RN3.6, SW4.2, SW11.2, SW19.2, SW27.2, SW35.2, SW43.2, SW51.2, SW59.2, U5.21
/Keyboard/K_PB4: RN3.5, SW5.2, SW12.2, SW20.2, SW28.2, SW36.2, SW44.2, SW52.2, SW60.2, U5.22
/Keyboard/K_PB5: RN3.4, SW6.2, SW13.2, SW21.2, SW29.2, SW37.2, SW45.2, SW53.2, SW61.2, U5.23
/Keyboard/K_PB6: RN3.3, SW7.2, SW14.2, SW22.2, SW30.2, SW38.2, SW46.2, SW54.2, SW62.2, U5.24
/Keyboard/K_PB7: RN3.2, SW15.2, SW23.2, SW31.2, SW39.2, SW47.2, SW55.2, SW63.2, U5.25
/Keyboard/ROW0: D2.2, SW1.1, SW2.1, SW3.1, SW4.1, SW5.1, SW6.1, SW7.1
/Keyboard/ROW1: D3.2, SW8.1, SW9.1, SW10.1, SW11.1, SW12.1, SW13.1, SW14.1, SW15.1
/Keyboard/ROW2: D4.2, SW16.1, SW17.1, SW18.1, SW19.1, SW20.1, SW21.1, SW22.1, SW23.1
/Keyboard/ROW3: D5.2, SW24.1, SW25.1, SW26.1, SW27.1, SW28.1, SW29.1, SW30.1, SW31.1
/Keyboard/ROW4: D6.2, SW32.1, SW33.1, SW34.1, SW35.1, SW36.1, SW37.1, SW38.1, SW39.1
/Keyboard/ROW5: D7.2, SW40.1, SW41.1, SW42.1, SW43.1, SW44.1, SW45.1, SW46.1, SW47.1
/Keyboard/ROW6: D8.2, SW48.1, SW49.1, SW50.1, SW51.1, SW52.1, SW53.1, SW54.1, SW55.1
/Keyboard/ROW7: D9.2, SW56.1, SW57.1, SW58.1, SW59.1, SW60.1, SW61.1, SW62.1, SW63.1
/Keyboard/RUS_LAT: RN4.2, SW66.1, U5.10
/Keyboard/RUS_LAT_LED: U5.17, U19.1
/Keyboard/TAPE_IN: D1.1, R4.1, U5.13
/Keyboard/TAPE_OUT: R7.2, U5.14
/Keyboard/~RUS_LAT_LED: D11.1, U19.2
/READY: U1.23, U2.4, U7.6
/~CRT_CS: U8.22, U14.11
/~CRT_WR: U8.10, U18.11
/~DMA_CS: U7.11, U14.9, U18.2
/~PIT_CS: U4.21, U14.14
/~PPI1_CS: U5.6, U14.15
/~PPI2_CS: U6.6, U14.13
/~RAM_CS: U9.20, U20.6
/~ROM_CS: U10.18, U18.6
/~UART_CS: U3.11, U14.12
A0: U1.25, U3.12, U4.19, U5.9, U6.9, U7.32, U8.21, U9.10, U10.8
A1: U1.26, U4.20, U5.8, U6.8, U7.33, U9.9, U10.7
A2: U1.27, U7.34, U9.8, U10.6
A3: U1.29, U7.35, U9.7, U10.5
A4: U1.30, U7.37, U9.6, U10.4
A5: U1.31, U7.38, U9.5, U10.3
A6: U1.32, U7.39, U9.4, U10.2
A7: U1.33, U7.40, U9.3, U10.1
A8: U1.34, U9.25, U10.23, U12.12
A9: U1.35, U9.24, U10.22, U12.15
A10: U1.1, U9.21, U10.19, U12.16
A11: U1.40, U9.23, U12.19
A12: U1.37, U9.2, U12.2, U14.1
A13: U1.38, U9.26, U12.5, U14.2
A14: U1.39, U9.1, U12.6, U14.3
D0: U1.10, U3.27, U4.8, U5.34, U6.34, U7.30, U8.12, U9.11, U10.9, U12.13
D1: U1.9, U3.28, U4.7, U5.33, U6.33, U7.29, U8.13, U9.12, U10.10, U12.14
D2: U1.8, U3.1, U4.6, U5.32, U6.32, U7.28, U8.14, U9.13, U10.11, U12.17
D3: U1.7, U3.2, U4.5, U5.31, U6.31, U7.27, U8.15, U9.15, U10.13, U12.18
D4: U1.3, U3.5, U4.4, U5.30, U6.30, U7.26, U8.16, U9.16, U10.14, U12.3
D5: U1.4, U3.6, U4.3, U5.29, U6.29, U7.23, U8.17, U9.17, U10.15, U12.4
D6: U1.5, U3.7, U4.2, U5.28, U6.28, U7.22, U8.18, U9.18, U10.16, U12.7
D7: U1.6, U3.8, U4.1, U5.27, U6.27, U7.21, U8.19, U9.19, U10.17, U12.8
GND: C1.2, C2.2, C3.2, C4.2, C5.2, C6.2, C7.2, C8.2, C9.2, C10.2, C11.2, C12.2, C13.2, C14.2, C15.2, C16.2, C17.2, C18.2, C19.2, C20.2, C21.2, C22.2, C23.2, C24.2, C25.2, C26.2, C27.1, C28.1, C29.1, C30.1, C31.1, C33.2, C34.2, C35.2, C36.1, C37.1, C41.2, C42.2, C43.2, D1.2, D10.1, HOLE1.1, HOLE2.1, HOLE3.1, HOLE4.1, HOLE5.1, HOLE6.1, HOLE7.1, J1.2, J2.2, J2.3, J3.1, J3.2, J3.3, J4.1, J4.2, J4.3, J4.8, J5.5, J5.GND, J6.26, Q2.1, R3.2, R8.2, R14.2, R15.2, SW64.2, SW65.2, SW66.2, SW67.2, SW67.GND, U1.2, U1.14, U2.8, U3.4, U4.12, U5.7, U6.7, U7.16, U7.18, U7.19, U7.20, U8.20, U9.14, U10.12, U11.12, U11.20, U12.10, U13.12, U14.4, U14.5, U14.8, U15.6, U15.7, U15.10, U16.7, U17.7, U17.11, U17.12, U18.7, U19.7, U20.7, U21.3, U22.8, U23.4, U24.4, U25.1, U26.1, U26.7, U27.1
unnamed: C31.2, C32.2, R7.1, R8.1
unnamed: C32.1, J4.4
unnamed: C38.1, C40.2, J1.1
unnamed: C38.2, C40.1, R2.2, R3.1
unnamed: C39.1, J4.5, R15.1
unnamed: C39.2, C42.1, R14.1, U21.2
unnamed: C41.1, Q2.3, R1.1
unnamed: C43.1, SW67.1, U2.2, U27.2
unnamed: C44.1, U2.14
unnamed: C44.2, Y1.1
unnamed: Q1.1, R2.1
unnamed: Q1.2, R5.1, R9.1, R10.2
unnamed: Q2.2, R11.2
unnamed: R1.2, SP1.1
unnamed: R4.2, U21.6
unnamed: R5.2, U19.8
unnamed: R6.1, U2.3
unnamed: R9.2, U16.11
unnamed: R11.1, U16.8
unnamed: RN1.4, U13.1, U13.2, U13.19, U13.21, U13.22
unnamed: RN1.5, U11.9, U13.3
unnamed: RN1.6, U11.15, U13.17
unnamed: RN1.7, U11.10, U13.5
unnamed: RN1.8, U11.14, U13.15
unnamed: RN1.9, U11.11, U13.7
unnamed: RN1.10, U11.13, U13.9
unnamed: U1.15, U2.10
unnamed: U1.19, U2.5
unnamed: U1.22, U2.11
unnamed: U2.15, Y1.2
unnamed: U8.27, U11.1
unnamed: U8.26, U11.2
unnamed: U8.25, U11.3
unnamed: U8.24, U11.4
unnamed: U8.23, U11.5
unnamed: U8.2, U11.6
unnamed: U8.3, U11.7
unnamed: U8.4, U11.8
unnamed: U8.35, U11.18
unnamed: U8.33, U11.19
unnamed: U8.29, U11.22
unnamed: U8.28, U11.23
unnamed: U12.1, U19.12
unnamed: U7.8, U12.11
unnamed: U13.11, U15.1, U15.12
unnamed: U13.13, U17.6
unnamed: U13.16, U19.3
unnamed: U13.20, U17.1
unnamed: U13.23, U17.3, U18.8
unnamed: U14.7, U18.1
unnamed: U8.30, U15.8, U18.9
unnamed: U15.9, U18.10
unnamed: U8.8, U16.4
unnamed: U8.7, U16.5
unnamed: U16.6, U19.9
unnamed: U16.9, U20.8
unnamed: U16.10, U20.11
unnamed: U16.12, U19.4
unnamed: U8.36, U16.13
unnamed: U8.37, U17.2
unnamed: U17.9, U18.5, U20.5
unnamed: U17.10, U20.3
unnamed: U17.13, U19.10
unnamed: U18.3, U18.4
unnamed: U19.6, U20.4
unnamed: U7.9, U19.13
OSC: U2.12, U15.14
PIT2_ENA: U4.16, U5.16
PIT_PLUP: RN2.2, U4.11, U4.14
RESET: U1.12, U2.1, U3.21, U5.35, U6.35, U7.13, U19.11
SER_PLUP: RN2.3, U23.1, U24.1
SPKR_ENA: U5.15, U20.12
TTL_CLK: U2.6, U3.20, U4.9, U4.15, U4.18, U7.12
VCC: C1.1, C2.1, C3.1, C4.1, C5.1, C6.1, C7.1, C8.1, C9.1, C10.1, C11.1, C12.1, C13.1, C14.1, C15.1, C16.1, C17.1, C18.1, C19.1, C20.1, C21.1, C22.1, C33.1, C34.1, F1.1, J2.1, J3.4, J3.5, J3.6, Q1.3, R6.2, R10.1, R12.1, R13.1, RN1.1, RN2.1, RN3.1, RN4.1, SP1.2, U1.20, U2.16, U3.26, U4.24, U5.26, U6.26, U7.31, U8.40, U9.28, U10.21, U10.24, U11.21, U11.24, U12.20, U13.24, U14.16, U15.5, U16.14, U17.4, U17.14, U18.14, U19.14, U20.14, U21.7, U22.1, U22.2, U22.3, U22.15, U26.2, U27.3
~IOR: RN1.2, U7.1, U18.13
~MEMW: RN1.3, U7.4, U16.1
~RD: U3.13, U4.22, U5.5, U6.5, U8.9, U9.22, U10.20, U16.3
~WR: U1.18, U3.10, U4.23, U5.36, U6.36, U7.2, U9.27, U18.12

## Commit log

2020-01-26 README: Initial version, Bill of Materials
2020-01-26 README: Fix cut and paste error
2020-01-29 Add KiCad and Gerber files for v1.0
    [Radio-86RK-CRT-Mem.sch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]
2020-02-21 Change 8224 package to DIP16; Swap Down/Right keys; Fix U21 soviet designation
    [Radio-86RK-Keyboard.sch, Radio-86RK.kicad_pcb, Radio-86RK.sch]
2020-02-21 Fill zones on the PCB
    [Radio-86RK.kicad_pcb]
2020-02-21 Use DS1233 for reset
    [Radio-86RK-CRT-Mem.sch, Radio-86RK.kicad_pcb, Radio-86RK.sch]
2020-02-22 Implement inverse video
    [Radio-86RK-CRT-Mem.sch, Radio-86RK.kicad_pcb]
2020-02-25 Update design files to v1.1
    [Radio-86RK-CRT-Mem.sch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]
2020-02-25 Update BOM for v1.1
2020-02-28 Fix issues on the front silkscreen
    [Radio-86RK-B_Cu.gbr, Radio-86RK-B_Mask.gbr, Radio-86RK-B_SilkS.gbr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]
2020-03-05 Minor silkscreen update: Move U2 value
    [Radio-86RK-B_Cu.gbr, Radio-86RK-B_Mask.gbr, Radio-86RK-B_SilkS.gbr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]
2022-05-13 add files for v1.2
    [Radio-86RK-CRT-Mem.kicad_sch, Radio-86RK-CRT-Mem.sch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]
2022-05-13 Updates for version v1.3: Update silkscreen and resistors values in video generation circuit
    [Radio-86RK-CRT-Mem.kicad_sch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]
2022-06-14 README: Update resistors and resistor arrays part numbers
2024-01-09 Add Version 1.4 files
    [Radio-86RK-CRT-Mem.kicad_sch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]

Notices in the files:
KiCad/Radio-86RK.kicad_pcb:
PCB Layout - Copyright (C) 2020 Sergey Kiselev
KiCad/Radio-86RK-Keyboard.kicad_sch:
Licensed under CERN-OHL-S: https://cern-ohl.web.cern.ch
